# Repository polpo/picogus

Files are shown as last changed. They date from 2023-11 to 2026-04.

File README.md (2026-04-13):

# PicoGUS

PicoGUS Logo



ISA sound card and CD-ROM drive emulation on the Raspberry Pi Pico's RP2040 microcontroller. PicoGUS can emulate:

* [Gravis Ultrasound (GUS)](https://en.wikipedia.org/wiki/Gravis_Ultrasound) - the primary focus of PicoGUS, hence the name
* [Sound Blaster 16](https://en.wikipedia.org/wiki/Sound_Blaster_16) (OPL3) / [Sound Blaster Pro 2](https://en.wikipedia.org/wiki/Sound_Blaster#Sound_Blaster_Pro_2,_CT1600) (OPL3) / [AdLib](https://en.wikipedia.org/wiki/Ad_Lib,_Inc.) (OPL2)
* [MPU-401 (with intelligent mode)](https://en.wikipedia.org/wiki/MPU-401) - outputs MIDI data on 3.5mm MIDI TRS connector
* [Tandy 3-voice](http://www.vgmpf.com/Wiki/index.php?title=Tandy_3_Voice)
* [CMS/Game Blaster](http://nerdlypleasures.blogspot.com/2012/10/all-you-ever-wanted-to-know-about.html)
* [Game port joystick](https://en.wikipedia.org/wiki/Game_port)
* [Panasonic/MKE CD-ROM](https://en.wikipedia.org/wiki/Panasonic_CD_interface)

Current status: perpetual beta! See the [main wiki page](https://github.com/polpo/picogus/wiki) for current status and the [compatibility list](https://github.com/polpo/picogus/wiki/Compatibility-list) for support status of various DOS programs and other system compatibility notes. This project has a heavy demoscene focus due to the GUS's history so that's what I've concentrated on, but GUS support in games is very good to excellent.

Want to buy a PicoGUS? Fully assembled PicoGUS 2.0 sound cards are available from these sources, all of whom ship worldwide:

* [Joe's Computer Museum Shop](https://jcm-1.com/product/picogus-v2/) - in US 🇺🇸
* [Serdashop](https://www.serdashop.com/PicoGUS) - in EU 🇪🇺
* [Flamelily IT](https://shop.flamelily.co.uk/picogus) - in UK 🇬🇧

Want to make your own PicoGUS? See the [build guide](https://github.com/polpo/picogus/wiki/Building-your-PicoGUS). Note that the more DIY friendly v1.1.1 hardware has some documented issues with reset – a forthcoming v1.2 revision will fix these issues. **Important caveat**: due to the specs of the Pico, assumptions made by programs written to use the GUS, the imprecise nature of emulation, and the varying specs of retro DOS PC hardware, some things will likely never be perfect. **This is still a work in progress.**

Have a PicoGUS and want to use it? See the [configuring and using your PicoGUS guide](https://github.com/polpo/picogus/wiki/Configuring-and-using-your-PicoGUS).

Want to support PicoGUS? I have a limited number of machines to test PicoGUS in and donating either money or motherboards would be greatly appreciated and help increase the compatibility of PicoGUS.

You can donate via [PayPal](https://paypal.me/ianpolpo) or Ko-Fi: 

PicoGUS 2.0 PCB

PicoGUS v1.1 beta PCB

See/hear PicoGUS in action on YouTube:

Videos by others:

[](https://www.youtube.com/watch?v=08IPnmvuatw)
[](https://youtu.be/bBYUTwKRyNk)
[](https://youtu.be/oEHVB0FITqU)
[](https://youtu.be/aeejxbaAQ4g)
[](https://youtu.be/okSBZJwqVb8)

My videos:

[September 2022 update](https://youtu.be/h4iWSnTc9Ag)
[October 2022 update](https://youtu.be/CkJvkJVRscQ)
[December 2022 update](https://youtu.be/F5Zk_hHHkTg)
[January 2023 update](https://youtu.be/sOHTagrWcIE)
[March 2023 update](https://youtu.be/2LBXzy4Fus0)

## Open Source Credits

* [Raspberry Pi Pico C/C++ SDK](https://github.com/raspberrypi/pico-sdk)
* `pico_audio_i2s` from [pico-extras](https://github.com/raspberrypi/pico-extras)
* `stdio_async_uart` from [PicoCart64](https://github.com/kbeckmann/PicoCart64)
* `gus-x.cpp` adapted from [DOSBox-X](https://github.com/joncampbell123/dosbox-x)
* OPL/AdLib emulation from [rp2040-doom](https://github.com/kilograham/rp2040-doom) (based on [emu8950](https://github.com/digital-sound-antiques/emu8950))
* MPU-401 emulation adapted from [HardMPU](https://github.com/ab0tj/HardMPU) and [DOSBox-X](https://github.com/joncampbell123/dosbox-x)
* Tandy 3-voice emulation based on code contributed by [Aaron Giles](https://aarongiles.com/), adapted from [DREAMM](https://aarongiles.com/dreamm/) 
* CMS emulation based on code contributed by [Aaron Giles](https://aarongiles.com/), adapted from [DREAMM](https://aarongiles.com/dreamm/)
* USB support uses [TinyUSB](https://github.com/hathach/tinyusb) and [tusb_xinput](https://github.com/Ryzee119/tusb_xinput) with USB mass storage improvements by rppicomidi and wbcbz7.
* FAT drive support by [FatFS](https://elm-chan.org/fsw/ff/)

## License

The hardware portions of this repository (hw/ directory) are licensed under the CERN OHL version 2, permissive.

The software portions of this repository (sw/, pgusinit/ directories) as a collection are licensed under the GNU GPL version 2. Some files are individually dual-licensed under BSD or MIT licenses – see the license in the file headers for details.

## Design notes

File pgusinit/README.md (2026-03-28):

# PicoGUSinit

PicoGUSinit (also called pgusinit, after the program's .exe file) detects and
initializes a PicoGUS card. In GUS emulation mode, it should be used instead of
ULTRINIT.

For more info on PicoGUS, see https://picog.us/.

The board must be loaded with firmware before using it for the first time. See
https://github.com/polpo/picogus/wiki/Building-your-PicoGUS#programming-the-pico
for programming instructions if your card didn't come programmed. The `/flash
x` option to pgusinit can be used to upgrade firmware on a running PicoGUS.
Firmware files that comes with release:

* `picogus.uf2` - All modes are now in a single firmware. To switch between
  modes, use the `/mode x` option in pgusinit.
* `pg-ne2k.uf2` - Special firmware for NE2000/WiFi. Only works on PicoGUS
  Femto and PicoGUS v1.x boards with a Pico W installed.

pgusinit must be run with firmware it is compatible with. If run with an
incompatible firmware, pgusinit will complain about a protocol mismatch. One
exception to this is that pgusinit can be used to upgrade an older version of
firmware to a more recent version. For example, firmware v1.2.0, which is
normally incompatibile with pgusinit v3.0.0, can be upgraded to firmware
v2.0.0 with pgusinit v3.0.0.

## Using

Simply run `PGUSINIT.EXE` to detect and initialize your card with default
settings. Options may be given for other settings:

### Global options

* `/?` - shows help for PicoGUSinit. Detects the current card mode and only
  shows options valid for that mode.
* `/??` - shows help for PicoGUSinit for all modes.
* `/flash picogus.uf2` - uploads firmware in the file named picogus.uf2 to the
  PicoGUS. Used to upgrade firmware version.
* `/wtvol x` - sets wavetable header volume to x percent (PicoGUS 2.0 boards
  only).  Available in all modes in case you want to use the wavetable header
  as an aux input (for example for an internal CD-ROM drive).
* `/mainvol x` - sets main volume level for all outputs.
* `/mode x` - changes the card to mode specified by x. Options:
    - `gus`: Gravis Ultrasound
    - `sb`: Sound Blaster 2.0 & AdLib. Supports CD-rom emulation.
    - `mpu`: MPU-401 with intelligent mode and IRQ support
    - `psg`: Tandy 3-voice and CMS/Game Blaster. Supports USB serial mouse
      emulation.
    - `adlib`: AdLib only. Supports USB serial mouse emulation.
    - `usb`: Only emulates game port joystick and serial mouse via USB. Can be
      used if you don't want to emulate any sound cards. Supports CD-ROM
      emulation.
* `/save` - saves current settings to the card. Saved settings persist across
  reboots, meaning pgusinit does not need to be run. The card mode is also
  saved.
* `/defaults` - restores all card settings to defaults.
* `/joy 1|0` - enable USB joystick support with 1, disable with 0.

### GUS options

GUS emulation requires the ULTRASND variable to be set, in the format:

`set ULTRASND=240,1,1,5,5` where 240 is the PicoGUS's port, 1 is the DMA, and
5 is the IRQ. pgusinit will check that the port set on the PicoGUS matches the
port specified in ULTRASND.

* `/gusenv` - sets the base I/O port from ULTRASND variable.
* `/gusport x` - sets the base I/O port of the GUS to x. Defaults to 240.
* `/gusbuf n` - sets the audio buffer size to n samples. Defaults to 4 with a
  minimum of 1 and maximum of 256. Some programs require a different value to
  run properly. Going lower than 4 is not advisable.
* `/gusdma n` - sets the DMA interval to n microseconds. Games that use
  streaming audio over DMA work better with higher values. Doom, for example,
  runs well with a value of 10-12. Note that increasing this will slow sample
  loading. Set to 0 to use the GUS's default DMA interval handling, where the
  DMA interval is set by the program using it.
* `/gus44k 1|0` - setting to 1 enables fixed 44.1kHz output. Normally the GF1
  varies its output sample rate from 44.1kHz at 14 voices to 19.2kHz at 32
  voices. Using this option enables 44.1kHz output for all numbers of voices,
  similar to the Interwave. This will result in stuttering in most games that
  use streaming DMA for sound effects like Doom, hence it is EXPERIMENTAL.
* `/gusvol x` - sets the volume of the GUS output to x percent.

See the Compatibility List wiki for notes on programs that require special
settings for the above options:
https://github.com/polpo/picogus/wiki/Compatibility-list

### Sound Blaster/AdLib options

Sound Blaster emulation requires the BLASTER variable to be set, in the format:

`set BLASTER=A220 I5 D1 H1 T6`, where 220 is the PicoGUS's SB emulation port,
5 is the IRQ, 1 is the DMA, 6 is the emulated SB type (see `/sbtype` option)

* `/sbenv` - sets SB base port, IRQ, DMA and type from BLASTER variable.
* `/sbport x` - sets the base port of the Sound Blaster. Defaults to 220.
* `/sbirq x` - sets the IRQ of the Sound Blaster. Must match jumper settings.
* `/sbdma x` - sets the DMA of the Sound Blaster. Must match jumper settings.
* `/sbtype x` - sets the Sound Blaster type: Allowed values are:
  1 - SB 1.x,          2 - SB Pro 1 (dual OPL2), 3 - SB 2.0
  4 - SB Pro 2 (OPL3), 6 - SB 16
* `/oplport x` - sets the base port of the OPL/AdLib. Defaults to 388.
* `/oplwait` - wait on OPL2 data write. Can fix speed-sensitive early AdLib
  games on fast systems (example: 688 Attack Sub).
* `/sbvol  x` - sets the volume of the SB PCM output to x percent.
* `/oplvol x` - sets the volume of the OPL2 output to x percent.
* `/sbfixtc 1|0 ` - fix SB time constant for 11/22/44 kHz sample rate. Can fix
  PCM audio slightly pitched up or down in pre-SB16 games and applications.
  Note than certain programs are already aware of SB time constant inaccuracy
  and will sound wrong if this option is enabled. Default = 0 (disabled)
* `/sblockmixer n` - lock writes to SB mixer settings. Choices:
  0 - write lock disabled (default)
  1 - lock all but Voice Volume registers (for panning effects e.g. in Wolf3D)
  2 - lock all registers

### MPU-401 options

* `/mpuport x` - sets the base port of the MPU-401. Defaults to 330.
* `/mpudelay` - set to 1 to enable sysex delay to prevent buffer overflows on
  older MPU-401 revisions.
* `/mpufake` - set to 1 to fake all-notes-off for the Roland RA-50.

### Tandy options

* `/tandyport x` - sets the base port of the Tandy 3-voice. Defaults to 2c0.
* `/psgvol x` - sets the volume of the PSG output to x percent.

### CMS options

* `/cmsport x` - sets the base port of the CMS. Defaults to 220.
* `/psgvol x` - sets the volume of the PSG output to x percent.

### Serial mouse settings

Since a COM port requires an IRQ, serial mouse emulation is possible in modes
that do not require an IRQ: AdLib, CMS, Tandy, and USB.

* `/mousecom n` - mouse COM port. Default: 0, Choices: 0 (disable), 1, 2, 3, 4
* `/mouseproto n` - set mouse protocol. Default: 0 (Microsoft). Choices:
     0 - Microsoft Mouse 2-button,      1 - Logitech 3-button
     2 - IntelliMouse 3-button + wheel, 3 - Mouse Systems 3-button
* `/mouserate n` - set report rate in Hz. Default: 60, Min: 20, Max: 200.
  Increase for smoother cursor movement, decrease for lower CPU load
* `/mousesen n` - set mouse sensitivity (256 - 100%, 128 - 50%, 512 - 200%)

### CD-ROM emulation options

* `/cdport x` - set base port of CD interface. Default: 250, 0 to disable
* `/cdlist` - list CD images on the inserted USB drive
* `/cdload n` - load image n in the list given by /cdlist. 0 to unload image
* `/cdloadname x` - load CD image by name. Names with spaces can be quoted
* `/cdauto 1|0` - auto-advance loaded image when same USB drive is reinserted
* `/cdvol x` - sets the volume of the CD audio output to x percent.

## Compiling

PicoGUSinit can be compiled with OpenWatcom 1.9 or 2.0. Run `wmake` to compile.

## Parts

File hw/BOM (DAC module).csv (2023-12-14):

Mfr. # | Manufacturer | Qty | Mouser # | Digi-Key # | LCSC # | Customer # | Footprint | Description | Notes
CL31A476MPHNNNE | Samsung Electro-Mechanics | 2 | 187-CL31A476MPHNNNE | 1276-3063-1-ND | C96123 | C1,C2 | 0805 | 47 µF ±20% 10V Ceramic Capacitor X5R 1206 (3216 Metric) | Subst any 47uF electrolytic cap w/ 2mm lead spacing
CL21B105KBFNNNE | Samsung Electro-Mechanics | 1 | 187-CL21B105KBFNNNE | 1276-1029-1-ND | C28323 | C10 | 0805 | 1 µF ±10% 50V Ceramic Capacitor X7R 0805 (2012 Metric) | Subst any X7R 1uF 0805 ceramic cap
CL21B104KCFNNNE | Samsung Electro-Mechanics | 8 | 187-CL21B104KCFNNNE | 399-C0805C104M5RAC7800CT-ND | C28233 | C3,C4,C5,C6,C7,C8,C9,C11 | 0805 | 0.1 µF ±10% 100V Ceramic Capacitor X7R 0805 (2012 Metric) | Subst any X7R 0.1uF 0805 ceramic cap
B5819W-TP | Micro Commercial Components | 1 | 833-B5819W-TP | B5819W-TPMSCT-ND | C8598 | D1 | SOD-123 | 40V 600mV@1A 1A SOD-123 Schottky Barrier Diodes (SBD) | Subst any 1A 20V Schottky SOD123 diode
M20-9771246 | Harwin | 1 | 855-M20-9771246 | M20-9771246-ND | C2840012 | I2S_DAC1,J4,J7 |  | Headers & Wire Housings 12 SIL VERTICAL PIN HEADER TIN | Cut into 6, 4, 2 pin sections
10129381-918001BLF | FCI / Amphenol | 1 | 649-1012938191801BLF | 609-10129381-918001BLF-ND | C2935925 | J1 | PinHeader_2x09_P2.54mm_Vertical | Headers & Wire Housings HEADER DR VT TH 2X9-10129381-918001BLF | Subst any 2x9 2.54mm pin header
SJ1-3535NG | CUI Devices | 1 | 490-SJ1-3535NG | CP1-3535NG-ND | C5372857 | J5 | Jack_3.5mm_CUI_SJ1-3535NG_Horizontal | 3.50mm (0.141", 1/8", Mini Plug) - Headphone Phone Jack Stereo (3 Conductor, TRS) Connector Solder | Black jack for MIDI - Yellow jacks on AliExpress, search PJ-325
PH1-02-UA | Adam Tech | 1 | 649-54102-T0800LF | 2057-PH1-02-UA-ND | C2883961 | J7 | PinHeader_1x02_P2.54mm_Vertical | Connector Header Through Hole 2 position 0.100" (2.54mm)
SJ1-3535NG-GR | CUI Devices | 1 | 490-SJ1-3535NG-GR | SJ1-3535NG-GR | C692438 | J8 | Jack_3.5mm_CUI_SJ1-3535NG_Horizontal | 3.50mm (0.141", 1/8", Mini Plug) - Headphone Phone Jack Stereo (3 Conductor, TRS) Connector Solder, green | Green jack for line out
BLM21AG102SN1D | Murata Electronics | 2 | 81-BLM21AG102SN1 | 490-1041-1-ND | C85835 | FB1,FB2 | 0805 | 1 kOhms @ 100 MHz 1 Ferrite Bead 0805 (2012 Metric) 600mA 280mOhm | Subst any 1kOhm @ 100Mhz 0805 ferrite bead
CR0805-JW-102ELF | Bourns | 1 | 652-CR0805JW-102ELF | CR0805-JW-102ELFCT-ND | C17513 | R1 | 0805 | 1 kOhms ±5% 0.125W, 1/8W Chip Resistor 0805 (2012 Metric) Moisture Resistant Thick Film | Subst any 1kOhm 0.125w 0805 resistor
CR0805-JW-153ELF | Bourns | 3 | 652-CR0805JW-153ELF | 118-CR0805-JW-153ELFCT-ND | C17475 | R2,R5,R6 | 0805 | 15 kOhms ±5% 0.125W, 1/8W Chip Resistor 0805 (2012 Metric) Moisture Resistant Thick Film | Subst any 15kOhm 0.125w 0805 resistor
RK73B2ATTD221J | KOA Speer | 2 | 660-RK73B2ATTD221J | 2019-RK73B2ATTD221JCT-ND | C5120092 | R3,R4 | 0805 | 220 Ohms ±5% 0.25W, 1/4W Chip Resistor 0805 (2012 Metric) Automotive AEC-Q200 Thick Film | Subst any 220Ohm 0.25w 0805 resistor
CR0805-JW-471ELF | Bourns | 2 | 652-CR0805JW-471ELF | 118-CR0805-JW-471ELFCT-ND | C17710 | R7,R8 | 0805 | 470 Ohms ±5% 0.125W, 1/8W Chip Resistor 0805 (2012 Metric) Moisture Resistant Thick Film | Subst any 470Ohm 0.125w 0805 resistor
SC0915 | Raspberry Pi | 1 | 358-SC0915 | 2648-SC0915CT-ND | C2905423 | U1 |  | Single Board Computers Raspberry Pi Pico | Pico W and Pico H also work
74LVC244APW,118 | Nexperia | 1 | 771-74LVC244APW-T | 1727-2875-1-ND | C6079 | U2 | TSSOP-20 | Buffer, Non-Inverting 2 Element 4 Bit per Element 3-State Output 20-TSSOP
SN74CB3T3257 | Texas Instruments | 2 | 595-SN74CB3T3257PWR | 296-17850-1-ND | C544573 | U3,U4 | TSSOP-14 | Encoders, Decoders, Multiplexers & Demultiplexers 4-Bit 1-OF-2 FET Mltplx/Demultplxr
74AHC14S14-13 | Diodes Incorporated | 1 | 621-74AHC14S14-13 | 31-74AHC14S14-13CT-ND | C6942 | U5 | SOIC-14 | Inverter IC 6 Channel Schmitt Trigger 14-TSSOP | Subst any 74LVC14
74LVC00AS14-13 | Diodes Incorporated | 1 | 621-74LVC00AS14-13 | 31-74LVC00AS14-13CT-ND | C526338 | U6 | SOIC-14 | NAND Gate IC 4 Channel 14-SO | Subst any 74LVC00
SN74LVC1G00DBVR | Texas Instruments | 1 | 595-SN74LVC1G00DBVR | 74LVC1G00W5-7DICT-ND | C7826 | U7 | SOT-23-5 | Logic Gates 2-Input | Subst any 74LVC1G00
APS6404L-3SQR-SN | AP Memory Technology | 1 | 878-APS6404L-3SQR-SN | 1528-4677-ND | C139966 | U8 | SOIC-8 | DRAM IoT RAM 64Mb QSPI (x1,x4) SDR 133/84MHz, RBX, 3V, Ind. Temp., SOP8 | Subst Adafruit 4677, Vilsion Tech VTI7064MSME, ISSI IS66WVS1M8BLL-104NLI, IPUS IPS6404, Lyontek LY68L6400SLIT, Espressif ESP-PSRAM64H
SN74LVC2G06DBVR | Texas Instruments | 1 | 595-SN74LVC2G06DBVR | 296-13492-1-ND | C402162 | U10 | SOT-23-6 | Buffers & Line Drivers Single Invert w/OD | Subst any 74LVC1G06

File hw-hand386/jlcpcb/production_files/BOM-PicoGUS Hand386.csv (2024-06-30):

Comment | Designator | Footprint | LCSC
1K | R8 | R_0402_1005Metric | C11702
2.2uF | C11,C12 | C_0402_1005Metric | C12530
PCM5100 | U10 | TSSOP-20_4.4x6.5mm_P0.65mm | C131154
74AHC14 | U5 | TSSOP-14_4.4x5mm_P0.65mm | C138310
0.1uF | C13,C14,C15,C16,C20,C3,C4,C5,C6,C7,C8,C9 | C_0402_1005Metric | C1525
SN74CB3T3245 | U2 | TSSOP-20_4.4x6.5mm_P0.65mm | C15298
2.2nF | C18,C19 | C_0402_1005Metric | C1531
33 | R4 | R_0805_2012Metric | C161967
10uF | C17 | C_0603_1608Metric | C19702
470 | R5,R6 | R_0402_1005Metric | C25117
10K | R1,R2,R7 | R_0402_1005Metric | C25744
APS6404L-3SQN-SN | U8 | SOIC-8_3.9x4.9mm_P1.27mm | C3028887
1K @ 100MHz | FB1,FB2 | L_0603_1608Metric | C50069
1uF | C10 | C_0402_1005Metric | C52923
SN74CB3T3257 | U3,U4 | TSSOP-16_4.4x5mm_P0.65mm | C544573
AudioJack3 | J5 | PJ-231F-4A | C707219
10 | R3 | R_0805_2012Metric | C728003
74LVC00 | U6 | TSSOP-14_4.4x5mm_P0.65mm | C7803
74LVC1G00 | U7 | SOT-23-5 | C7826
74LVC1G06 | U9 | SOT-23-5 | C840103
1A 20V Schottky | D1 | D_SOD-123 | C8598
AudioJack3 | J1 | PJ-321A | C879743
47uF | C1,C2 | C_1206_3216Metric | C96123
Bus_ISA_8bit | J3 | EDGE-60

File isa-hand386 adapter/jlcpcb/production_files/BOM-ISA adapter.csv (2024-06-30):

Comment | Designator | Footprint | LCSC
1K | R1,R2,R3,R4 | R_0805_2012Metric | C17513
10K | RV1 | RK10J12R0A0B | C351175
100nF | C1 | C_0805_2012Metric | C49678
74HC14 | U1 | SOIC-14_3.9x8.7mm_P1.27mm | C5605
Bus_ISA_8bit | J3 | BUS_PC
MountingHole_3.2mm_M3_Pad | H1 | MountingHole_3.2mm_M3_ISO14580_Pad
Conn_02x30_Odd_Even | J1 | Hand386_PicoGUS
IRQDMA_JP | J4 | PinHeader_2x09_P2.54mm_Vertical
MountingHole_3.2mm_M3_Pad | H2 | MountingHole_3.2mm_M3_ISO14580_Pad
AudioJack3 | J6 | Jack_3.5mm_CUI_SJ1-3535NG_Horizontal
Wavetable | J5 | Wavetable

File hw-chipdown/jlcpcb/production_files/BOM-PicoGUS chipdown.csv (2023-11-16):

Comment | Designator | Footprint | LCSC
100Ω@100MHz | FB3,FB4 | L_0805_2012Metric | C1015
1k | R12,R14,R4,R6,R7,R8,R9 | C_0402_1005Metric | C11702
2.2uF | C18,C19 | C_0402_1005Metric | C12530
PCM5100 | U10 | TSSOP-20_4.4x6.5mm_P0.65mm | C131154
AO3401A | Q1 | SOT-23 | C15127
0.1uF | C14,C15,C16,C2,C20,C23,C26,C27,C28,C3,C30,C32,C33,C34,C35,C36,C37,C4,C45,C5,C6,C7,C8,C9 | C_0402_1005Metric | C1525
SN74CB3T3245 | U7 | TSSOP-20_4.4x6.5mm_P0.65mm | C15298
1KΩ@100MHz | FB1,FB2 | L_0805_2012Metric | C155073
1uF | C10 | C_0603_1608Metric | C15849
10u | C12,C13,C17 | C_0805_2012Metric | C15850
2.2nF | C21,C22 | C_0603_1608Metric | C1604
30pF | C24,C25 | C_0603_1608Metric | C1658
D_Schottky | D2 | D_SOD-323_HandSoldering | C191023
RP2040 | U12 | QFN-56-1EP_7x7mm_P0.4mm_EP3.2x3.2mm_ThermalVias | C2040
USB_A - joy | J5 | USB-A_902-131A1011D10100 | C2345
27 | R15,R16 | C_0402_1005Metric | C25100
470 | R10,R11,R13 | R_0402_1005Metric | C25117
10K | R1,R5 | R_0402_1005Metric | C25744
15K | R17,R18 | R_0402_1005Metric | C25756
APS6404L-3SQR-SN | U8 | SOIC-8_3.9x4.9mm_P1.27mm | C261881
3.5mm TRS | J7 | Jack_3.5mm_CUI_SJ1-3535NG_Horizontal | C2910528
Wavetable | J8 | Wavetable | C358701
USB_B_Micro - program | J6 | USB-microB_U254-051T-4BH83-F1S | C397452
2.2uF | C39,C40,C41,C42,C43,C44 | CP_Elec_4x5.4 | C445039
IRQDMA_JP | J3 | PinHeader_2x09_P2.54mm_Vertical | C492426
220 | R2,R3 | R_0805_2012Metric | C5120092
1u | C29,C31 | C_0402_1005Metric | C52923
SW_Push | SW1 | SW_SPST_TL3305A | C5342982
SN74CB3T3257 | U1,U2 | TSSOP-16_4.4x5mm_P0.65mm | C544573
74LVC2G06 | U6 | SOT-363_SC-70-6 | C548560
AMS1117-3.3_SOT223 | U9 | SOT-223-3_TabPin2 | C6186
M62429L | U13 | SOIC-8_3.9x4.9mm_P1.27mm | C668666
3.5mm TRS | J9 | Jack_3.5mm_CUI_SJ1-3535NG_Horizontal | C692438
LED | D1 | LED_0603_1608Metric | C72038
74AHC14 | U3 | TSSOP-14_4.4x5mm_P0.65mm | C7460
Polyfuse | F1 | Fuse_1206_3216Metric | C75464
74LVC00 | U4,U5 | TSSOP-14_4.4x5mm_P0.65mm | C7803
W25Q128JVS | U11 | SOIC-8_5.23x5.23mm_P1.27mm | C82317
ABLS-12.000MHZ-B4-T | Y1 | Crystal_SMD_3225-4Pin_3.2x2.5mm | C9002
47uF | C1,C11,C38 | C_1206_3216Metric | C96123

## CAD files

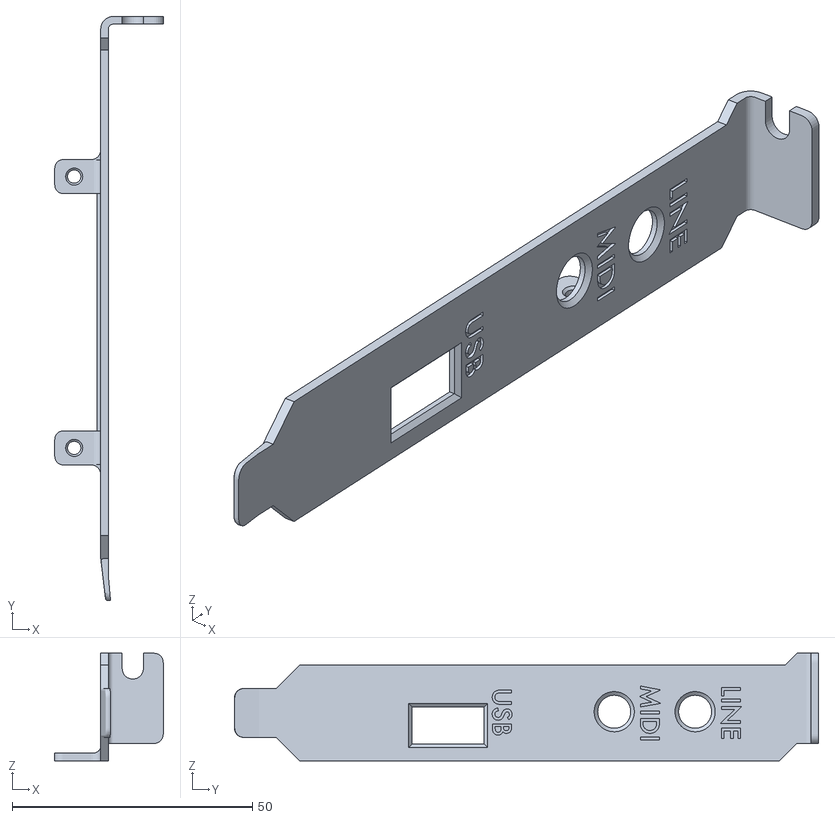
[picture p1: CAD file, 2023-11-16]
hw-chipdown/bracket/picogus 2.0 3D printed bracket.stl
22.6 x 121.7 x 22.4

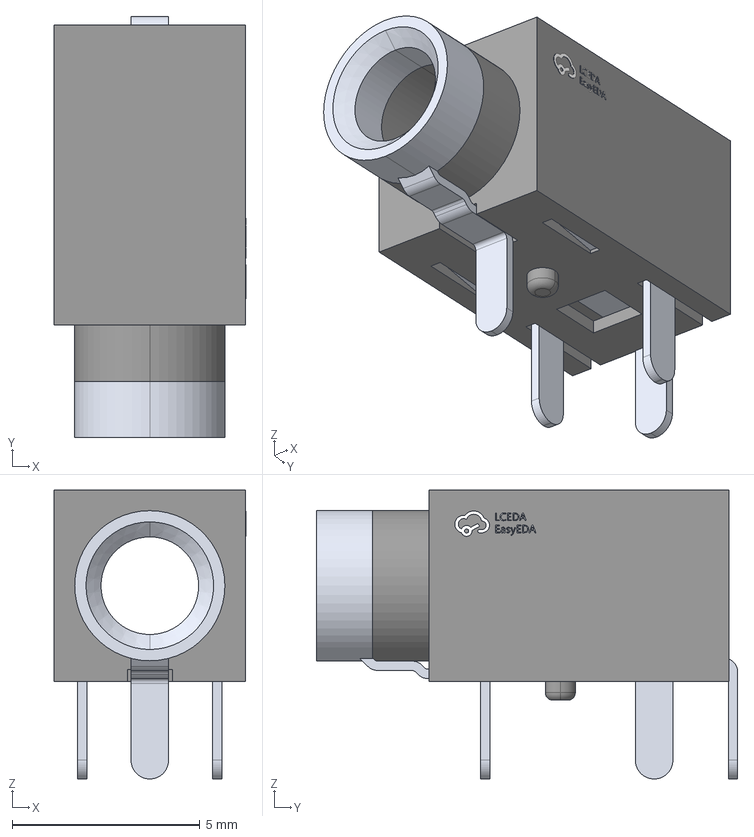
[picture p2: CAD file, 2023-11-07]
hw-common/parts/PJ-210B.step
5.11 x 11.2 x 7.70 mm

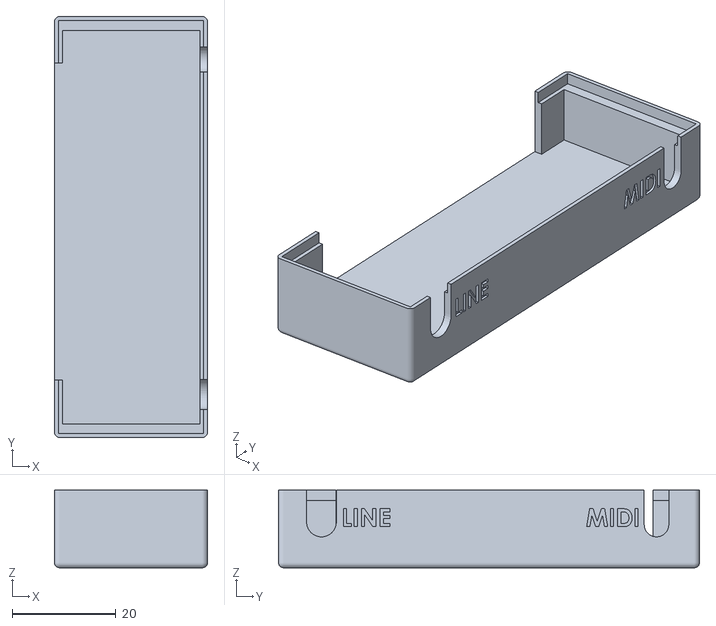
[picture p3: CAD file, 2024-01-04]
hw-hand386/picogus_hand_bottom_v2.STL
29.5 x 81.3 x 15.0

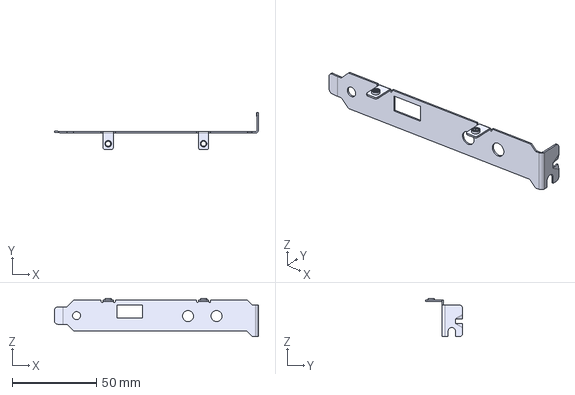
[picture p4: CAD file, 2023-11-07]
hw-chipdown/bracket/picogus 2.0 sheet metal bracket.step
120.9 x 22.2 x 22.7 mm

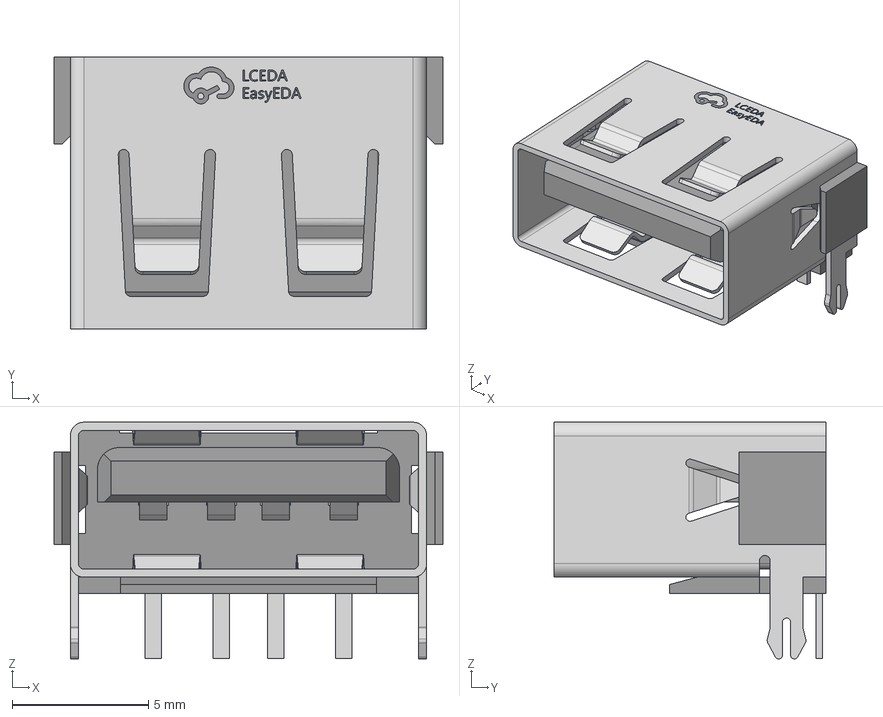
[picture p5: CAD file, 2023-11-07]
hw-common/parts/USB-A_AF 10.0 HC6.3.step
14.3 x 10.00 x 8.70 mm

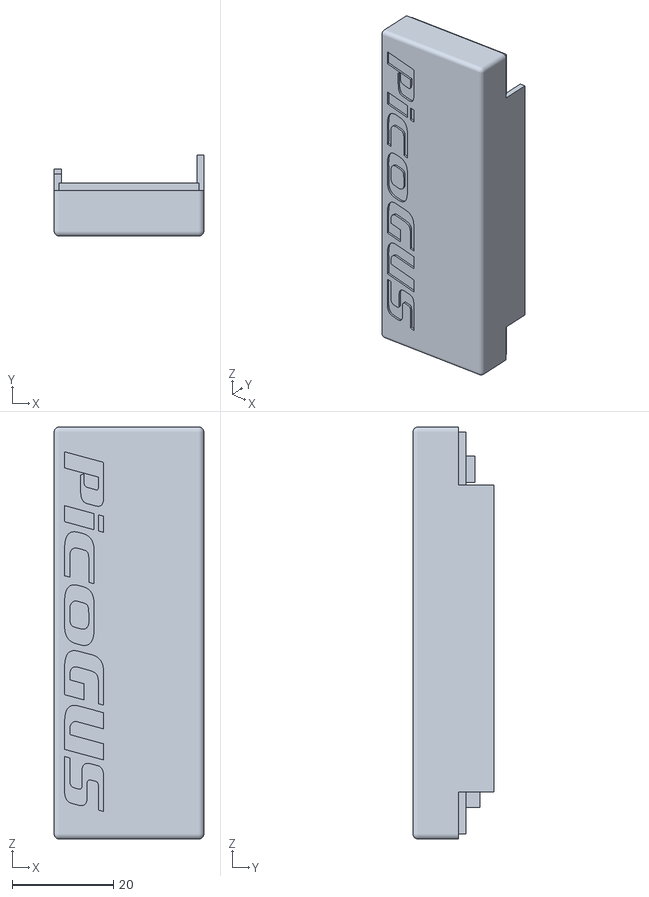
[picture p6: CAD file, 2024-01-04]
hw-hand386/picogus_hand_top_v2.STL
29.5 x 16.0 x 81.3

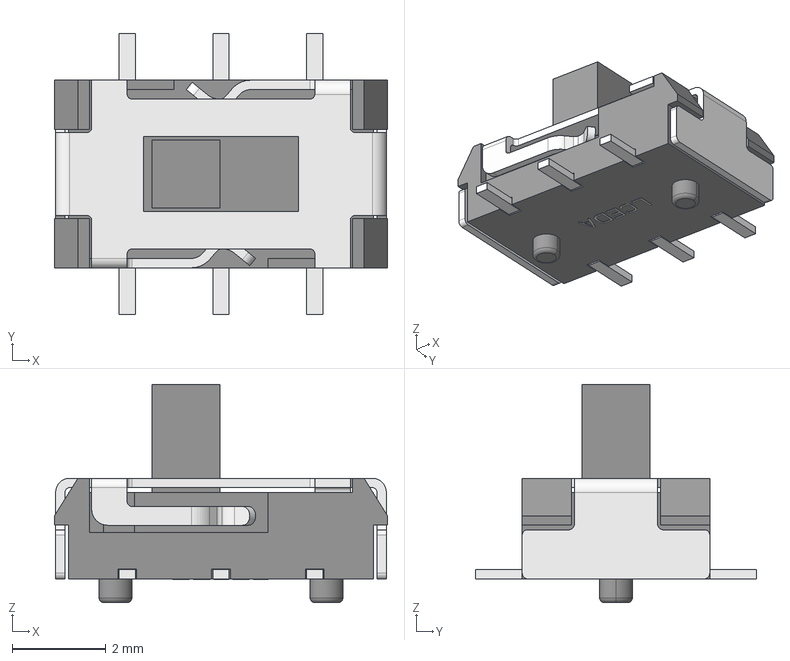
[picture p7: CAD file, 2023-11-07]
hw-common/parts/SWITCH_MS-22D28-G020.step
7.10 x 6.00 x 4.65 mm

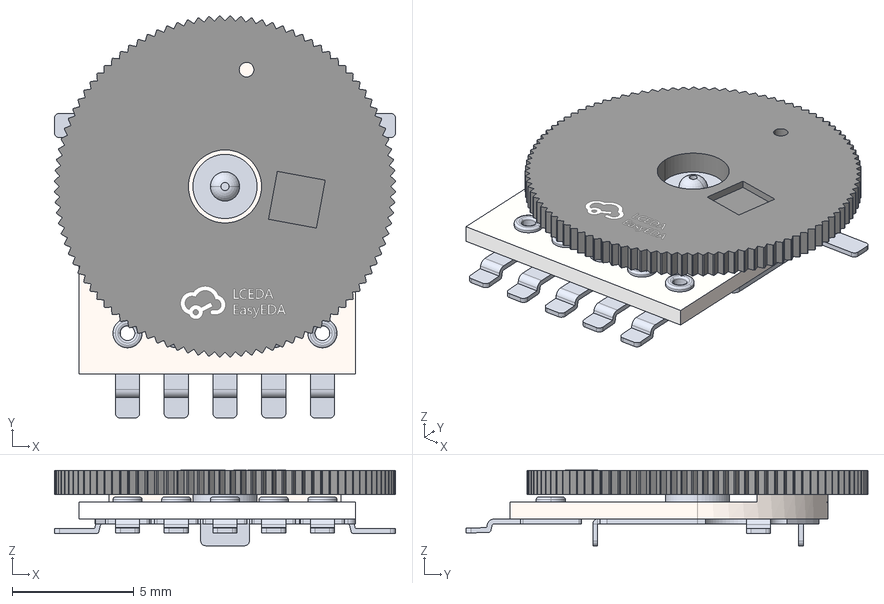
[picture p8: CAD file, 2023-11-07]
hw-common/parts/RK10J12R0A0B.step
14.0 x 16.5 x 3.10 mm

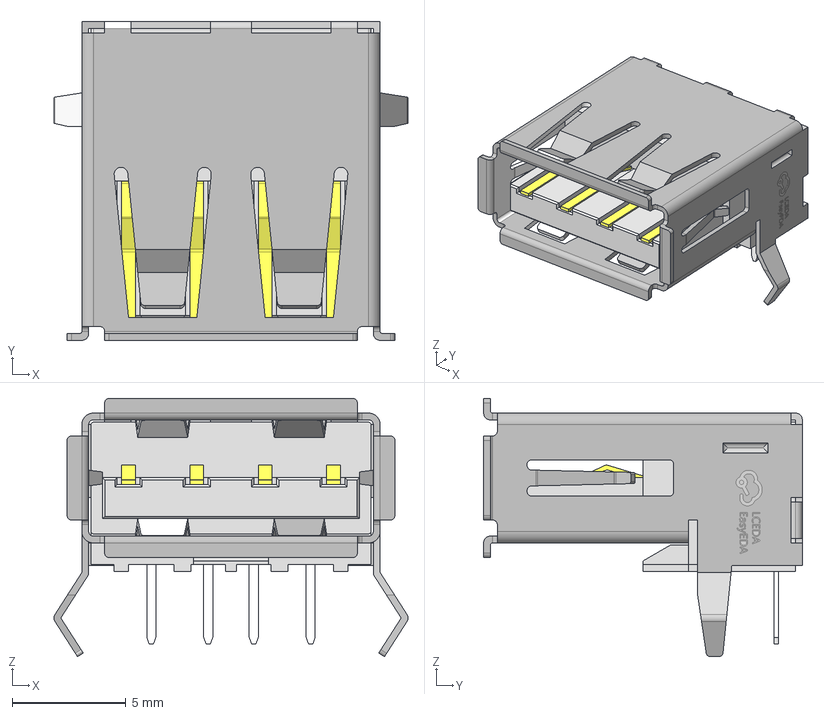
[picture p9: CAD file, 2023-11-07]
hw-common/parts/USB-A_902-131A1011D10100.step
15.5 x 14.0 x 11.3 mm

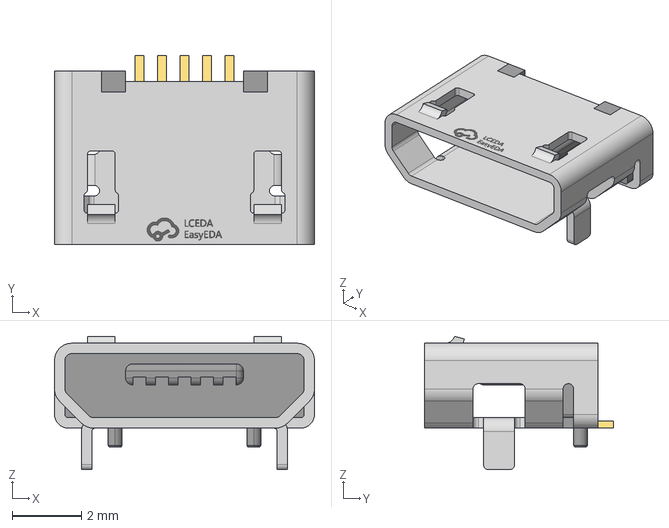
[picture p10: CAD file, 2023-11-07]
hw-common/parts/USB-microB_U254-051T-4BH83-F1S.step
7.50 x 5.45 x 3.85 mm

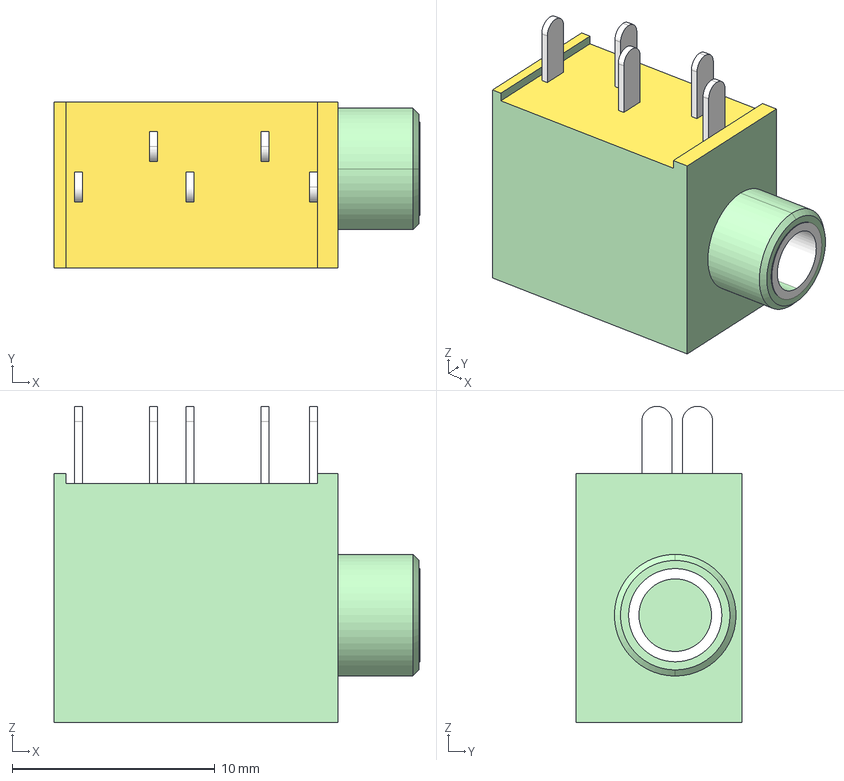
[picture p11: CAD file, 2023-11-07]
hw-common/parts/CUI_DEVICES_SJ1-3535NG-G.step
18.1 x 8.20 x 15.6 mm

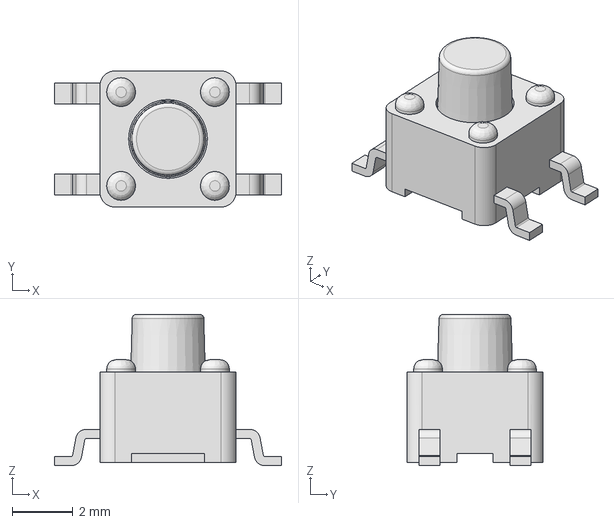
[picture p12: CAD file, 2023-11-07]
hw-common/parts/TL3305BFxxxxG.stp
7.50 x 4.50 x 5.00 mm

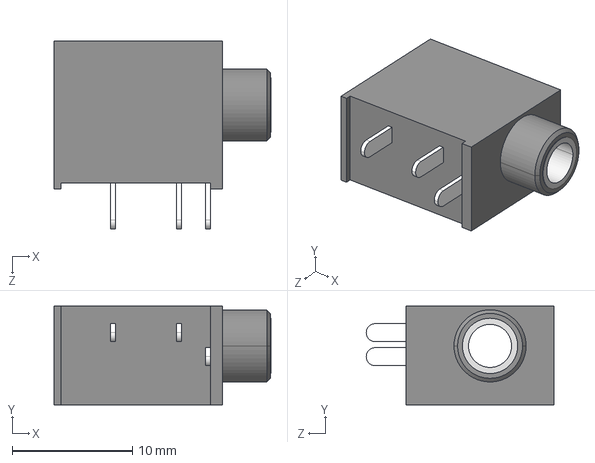
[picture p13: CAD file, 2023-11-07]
hw-common/parts/CUI_DEVICES_SJ1-3533NG.step
18.1 x 8.20 x 15.6 mm

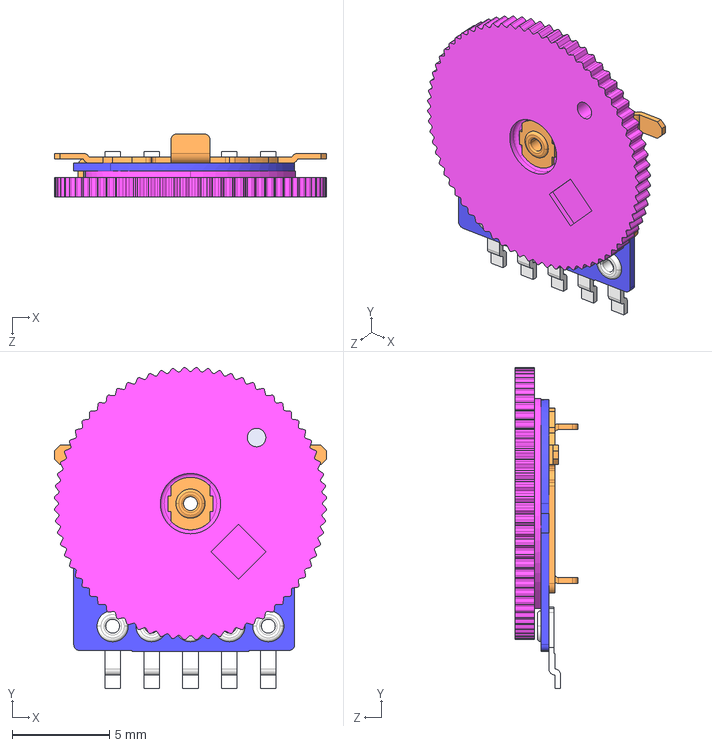
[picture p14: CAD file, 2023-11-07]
hw-common/parts/RK10J1_R.STEP
14.0 x 16.5 x 3.25 mm

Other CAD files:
hw-common/parts/keystone-9202-maxconnector.step
hw-common/parts/ISA adapter bracket v4.step
hw-common/parts/SBH21-_ _ _N-D30-RA-_ _.STEP
hw-common/parts/keystone-PN9202.STEP
hw-common/parts/CUI_DEVICES_SJ-3523-SMT-TR.step
hw-common/parts/CUI_DEVICES_SJ1-3535NG-BE.step
hw-common/parts/RK09712_0-L20-short.step
hw-common/parts/RK09712_0-L20.STEP
hw-common/parts/RK10J12R0A0B.stp
hw-common/parts/Unnamed1-Cube.step
hw-common/parts/keystone-PN9202-1.STEP

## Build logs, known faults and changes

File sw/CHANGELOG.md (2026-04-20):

# v4.1.1

## Fixes/improvements

Fixes major issues in v4.1.0 where stale printf code in modes would cause the firmware to panic.

### SB mode

- Fixes clicks during single-cycle DMA audio playback.

### GUS mode

- Fixes one of the longest-lived bugs in GUS mode: playmidi in the GUS DOS software package now works!

# v4.1.0

## Fixes/improvements

### SB mode

- Sound Blaster ADPCM playback is now supported (4, 2.6, and 2-bit modes). This allows for sound effects in Duke Nukem 2 without needing to patch the game. Thanks to [Tube Time (@schlae)'s annotated disassembly of the SB DSP firmware](https://github.com/schlae/sb-firmware/tree/master) and [Torsten Stremlau (@TerrySoba)'s VocTool](https://github.com/TerrySoba/VocTool) for an MIT-licensed C implementation to use as a basis.
- Sample rates >44100Hz are now supported, for example 45454Hz, the fastest supported by SB16.
- SBMIDI is supported in addition to MPU-401 in SB mode.
- Fake ADC (recording) is supported. This records garbage data but should help SB16 sound card detection in some OSes.
- Fixes bug in passing DMA from BLASTER variable when running pgusinit. Thanks @andreacampanella for the fix in PR #134.
- More helpful error messages when the BLASTER variable does not match the port/IRQ/DMA settings stored on the PicoGUS.

### MPU-401

- Behavior of the MPU-401 emulation is now much more in line with a real MPU-401: it has a 256 byte ring buffer for MIDI out data, and flow control is done via bit 6 of the status port. Previously, MPU support had no flow control and used a pretty enormous buffer to make up for that. The SRAM savings from the smaller buffer will allow for more PicoGUS features in the future.
- Sysex delay is now accurately calculated (we were using microseconds, not milliseconds).
- Re-introduces the song change fix for Frederik Pohl's Gateway.

### CD-ROM

- Read multiple sectors at a time during CD audio playback. Should help with pops/distortion on marginal USB drives.
- Fixes loading .iso images in Win9x w/ MKEPanasonic driver by handling lead-out.
- The loaded image is printed after a successful `pgusinit /cdload`.

### General

- SRAM usage is saved across the board by completely eliminating debug prints in release builds, as well as eliminating use of sscanf() type functions. These debug prints didn't go anywhere in release builds (since the UART is taken by MIDI out, and USB by joystick), but they still had runtime overhead in calling printf(), etc.

# v4.0.0

## New features/changes

### Sound Blaster 16

SB mode now emulates a Sound Blaster 16. I had a somewhat-working implementation of the SB16 DSP in late 2024 but was discouraged by poor compatibility in Windows. Recently the ISA analyzer firmware (see below) gave me an easier way to compare PicoGUS to how a real SB16 behaves when detected by Windows and fix the long-standing bugs. Massive thanks to [Artem Vasilev (wbcbz7)](https://github.com/wbcbz7) who implemented proper mixer support and implemented a ton of additional fixes, including support for DMA controller demand mode, all of which made SB16 and SBPro support truly usable.

OPL3 support is provided by the dbopl OPL3 emulator (this was the default OPL3 emulator in DOSbox until somewhat recently). The previous emu8950 OPL2 emulator is still available in Adlib mode, and has some improvements thanks to [Daniel Arnold (Delphius)](https://github.com/RetroLoom): fixes to timer 2 and disabling of some of the optimizations made to emu8950 for rp2040-doom that affect sound quality. Delphius also experimented with Aaron Giles's [ymfm](https://github.com/aaronsgiles/ymfm) for OPL2/OPL3 emulation but it has some issues with RAM and CPU usage so it's not used for now.

Because PicoGUS is an 8-bit card, it does not support high DMA. This is actually a mostly-supported configuration for SB16: several versions could be jumpered to disable high DMA, and the Creative Vibra 16X/16XV does not support high DMA at all. Almost all SB16-supporting software is fine working without high DMA, or configuring the same DMA channel for both low and high DMA.

SB mode also supports Sound Blaster Pro stereo properly and still supports SB 2.0. `pgusinit` can be used to set the DSP version reported by PicoGUS. The Line In channel in the SB mixer also controls the volume of the wavetable header.

### ISA analyzer firmware

PicoGUS now has an ISA analyzer firmware that captures and logs ISA bus activity. This was inspired by the IDE analyzer firmware I wrote for PicoIDE. Having a tool like this brings a ton of insight into what's going on in the bus. Note that this firmware is made for the PicoGUS 1.x board with the RP2350-based Pico 2 or Pimoroni Pico Plus 2.

## Fixes/improvements

### CD-ROM support

- The stock Win9x MKEPanasonic driver can now be used with PicoGUS. This driver does not peg the CPU like the Creative driver, which should give much more acceptable performance. Credit to 86Box as a reference for this fix.
- CD-ROM speed in SB mode is even faster again - I've gotten speeds between 3.75X and 4.75X in DOS.
- Lots of general fixes & improvements to CD-ROM support, thanks to [Daniel Arnold (Delphius)](https://github.com/RetroLoom): protocol correctness fixes, pgusinit /cdlist stability, CUE parsing, and larger CD audio buffer.

### GUS mode

- The audio rendering in GUS mode is now interrupt-driven like SB mode. This allows for finer grained handling of IRQs which should help random freezes in GUS titles, and frees up CPU to allow more titles to work with forced 44.1kHz sampling rate.
- Fixes volume ramp rate calculation in force 44.1kHz mode.
- Fixes a race condition when updating volume ramp, again helping random freezes.

### General

- Reverted back to the pre-v3.2.0 method of overclocking the RP2040. This should hopefully fix the "doesn't come back after changing modes" issue reported by some people.

# v3.2.1

## Fixes/improvements

### pgusinit

Fixes several regressions in pgusinit:

- Fixes issue where port settings are parsed as decimal, not hex (fixes /mpuport, /gusport, /cdport, etc.)
- Fixes /sbport and /gusport commands not passing through option
- Fixes /wifistatus command
- Restores /defaults command

### General

- Gives VREG a bit more time to settle at bootup/reset. Should improve stability on initial poweron, after changing modes, or flashing firmware.

# v3.2.0

## Fixes/improvements

### General

- Settings saved in flash with `pgusinit /save` are now preserved when upgrading to a firmware version that introduces new settings
- Volume control is now available for all sources. For example, in SB mode, the SB DSP, OPL2, and CD-ROM audio volumes can be independently controlled. Thanks to [Daniel Arnold (Delphius)](https://github.com/RetroLoom) for contributing this!
- DualShock 4 gamepad support has been fixed

### SB mode

Sound Blaster playback has been almost completely rewritten, removing a major bottleneck and freeing up way more CPU time.

- Crashing on titles with simultaneous SB DSP & OPL2 fixed
- High-quality assembly optimized FIR polyphase resampler for much better sounding OPL2 output. Huge thanks to [korneliuszo](https://github.com/korneliuszo/) for contributing this and other optimizations!
- Direct DAC mode is back after being dropped in firmware v3.0.0
- Too-slow MPU-401 output in SB mode fixed (main symptom was long delay until music starts in Sierra titles)
- CD-ROM speed now faster in SB mode - improved from 2x to 3x

### pgusinit

pgusinit has been almost completely refactored, thanks again to [Daniel Arnold (Delphius)](https://github.com/RetroLoom). It not only helps future maintainability but brings new quality of life features:

- Long output like CD image listing and extended help text now pauses instead of scrolling off the screen
- Progress bar when flashing firmware instead of filling the screen with dots
- More helpful text if there are missing arguments
- Values can be set back to their default values with a `default` argument. Example: `pgusinit /cdport default`
- Added support for volume control via commands like /sbvol, /cdvol, etc.

# v3.1.0

## Fixes

### CD-ROM emulation

Many fixes/improvements to CD image handling:

- Add ability to load image by name
- Fix memory leak when changing images (file handle not freed, causing crash after switching images several times)
- Less memory usage all over
- Longer max file length limit (127 chars)
- Better errors when USB not present
- Fix polling of CD status register when listing images
- Many weird edge cases with image loading state fixed

# v3.0.1

## Fixes

### SB and USB modes

Fixes MPU-401 output in SB and USB modes. It was broken by the introduction of CD-ROM emulation in SB mode and it never actually worked in USB mode!

# v3.0.0

## New features/changes

### CD-ROM emulation

PicoGUS now supports CD-ROM emulation (in other words, PicoGUS is now an ODE)! It emulates a [Panasonic/MKE interface and drive](https://en.wikipedia.org/wiki/Panasonic_CD_interface) and supports CD images in ISO or BIN/CUE stored on a USB drive plugged into the USB port on the PicoGUS. CD-ROM emulation has been tested in DOS and Windows 9x and CD audio playback is fully supported.

CD-ROM emulation is available in Sound Blaster and USB modes. Sound Blaster mode really pushes the limit of the RP2040: it mixes CD audio, SB DSP, and OPL sound while simultaneously supporting CD data and MPU-401 emulation. The emulated drive is approximately 2x speed in SB mode and 3x-4x speed in USB mode. Disc images can be swapped on the fly with pgusinit, and multi-disc games are supported by removing and reinserting the USB drive to advance the current disc image.

For more information and a guide on how to use CD-ROM emulation on PicoGUS with recommended drivers, known limitations, etc., visit the new [CD-ROM emulation wiki page](https://github.com/polpo/picogus/wiki/CD%E2%80%90ROM-Emulation).

Massive thanks to [Kevin Moonlight (yyzkevin)](https://github.com/yyzkevin) for reverse engineering the Panasonic/MKE interface and contributing the bulk of the underlying code for this emulation.

Also major thanks to [rppicomidi](https://github.com/rppicomidi) for greatly improving mass storage speed for the RP2040 in TinyUSB and [Artem Vasilev (wbcbz7)](https://github.com/wbcbz7) for additional fixes and rebasing on a more recent state of the repository. Without their work, USB mass storage would not be nearly fast enough to support CD-ROM emulation on the RP2040. These improvements are still not merged into the upstream project, so here's hoping that can be completed.

And thanks to all who tested this firmware before release to surface bugs and edge cases I wouldn't have been able to find myself. Cue sheets are the wild west of formats!

### Tandy/CMS modes combined into new PSG (programmable sound generator) mode

To reduce firmware size and prepare for future support for other [PSG sound chips](https://en.wikipedia.org/wiki/Programmable_sound_generator) (here's a hint, it's the [AY-3](https://en.wikipedia.org/wiki/General_Instrument_AY-3-8910) as used on the [Mindscape Music Board](https://www.youtube.com/watch?v=Eeo4INoGyRY)), Tandy and CMS modes have been combined into a single PSG mode. It can be selected with `pgusinit /mode psg`, but the old `/mode tandy` and `/mode cms` switches still work for backwards compatibility.

## Fixes

### pgusinit

When pgusinit couldn't detect a PicoGUS, it would erroneously continue trying to configure the card. This would result in a strange firmware version mismatch error. This has now been fixed.

## Known issues

### Sound Blaster mode

Due to the addition of CD-ROM emulation to SB mode, SB DSP audio now runs through a FIFO. This may result in some playback issues that are being worked on. Also "Direct DAC" mode (mostly used by older titles) is not currently supported.

### General

Due to the addition of new settings, any saved settings done with `/pgusinit save` on previous firmware versions will be reset to defaults when upgrading to firmware v3.0.0.

# v2.2.0

## New features/changes

### NE2000 emulation/WiFi

*Please note* that this mode is not supported on PicoGUS 2.0! It needs a v1.1, v1.2, or Femto version of the PicoGUS that takes a Raspberry Pi Pico and requires a Pico W! I made this mode mainly just so I could use WiFi on my Pocket386 with a Femto card plugged into it. At least for now, NE2K mode comes in its own separate firmware file (`pg-ne2k.uf2`) and no other emulation is enabled when this firmware is loaded. Due to this limitation and the fact that the PCB design of the PicoGUS 1.x is not ideal for WiFI reception, consider this mode just a bit of a nice bonus. Config options have been added to pgusinit for NE2000 and WiFi SSID/password settings.

## Fixes

### Sound Blaster 2.0 emulation

* Fixes detection in Windows 9x, allowing SB mode to work in Windows 9x. Thanks to Ian Hanschen (@ianhan) for contributing the fix.
* Fixes detection in Tyrian and Dig-It! Thanks again to Ian Hanschen for the fix.
* Fixes detection in STMIK-based demos (Mental Surgery by Future Crew, SX by Substance, Min Monitor Briner by Syntax Error, probably others)

### GUS emulation

* Fixes intelligent mode MIDI buffer overrun and slow MIDI output in GUS mode. Usually showed up as an "Exc. Checksum Error" on the MT-32 screen. 

### General

* Fixes issue with setting port numbers less than 0x100 or ending in 00. This fixes common port settings like 0c0 for Tandy or 0x300 for NE2000
* Refactors timers to be less jittery; shouldn't be noticeable in practice but may fix some GUS emulation edge cases.

# v2.1.0

## New features/changes

### MPU-401 simultaneous with all modes

MPU-401 emulation is now available in all modes. This can enable simultaneous digital sound effects in SB or GUS modes with MIDI output. If you have another MPU-401 card in the system, to prevent conflicts this can be disabled or moved to a different port with the `/mpuport` option to pgusinit.

The original MPU mode is still available for titles that require MPU interrupts (titles on [this list](https://github.com/bjt42/softmpu/wiki/Compatible-Intelligent-Mode-Games) marked with a 1 require MPU interrupts).

# v2.0.0

## New features/changes

### Serial mouse emulation

Now you can use a USB mouse as a serial mouse on your PC. Features a configurable report rate defaulting to 60Hz so the emulated serial mouse is much smoother and more responsive than a real serial mouse. Also supports configurable sensitivity and protocol support, including Microsoft, Logitech, Mouse Systems, and Intellimouse with wheel support. Note that being a serial port, this does use an IRQ so the IRQ jumper on the PicoGUS must be set to IRQ 4 or 3 depending on which serial port is configured, or use a mouse driver like ctmouse that can use a custom IRQ. Serial mouse can be emulated simultaneously with sound card modes that do not require IRQ such as AdLib, CMS, and Tandy (MPU coming in future firmware for games that don't need MPU IRQ).

Thanks to [Artem Vasilev (wbcbz7)](https://github.com/wbcbz7) for implementing mouse and 8250 UART emulation.

### "Multifw" - all modes in one firmware

All emulation modes (GUS, SB, MPU, etc.) are now contained within the same firmware. This means switching between modes is much faster than before, taking 1-2 seconds on average. Switching also no longer involves writing new firmware to the card's flash, alleviating flash wear concerns (each sector on the flash is rated for at least 100,000 cycles, so there wasn't not much to worry about, but it's still nice for peace of mind).

Many thanks to [Jeroen Taverne](https://github.com/jeroentaverne) for developing [the original proof of concept](https://github.com/jeroentaverne/pico_multi_firmware) and [smymm](https://github.com/smymm) for implementing it within the PicoGUS codebase.

### Card settings can now be saved in flash

Once you're satisfied with your PicoGUS's settings, they can now be saved in the card's flash. Saved settings persist across reboots or power cycle without needing to run pgusinit each boot.

For example, when using serial mouse emulation, some BIOSes like MRBIOS need to see the emulated serial port right at boot. Also as a bonus if you want to use emulation modes outside of DOS, settings will apply in those other operating systems. Want to use GUS in OS/2 or Linux, or serial mouse when setting up NeXTStep? This will help!

### Overhaul of pgusinit

To support the above new features, adding more options to pgusinit meant I ran out of single letters for its various switches that make mnemonic sense. I've moved to longer yet hopefully still fast to type names for each of the switches.

Also, each pgusinit option now persists between invocations of pgusinit. Previously, most but not all options had to be given in the same invocation of pgusinit. Each option that would enable a feature (e.g. joystick support) has been turned into an on/off option so it can be turned off as well as on.

Running pgusinit by itself will now show all the currently applied settings for the current firmware mode.

See the [pgusinit README](https://github.com/polpo/picogus/blob/v2.0.0/pgusinit/README.md) for more details on running pgusinit.

## Fixes

### Sound Blaster 2.0:

* Added speaker on/off commands
* Greatly increased quality of output in "Direct DAC" mode

### OPL2 emulation

* Fixed "missing notes" issue, most commonly heard in Prince of Persia. Thank you to [TerryFi](https://github.com/TerryFi) for discovering the issue and coming up with a preliminary fix, then incorporating the final fix from the upstream emu8950 repository.

# v1.2.0

## New features/fixes

### Sound Blaster 2.0 emulation:

The AdLib mode (`pg-adlib.uf2`) has been replaced with a _new_ Sound Blaster 2.0 mode (`pg-sb.uf2`)! Code to emulate the Sound Blaster DSP was contributed by [Kevin Moonlight](https://github.com/yyzkevin) - huge thanks to him.

* Sound Blaster 2.0 DSP support is pretty well tested but you may run into issues. Please consult the [Compatibility List](https://github.com/polpo/picogus/wiki/Compatibility-list) for titles with known issues, and feel free to [file an issue on GitHub](https://github.com/polpo/picogus/issues/new) to report any problems.
* AdLib/OPL2 emulation has been improved, fixing issues with missing/wrong notes.
* The SB base port can be set with pgusinit with the `/p` option, and the OPL/AdLib base port with the new `/o` option.
* Some older titles supporting AdLib are "speed sensitive" and have weird playback on fast systems (even with a genuine OPL2/OPL3). A new `/w` option in pgusinit can work around these issues in most circumstances.

### MPU-401 emulation:

* Fixes an issue reported by zuldan on Vogons where running pgusinit in MPU-401 mode wouldn't work on certain systems. Fixed by initing the MPU-401 and sending the reset MIDI data asynchronously, preventing IOCHRDY from being held low for too long.
* Sysex delay handled without busy wait. Shouldn't have much effect presently, but may allow MPU-401 to be emulated simultaneously with other modes in the future.

### General:

* Allows the volume of the wavetable header to be set with the `/v` option in pgusinit in all modes. This is useful if you want to use the wavetable header to mix in other external audio sources like a CD-ROM drive (connection guide coming to the Wiki).

# v1.1.0

## New features/fixes

### GUS emulation:
* Works around a hardware bug in the PCM510xA DAC that results in ~10% of chips to be silent at 22.05kHz sampling rate. This is the rate produced by the GUS at 28 channels, and is used by Doom and the demo "Dope". The workaround is to run the DAC at 44.1kHz, linearly interpolating the 22.05kHz output.
* Increased fractional precision of wave addresses to 10 bits from 9.
* New EXPERIMENTAL fixed 44.1kHz output. Normally the GF1 varies its output sample rate from 44.1kHz at 14 voices to 19.2kHz at 32 voices. Using this option enables 44.1kHz output for all numbers of voices, similar to the Interwave. This gives much higher quality output when playing lots of channels.  This will result in stuttering in most games that use streaming DMA for sound effects like Doom, hence it is EXPERIMENTAL. It can be enabled with the `/4` switch in pgusinit. Thanks to [wbcbz7](https://github.com/wbcbz7) for contributing this support along with the increased wave address precision.
* Known issue: Impulse Tracker constantly re-inits the GUS to get the best sampling rate and if it passes through 28 channels rapidly, audio artifacts can be heard. To work around, run PicoGUS in fixed 44.1kHz output mode.

### pgusinit
* New `/4` switch when in GUS mode to enable fixed 44.1kHz output.

# v1.0.2

## New features/fixes

### General:
* New bus timing, fixes compatibility with IBM PC/AT 5170.
* Faster IOCHRDY timing to improve compatibility and spend less time on ISA bus.
* Less aggressive overclock and different startup timing to improve stability on reset.
* Added support for Xbox 360 wireless adapter dongle.

# v1.0.1

As always immediately after I do a big release, a significant bugfix comes soon after! Don't forget to look at the notes for firmware v1.0.0.

### General:
* Increase stability upon startup on PicoGUS 2.0 boards.

# v1.0.0

The PicoGUS 2.0 hardware brings v1.0.0 of the PicoGUS firmware! This firmware runs on _all_ released revisions of the PicoGUS hardware: 1.1, 1.1.1, 1.2, and 2.0.

## New features/fixes

### General:
* Support for PicoGUS 2.0 hardware and its software-controlled wavetable header volume (`/v xxx` pgusinit option).
* A preview of game port joystick emulation using USB joysticks is included in all sound card emulation modes, enabled with the `/j` pgusinit option. There is also a "joystick exclusive" firmware (`pg-joyex.uf2`) for when you only want to use a USB joystick and not emluate any sound cards. This is considered a preview because only a few USB joystick types are supported: wired Xbox 360 (and third party clone) controllers and the Sony DualShock 4. More joysticks will be supported in the future! See the [Compatibility List](https://github.com/polpo/picogus/wiki/Compatibility-list) wiki page for more information about this feature.
* Much more reliable firmware flashing from DOS. The previous method abused IOCHRDY to hold the ISA bus far longer than usual, and some chipsets would release the bus before certain flash operations were complete.
* A more robust startup sequence to improve firmware boot stability. All firmwares have the same LED sequence when starting so you will know when the firmware is ready.
* Compatibility with slower PSRAM chips that are rated for only 104MHz, such as the Vilsion Tech VTI7064MSME and ISSI IS66WVS1M8BLL-104NLI. This widens available options for those DIYing their own PicoGUS boards.

### pgusinit

pgusinit has been updated to version v2.0.0, featuring:

* Updates to pgusinit to support the new firmware flashing protocol, as well as support upgrading from v0.x.x firmware to v1.x.x firmware. If you have a v0.x.x version of firmware running on your PicoGUS, you can upgrade to v1.0.0 with the latest version of pgusinit included with the firmware release package.
* Detects the current card mode and only shows options applicable to that mode when using `/?` to ask for help.

### Adlib emulation:
* Fixes an issue where some software would incorrectly detect PicoGUS as an OPL3 instead of an OPL2.

### MPU-401 emulation:
* Sysex delay can be enabled with the `/s` pgusinit option. This will prevent buffer overflows on older MPU-401 revisions.
* Fake all-notes-off for the Roland RA-50 can be enabled with the `/n` pgusinit option.
* Fixes song change issue in Frederik Pohl's Gateway. PicoGUS will detect when Gateway is running and enable a hack in how the version and ack are returned. Run pgusinit to restore default operation after you're done playing Gateway.
* Running pgusinit will silence any stuck notes if a program exits unceremoniously.

# v0.7.0

## _Note:_ Please use the version of pgusinit.exe that comes with this firmware!

Version v0.7.0 of the firmware has a much smaller default GUS audio buffer size of 4 samples, thanks to the higher RP2040 clock speed. If you run an older version of pgusinit.exe, it will set the buffer size to 16 samples, negating many of the improvements that this version brings for GUS emulation.

## Release notes:

### General:
* Runs the RP2040 at 400MHz. This allows for faster reaction to ISA events, holding IOCHRDY low for shorter time periods. This allows better performance for other ISA cards and may help run on faster ISA bus speeds.
* Fixes from @SuperIlu for pgusinit to fix usage message and improve command line parsing.

### GUS emulation:
* Higher clock speed enables much shorter interval before checking for IRQs. This should improve compatibility in titles that use IRQs and DMA.
* Fixes for Hand386 and other M6117D-based systems.
* Changes to pgusinit to default to the new GUS buffer size of 4 samples, and support setting the buffer size below 8 samples. Please use the new version of pgusinit that ships with this firmware!

### Tandy emulation:
* New emulation core contributed by [Aaron Giles](https://aarongiles.com/). This is the same core used in [DREAMM](https://aarongiles.com/dreamm/) and should result in better accuracy across all titles. or example, sound effects such as crickets chirping and meteor crash in Maniac Mansion and snoring in Zak McKracken sound much better.

### CMS emulation:
* New emulation core contributed by [Aaron Giles](https://aarongiles.com/). This is the same core used in [DREAMM](https://aarongiles.com/dreamm/) and should result in better accuracy across all titles.
* Fixes issue with pitch of CMS sound being too high.

### MPU-401 emulation:
* Misc optimizations might improve compatibility in some titles.

For known issues, please see the [Compatibility List](https://github.com/polpo/picogus/wiki/Compatibility-list) wiki page.

# v0.6.1

Another bugfix release! This release fixes a bug introduced in firmware [v0.5.0](https://github.com/polpo/picogus/releases/tag/v0.5.0) that caused Descent to freeze on the `Loading...` indicator when running setup and starting the game. 

### GUS emulation:
* Fixes freeze when starting Descent. This patch release uses a smaller/simpler 4-byte DMA buffer that solves the freeze with Descent while also hopefully still preventing stuttering in Doom introduced by level changes (the reason for the DMA buffer in the first place).

For known issues, please see the [Compatibility List](https://github.com/polpo/picogus/wiki/Compatibility-list) wiki page.

# v0.6.0

### CMS emulation:
* New emulation mode: **CMS/Game Blaster**.

For known issues, please see the [Compatibility List](https://github.com/polpo/picogus/wiki/Compatibility-list) wiki page.

# v0.5.1

Bugfix release! All of the new features of [v0.5.0](https://github.com/polpo/picogus/releases/tag/v0.5.0) plus the following fixes:

### Tandy emulation:

* Fixed reporting of base port when running pgusinit when on Tandy firmware
* Fixed firmware flashing from DOS when on Tandy firmware

# v0.5.0

### General:
* More reliable firmware flashing from pgusinit by clocking down the Pico and disabling interrupts. Many thanks to JazeFox at Vogons for debugging this issue and suggesting a fix.

### Tandy emulation:
* New emulation mode: **Tandy 3-Voice**. This emulation is on port 2C0h by default, to avoid conflicts or masked IO on the default Tandy port of 0C0h in non-Tandy systems. This is the same alternate port that [Matze79's "TNDY" card](https://www.vogons.org/viewtopic.php?f=62&t=54249) can use. Use the [TNDY driver program](https://github.com/JKnipperts/TNDY) to redirect port 0C0h to 2C0h. Also [many games need to be patched](https://www.vogons.org/viewtopic.php?t=77679) to allow for Tandy sound on non-Tandy systems with CGA, EGA, or VGA graphics. Note that this mode has not received much optimization, so accuracy and compatibility can be improved.

### GUS emulation:
* Resets DMA status bit to 0 on completion of DMA handler. Fixes some Demoscene titles.
* Buffers uploaded DMA samples instead of writing 1 byte at a time. Currently this buffer is 8 bytes, and may be configurable in future releases. Should help stuttering/slowdown issues in games that use streaming DMA audio like Doom.
* Bails out on sound rendering when sample rate changes. This should eliminate any "warbling" sounds when Impulse Tracker resets the channel count on the fly.
* Uses the [RP2040 hardware interpolation](https://people.ece.cornell.edu/land/courses/ece4760/RP2040/C_SDK_interpolator/index_interpolator.html) unit to interpolate samples and clamp output to 16 bits.

For known issues, please see the [Compatibility List](https://github.com/polpo/picogus/wiki/Compatibility-list) wiki page.

# v0.4.0

### General:
* New version (v1.0.1) of pgusinit.exe - DMA interval is in µs, not ms

### GUS emulation:
* Refactored DMA transfer completion handler: this results in much higher compatibility with titles that use streaming DMA. Overriding the DMA transfer interval is not necessary in most circumstances now.
  * Fixes games: Quake, Doom (and Doom engine games), Duke3D, Descent, Hocus Pocus (partially); Demo: Inside
* Fixed bug where DMA control register was not properly reset between transfers. Fixes garbage samples when uploading mixed 16 & 8 bit samples.
  * Fixes music players/trackers: Open Cubic Player (with `gusFastUpload=on`), Fast Tracker 2

# v0.3.0

### General:
* Firmware can now be programmed from DOS (requires FW v0.3.0 or above - upgrading from previous versions must be done by USB)
   * Emulation mode can be changed "on the fly" by uploading different firmwares
* New version (v1.0.0) of pgusinit.exe - Firmware versions v0.3.0+ require this new version of pgusinit.exe!

### GUS emulation:
* Major DMA improvements!
  * DMA PIO state machine rewrite to solve sample glitches (fixes Star Control II)
  * Asynchronous writing to PSRAM of DMAed samples (fixes Doom)
  * Smarter sample cache (fixes Doom)
  * Adjustable DMA interval (fixes Doom)
* One firmware for all ports - base port is now configured with `ULTRASND` environment variable and pgusinit.exe

### MPU-401 emulation:
* Intelligent mode emulation is now working in all but a few titles
* Base port now configured with pgusinit.exe (defaults to 330)

### AdLib emulation:
* Base port now configured with pgusinit.exe (defaults to 388) 

# v0.2.0

* Solved a regression where lots of channels playing 16-bit samples would cause audio stuttering (example: the demo Aeon Drift by Disaster Area). Added a super simple sample pair buffer per channel to solve this.
* Super-unstable DMA support preview. Count on it to fail, but feel free to celebrate when it works! 😅
* Fixed a small bug in pgusinit.exe that didn't set the audio buffer size to 16 if the `/a` option was not given on the command line.
* Includes firmwares for GUS port 220, 240, and 260.
* Built with a new automatic release script.

For firmware programming instructions, see the ["Programming the Pico" part of the build guide](https://github.com/polpo/picogus/wiki/Building-your-PicoGUS#programming-the-pico).

# v0.1.0

* New release format: a ZIP file containing firmware UF2 files and PGUSINIT.EXE.
* Features all IRQ fixes shown in the [November 2022 update video](https://youtu.be/CkJvkJVRscQ) and then some – regressions introduced by those fixes have now been fixed. 😅
* New version of PicoGUSinit (PGUSINIT.EXE) to allow the audio buffer size on the PicoGUS to be configured via the `/a n` option, where `n` is the size of the buffer in samples. Some productions may still freeze, or have audio glitches, and configuring the buffer size can help. Please see the [Compatibility List](https://github.com/polpo/picogus/wiki/Compatibility-list) for the flag to use for any problematic programs.
* Preview firmware for Adlib and MPU-401 emulation.

For firmware programming instructions, see the ["Programming the Pico" part of the build guide](https://github.com/polpo/picogus/wiki/Building-your-PicoGUS#programming-the-pico).

# v0.0.1

Contents:
`picogus.uf2` - Firmware with Gravis Ultrasound emulation core, port 240
`PGUSINIT.EXE` - DOS executable to detect and initialize the PicoGUS

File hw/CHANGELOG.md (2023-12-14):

# v1.2

A new release of the more DIY friendly version of PicoGUS "backporting" improvements from the v2.0 board.

* Adds option for integrated DAC section. The purple "GY PCM5102" DAC modules have spotty QA, so integrating the DAC is both potentially lower cost and more reliable. Footprints remain to still allow use of the DAC module.
* Reset stability improvements: RC circuit on Pico RUN pin to delay start on power up and filter out glitches on ISA reset, and U5 is now 74AHC logic family for higher positive-going threshold
* ISA RESET has weak pulldown to allow reliable programming the Pico outside of powered PC
* DACK has weak pullup to allow PicoGUS to be used without DMA channel set
* 5V MIDI circuit: uses open drain inverter for better drive and uses more commonly available resistors
* U2 is now specified as an 74LVC244 in the BOM: it's cheaper and more available and in my testing performs just as well as the 74CB3T3245
* Jumper to apply power to micro USB-B connector on Pico to allow USB HID devices to be used
* Fixes to card dimensions to better follow ISA card specs: narrower card edge and better fit for card bracket in PC cases
* Production files for JLCPCB full PCB assembly
* Updates to thank you section on back

# v1.1.1

Functionally identical to v1.1. Brings released BOM, gerbers, and KiCad design into sync.

* C10 is a 1uF capacitor

# v1.1

First "final" released hardware version of PicoGUS.

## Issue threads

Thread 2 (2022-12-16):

Psuedocode for doing fast cubic spline interpolation (for better resampling quality)

8bitbubsy, 2022-12-16:
So I saw the talk about a possible cubic spline interpolator mode for PicoGUS, which would result in crisper audio with less treble being cut off from linear interpolation.

Here's some code I wrote that _should_ work: https://pastebin.com/raw/Yvyh63VP

The only problem is that you need to input the correct sample points for the s0..s3 function parameters. This is slightly tricker than having to deal with just one extra sample (like with linear interpolation).

Here's what s0..s3 should be based on a few conditions (could be off, but something like this anyway).

Some notes first:
- `Pos` is the current integer sampling position
- `End` is the end point for a non-looping sample
- `s` is a pointer to the sample data (either 8-bit or 16-bit samples)
- `HasLooped` is a flag for having reached the end of a loop on a looping sample. Set it to `false` when a voice is starting to play a sample (sample trigger), and set it to `true` when you have looped at least once (sample is looping its loop now). I'm sure it has to be set to `false` in other situations as well.

### Non-looping sample:
- **s0** = `if (Pos == 0) 0 else s[Pos-1];`
- **s1** = `s[Pos]`
- **s2** = `if (Pos+1 >= End) s[End-1] else s[Pos+1];` (yes, End-1. As in the last sample point)
- **s3** = `if (Pos+2 >= End) s[End-1] else s[Pos+2];`

### Forward-looping sample:
- **s0** = `if (HasLooped) { if (Pos == LoopStart) s[LoopEnd-1] else s[Pos-1]; } else if (Pos == 0) 0 else s[Pos-1]; }`
- **s1** = `s[Pos]`
- **s2** = `if (Pos+1 >= LoopEnd) s[LoopStart+((Pos+1)-LoopEnd)] else s[Pos+1];`
- **s3** = `if (Pos+2 >= LoopEnd) s[LoopStart+((Pos+2)-LoopEnd)] else s[Pos+2];`

### Bidirectional-looping sample:
- **s0** = `if (HasLooped) { if (Pos == LoopStart) s[LoopStart+1] else s[Pos-1]; } else if (Pos == 0) 0 else s[Pos-1]; }`
- **s1** = `s[Pos]`
- **s2** = `if (Pos+1 >= LoopEnd) s[LoopEnd-((Pos+2)-LoopEnd)] else s[Pos+1];` (do Pos+2/Pos+3 for an extra -1)
- **s3** = `if (Pos+2 >= LoopEnd) s[LoopEnd-((Pos+3)-LoopEnd)] else s[Pos+2];`

There could be some off-by-one (or bigger) errors here, so do experiment with it. If it's possible to sample backwards in "forward loop" mode, then it would also need more logic.

PS: I totally understand if this is too bothersome to implement, and that's fine. :-)

ramapcsx2, 2022-12-17:
Hey, I'm not part of this project, but I wonder what you think the performance / RAM impact of this will be :)

8bitbubsy, 2022-12-17:
It ought to be quite faster than doing cubic spline without a table. RAM usage for the table is 4*512*2 (4096) bytes.

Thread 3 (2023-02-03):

Potential bracket options

tyrells, 2023-02-03:
I was just doing some searching for other potential back bracket options:

- https://www.mouser.com/ProductDetail/Keystone-Electronics/9203-1?qs=%252BU2dxLPlMC27%252BsH2ZGD%252BtA%3D%3D
- https://www.aliexpress.com/item/1005001466248688.html

The screw holes are in different places, so this would need a PCB change, but that may be a good option assuming the Keystone Electronics 9202-1 bracket isn't coming back in stock.

polpo, 2023-02-05:
Unfortunately those brackets are made for PCI cards so the mounting holes are on the other side of the bracket. Standoffs might solve that problem, though...

tyrells, 2023-02-06:
I didn't realize that. Thank you. I will keep looking.

arkayii, 2023-02-07:
If there are people who have zero other viable bracket options, I would be happy to accurately drill out a 9202 bracket and send it out, but the necessary cost of international shipping means it would only be a viable option for those who are particularly keen - I'm guessing the total cost would be at least $10, if I did it free, which I would. Nonetheless feel free to contact me here, or on Vogons as Shreddoc.

Closed 2023-02-06.

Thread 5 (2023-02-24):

PGUSINIT Usage is wrong

SuperIlu, 2023-02-24:
The usage specifies "/b" as option to set the base address, the option parsing uses "/p" to scanf() `port_override`

SuperIlu, 2023-02-24:
Also, I just noticed:
`/d n - force DMA interval to n æs. Default: 0, Min: 1, Max: 256`

default is 0, but minimum value is 1?

and isn't the value an uint8_t? Wouldn't that make the max:=255 (same for sample buffer size)?

arkayii, 2023-02-24:
Since we're talking about this area, I'll mention this very minor, errr, quibble. As the MS-DOS environment is typically non case-sensitive, it might be appropriate to allow/parse switch parameters in both upper and lower case.

SuperIlu, 2023-02-25:
submitted a PR for this #6

Closed 2023-07-02.

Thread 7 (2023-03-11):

I have no knowledge of electronic circuits, but I would like to make your project.

drawingangnam, 2023-03-11:
Firstly, thanks for sharing your awesome project.

I have no knowledge of electronic circuits, but I enjoy soldering.

I would like to give your project as a gift for my homemade retro PC, but some IC chips are hard to find in my country.

74CB3T3257PWR
74CB3T3245PWR

Is there a replacement for the above two chips?

If there are compatible chips, please advise.

Thank you.

drawingangnam, 2023-03-12:
I will find oversea marcket.

ramapcsx2, 2023-03-12:
These seem a bit special (I haven't heard of them before), though they carry the '74' identifier. '74' chips are supposed to be widely available off the shelves chips.
Best of luck!

polpo, 2023-03-13:
The 74CB3T3245PWR can be replaced with a TSSOP-14 74LVC244. I have tested the Nexperia 74LVC244APW,118 and it works fine.

The 74CB3T3257PWR is harder to find a replacement for. I have not found another 2:1 mux/demux chip that also does level shifting. The Pico unofficially can tolerate 5V signals, so another 3257-type mux could work, but I have not tested any alternatives. Options could include the Nexperia 74CB3Q3257PWJ but that would pass 5V through to the Pico. The Analog Devices ADG3257 is also interesting, but without bodges on the board it would pass 2.6V in both directions which is kind of borderline for TTL logic levels.

ramapcsx2, 2023-03-13:
(Any kind of sources for that 5V tolerance? I realize they wouldn't print it in the spec sheets, but maybe a hint on a forum post or so :p)

polpo, 2023-03-13:
@ramapcsx2 sorry, I forgot to link it. Eben Upton himself mentions it [in this Hackaday comment](https://hackaday.com/2022/09/25/pi-pico-w-does-pcmcia-gets-this-ibm-pc110-online/#comment-6516402):

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

ramapcsx2, 2023-03-13:
Epic, thank you! :)

Closed 2023-03-12.

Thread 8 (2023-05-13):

The FX sound is not coming out.

drawingangnam, 2023-05-13:
Hello!
I have finally completed your wonderful project by myself.
Although there was a minor issue during production, I was able to resolve it successfully.
Instead of using the 74CB3T3245PWR, I used the 74LVC244, and the card booted up well.

The card is recognized well in pgusinit and sounds great in adlib mode.
However, when I run Duke Nukem or Doom in GUS mode, the music plays well, but the FX sound doesn't come out.

Do you have any advice?
 I've tried various jumper settings and experimented with different computers, but the symptoms are the same.
 I also tried different settings such as "set ultrast=240,3,3,7" after using "set ultrast=240,1,1,5,5" (and, of course, I set the jumper on the board accordingly)."

drawingangnam, 2023-05-13:
Oh... Finally, the FX sound is working on the third 586 PC.
I don't know why there was no sound in the FX or MIDIDEMO.BAT on the first and second computers.
I'll try to solve the problem slowly.

Also, there is no sound in Sound Blaster emulation mode.
I don't know what I did wrong.
When I run E.BAT and choose "1 = Sound Blaster emulation",
it shows "GF1 SBOS V3.82 The NMI procedure on this P.C. is disabled.

When I run MIDIDEMO.BAT, the MIDI sound works well at first, but then it stops in the middle. This happens with all other songs as well. (It stops when one note is sustained for too long.)

Could you please give me some advice?

polpo, 2023-05-13:
Sound FX are streamed in via DMA into a pair of looping channels, and it requires really tight timing between IRQ and DMA signals to work well. I've tuned the DMA support on motherboards with Intel 430FX and 430VX chipsets, and support for other chipsets is hit-or-miss because I only have a few motherboards to test on. See [the general compatibility notes](https://github.com/polpo/picogus/wiki/Compatibility-list#general-compatibility-notes) in the wiki to see what is reported as working and not working. What chipsets did you not get sound FX on, and what chipset does the third 586 PC have?

Unfortunately, SBOS does not work and will never work on the current hardware revision. The pin that generates an NMI (IOCHCHK) is not wired on the PicoGUS PCB and SBOS requires it to operate. I should add a note to the compatibility list wiki page about that.

Support of Gravis's PlayMIDI (which MIDIDEMO.BAT runs) is not very good, unfortunately. What you report is actually a bit better than what I've seen on my own motherboards, which also include corrupted sounding samples. I haven't been able to make much progress in improving PlayMIDI. If you want to play MIDI, try DOSMID with ULTRAMID.EXE loaded. It should work much better.

drawingangnam, 2023-05-14:
>
Your prompt and informative response is greatly appreciated as well.

As a hobby, I am currently building a retro gaming PC using a 386-586 compatible industrial PC in the PC104 form factor.
Although I do not possess any professional knowledge in electrical engineering, I will do my utmost to share compatibility information between the PC104 computer and PICOGUS.

As you mentioned, I ran Ultramidi and attempted to play Dosmid, but I received an error message indicating that there was no MIDI device detected. I was curious if ULTRAMID or DOSMID requires any specific options or settings?
Could you provide any insight into this issue?

Thank you once again for your remarkable efforts and contributions to the world of retro PCs.

ThatRed, 2023-05-21:
Hi drawingangnam,

I'm currently building a Dolch PAC inspired retro PC, based on a PICMG SBC board. It's a Pentium I 200 MHz with PC104 female headers. If I could just plug the PicoGUS directly into the PC104 headers, I could save an ISA slot...

Did you just solder pin headers so they stick out of the back of the PicoGUS pcb and plugged it into your PC104 board, that the top side with the Pi Pico is visible or did you have to make some adjustments?

Thanks in advance and sorry for hijacking this thread!

Closed 2023-10-05.

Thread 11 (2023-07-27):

New good chipsets tested

zxrepo, 2023-07-27:
Hi, Ian!
Thank you so much for your amazing project! Just assembled and tested PicoGUS. I would like to share my results:

1) KM-S4-1 motherboard (aka U6923, Rectron RT-4s3) SiS 85C496/497 chipset, am486DX4-100
https://www.elhvb.com/webhq/models/486pci/km-s4-1.htm

2) Asus CUV4X motherboard based on VIA Apollo Pro133A chipset, PIII-733
http://hw-museum.cz/mb/46/asus-cuv4x
excellent results but we have to setup a couple of settings in BIOS before:
'Advanced'->'PCI/PNP ISA IRQ Resource Exclusion'->'IRQ 5 Used by ISA' set to 'Yes'
'Advanced'->'PCI/PNP ISA DMA Resource Exclusion'->'DMA 1 Used by ISA' set to 'Yes'

Hope you will find some solution for SBOS and NMI issue someday somehow for all of us! )) Thanks again!!! Cheers!

polpo, 2023-07-31:
@zxrepo thank you very much for these reports! Seeing that the VIA Apollo Pro 133A chipset works is good news, as their MVP3 chipset has issues with DMA and I was worried that it carried onto other, later chipsets. Have you tested if it works in Doom (versions greater than 1.2)? That's an example when the PicoGUS falls over with the VIA MVP3 chipset and the game fails to start.

zxrepo, 2023-08-01:
@polpo  I tested on Ultimate Doom (i.e. version 1.9) - https://youtu.be/VKvyhqkmX5s?t=410
It worked like a charm. By the way, Doom works fine even without proper BIOS PCI/PNP ISA IRQ/DMA settings (unlike other games such as One Must Fall: 2097 e.g.). In other cases it's mandatory to setup IRQ 5 and DMA 1 Used by ISA.

polpo, 2023-08-01:
Wonderful! Thanks for the video, it sounds great! I'll update the compatibility list with these chipsets.

polpo, 2023-09-27:
Compatibility list updated! Thanks again.

polpo, 2023-09-30:
@zxrepo I have a report that updating firmware from DOS with pgusinit on a 486 motherboard with the SiS 85C496/497 chipset fails. Do you know if it works for you?

zxrepo, 2023-09-30:
@polpo just tested this case. And I got exactly the same results for my SiS85C497 motherboard unfortunately.
Firmware update does not occur. The message is 'Card is not if firmware writing mode?'
error message: https://i.imgur.com/AHqqfGf.jpg
installed audio card: https://i.imgur.com/z1I1XKW.jpg

For the same PicoGUS board and my another motherboard asus-cuv4x it's all ok. The firmware update process is successful for VIA694X/694Z AGPset/VT82C686A set.

polpo, 2023-09-30:
Ok, thank you very much for testing this! I've updated the compatibility list with this detail.

Closed 2023-09-30.

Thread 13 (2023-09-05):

Chipset Compatibility

Xenenic, 2023-09-05:
Tested with the same image on each motherboard with the same PicoGUS setting.
[OS]
- DOS 6.22

[PicoGUS]
- FW v0.6.1
- IRQ 5
- DMA 1
- PCB v1.1.1

[Test Games]
DOOM/DUKE3D/DECENT/HERETIC/COMMAND AND CONQUER

[Socket | Chipset | Motherboard | Notes]
[Perfect]
- Socket 3 - UMC UM8498/8496 - PCChips M912 v1.7 - https://theretroweb.com/motherboards/s/pcchips-m912-v1.7-486
- Socket 3 - UMC UM8498/8496 - Biostar MB-14** ??? (UMC498F 2VLB) - https://theretroweb.com/motherboards/s/biostar-mb-14-umc498f-2vlb
- Socket 5 - Intel 430TX (PCIset TX Triton II) - ECS P5TX-Bpro - https://theretroweb.com/motherboards/s/ecs-p5tx-bpro

[Works With Issues]
- Super Socket 7 - SiS 530/5595 (Sinbad) - Soyo SY-5SSM V1.1 - Random hangs/crashes https://theretroweb.com/motherboards/s/soyo-sy-5ssm-v1.1
- Super Socket 7 - VIA VT82C598MVP (Apollo MVP3)- DFI K6BV3+ (REV.A+) - Sounds are randomly 'tincan like' or have static https://theretroweb.com/motherboards/s/dfi-k6bv3-rev.a
- PQFP100 - OPTi 82C295 (SLCWB PC/AT) - Alaris LEOPARD 486SLC2 REV. C - Random hangs/crashes https://theretroweb.com/motherboards/s/alaris-leopard-486slc2-rev.-c

[Does Not Work]
- Socket 5 - PCISet SB82371FB - UNKNOWN - PGUSINIT causes hang

polpo, 2023-09-11:
Thank you so much for these detailed reports! I'll add them to the compatibility list. I now have a few more systems to add to my test bench. I've recently acquired a board with a VIA Apollo MVP3 chipset and also had problems. However this system has the same problems with my real GUS which is interesting.

The system with the PCISet SB82371FB - that's the PIIX south bridge for the 430FX chipset. That's the primary chipset that I develop PicoGUS on so I wonder if something is odd with your motherboard. Is the ISA bus speed configurable in the BIOS for this motherboard? Any other bus timing configuration?

Xenenic, 2023-09-12:
You're welcome! I'll get a scope on the PCISet SB82371FB to verify the ISA bus is at/below 8.33MHz but per the BIOS settings it should have been. I'll also add a step to measure the ISA bus going forward and for the boards I've tested above which had issues or failed.

Xenenic, 2023-09-12:
Following up on the PCISet SB82371FB the issue is related to the board itself, ISA is clocking at 11~MHz regardless of BIOS settings.
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

polpo, 2023-09-15:
Oh yikes! Yeah, the PicoGUS has no chance of keeping up with an 11MHz ISA bus. That's too bad that BIOS settings have no effect on the speed. Fortunately my system with that same southbridge has a fixed 8MHz ISA bus speed. Hopefully you can figure out the make/model of that particular motherboard.

Xenenic, 2023-09-16:
> Oh yikes! Yeah, the PicoGUS has no chance of keeping up with an 11MHz ISA bus. That's too bad that BIOS settings have no effect on the speed. Fortunately my system with that same southbridge has a fixed 8MHz ISA bus speed. Hopefully you can figure out the make/model of that particular motherboard so I can call it out specifically on the compatibility list.

Tracked down the board to the generic "OEM Gateway 2000 P5" series, my guess would be the P5-66/100 with the board supporting up to a Pentium 133MHz via undocumented settings.

polpo, 2023-09-27:
Updated the compatibility list with these reports. Thanks again!

Closed 2023-09-27.

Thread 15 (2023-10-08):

Cannot compile project

maxgerhardt, 2023-10-08:
On Windows ([from installer](https://www.raspberrypi.com/news/raspberry-pi-pico-windows-installer/)) or Linux it's the same thing: When I download
* Pico SDK latest stable 1.5.1
* Pico-Extras matching branch 1.5.1
* Arm-none-eabi-gcc 10.3.1
* CMake  3.25.1
* Ninja 1.11.1

And compile the project, it fails to find a bunch of implementation for linker-wrapped functions at the end, specifically STDIO and Math ones
* `__wrap_puts`
* `__wrap_printf`
* `__wrap_remainder`
* some more..

Full log in https://github.com/maxgerhardt/picogus/actions/runs/6447661204

```
[ 96%] Building ASM object CMakeFiles/picogus.dir/home/runner/work/picogus/picogus/pico/pico-extras/src/common/pico_audio/audio_utils.S.obj
[ 97%] Building C object CMakeFiles/picogus.dir/home/runner/work/picogus/picogus/pico/pico-extras/src/common/pico_util_buffer/buffer.c.obj
[ 98%] Building C object CMakeFiles/picogus.dir/home/runner/work/picogus/picogus/pico/pico-sdk/src/rp2_common/hardware_flash/flash.c.obj
[100%] Linking CXX executable picogus.elf
/home/runner/gcc-arm-none-eabi-10.2020.4-linux/gcc-arm-none-eabi-10-2020-q4-major/bin/../lib/gcc/arm-none-eabi/10.2.1/../../../../arm-none-eabi/bin/ld: /tmp/picogus.elf.RtR3fl.ltrans0.ltrans.o: in function `_out_char':
<artificial>:(.text+0x1f90): undefined reference to `__wrap_putchar'
/home/runner/gcc-arm-none-eabi-10.2020.4-linux/gcc-arm-none-eabi-10-2020-q4-major/bin/../lib/gcc/arm-none-eabi/10.2.1/../../../../arm-none-eabi/bin/ld: /tmp/picogus.elf.RtR3fl.ltrans0.ltrans.o: in function `panic':
<artificial>:(.text+0x2150): undefined reference to `__wrap_puts'
/home/runner/gcc-arm-none-eabi-10.2020.4-linux/gcc-arm-none-eabi-10-2020-q4-major/bin/../lib/gcc/arm-none-eabi/10.2.1/../../../../arm-none-eabi/bin/ld: <artificial>:(.text+0x2158): undefined reference to `__wrap_puts'
/home/runner/gcc-arm-none-eabi-10.2020.4-linux/gcc-arm-none-eabi-10-2020-q4-major/bin/../lib/gcc/arm-none-eabi/10.2.1/../../../../arm-none-eabi/bin/ld: <artificial>:(.text+0x215e): undefined reference to `__wrap_puts'
/home/runner/gcc-arm-none-eabi-10.2020.4-linux/gcc-arm-none-eabi-10-2020-q4-major/bin/../lib/gcc/arm-none-eabi/10.2.1/../../../../arm-none-eabi/bin/ld: /tmp/picogus.elf.RtR3fl.ltrans0.ltrans.o: in function `play_gus()':
<artificial>:(.text+0x2b40): undefined reference to `__wrap_puts'
/home/runner/gcc-arm-none-eabi-10.2020.4-linux/gcc-arm-none-eabi-10-2020-q4-major/bin/../lib/gcc/arm-none-eabi/10.2.1/../../../../arm-none-eabi/bin/ld: <artificial>:(.text+0x2bfc): undefined reference to `__wrap_puts'
/home/runner/gcc-arm-none-eabi-10.2020.4-linux/gcc-arm-none-eabi-10-2020-q4-major/bin/../lib/gcc/arm-none-eabi/10.2.1/../../../../arm-none-eabi/bin/ld: /tmp/picogus.elf.RtR3fl.ltrans0.ltrans.o:<artificial>:(.text+0x2f84): more undefined references to `__wrap_puts' follow
/home/runner/gcc-arm-none-eabi-10.2020.4-linux/gcc-arm-none-eabi-10-2020-q4-major/bin/../lib/gcc/arm-none-eabi/10.2.1/../../../../arm-none-eabi/bin/ld: /tmp/picogus.elf.RtR3fl.ltrans0.ltrans.o: in function `play_gus()':
<artificial>:(.text+0x2ff8): undefined reference to `__wrap_printf'
/home/runner/gcc-arm-none-eabi-10.2020.4-linux/gcc-arm-none-eabi-10-2020-q4-major/bin/../lib/gcc/arm-none-eabi/10.2.1/../../../../arm-none-eabi/bin/ld: <artificial>:(.text+0x39aa): undefined reference to `__wrap_printf'
/home/runner/gcc-arm-none-eabi-10.2020.4-linux/gcc-arm-none-eabi-10-2020-q4-major/bin/../lib/gcc/arm-none-eabi/10.2.1/../../../../arm-none-eabi/bin/ld: /tmp/picogus.elf.RtR3fl.ltrans0.ltrans.o: in function `__wrap_remainder':
<artificial>:(.text+0x3bb8): undefined reference to `__wrap_remquo'
/home/runner/gcc-arm-none-eabi-10.2020.4-linux/gcc-arm-none-eabi-10-2020-q4-major/bin/../lib/gcc/arm-none-eabi/10.2.1/../../../../arm-none-eabi/bin/ld: /tmp/picogus.elf.RtR3fl.ltrans0.ltrans.o: in function `__wrap_remainderf':
<artificial>:(.text+0x3c34): undefined reference to `__wrap_remquof'
/home/runner/gcc-arm-none-eabi-10.2020.4-linux/gcc-arm-none-eabi-10-2020-q4-major/bin/../lib/gcc/arm-none-eabi/10.2.1/../../../../arm-none-eabi/bin/ld: /tmp/picogus.elf.RtR3fl.ltrans0.ltrans.o: in function `main':
<artificial>:(.text.startup+0x19a): undefined reference to `__wrap_puts'
/home/runner/gcc-arm-none-eabi-10.2020.4-linux/gcc-arm-none-eabi-10-2020-q4-major/bin/../lib/gcc/arm-none-eabi/10.2.1/../../../../arm-none-eabi/bin/ld: <artificial>:(.text.startup+0x200): undefined reference to `__wrap_puts'
```

Which version of the SDK and compiler etc. are you using to build this project? The Wiki and README does not mention it.

maxgerhardt, 2023-10-08:
I'm also quite a bit confused on how files like `pico_reflash.c` (which is compiled in every case) can do `printf()` when e.g. in the OPL project enviornment, all STDIO functions are turned off.
```cmake
    pico_enable_stdio_uart(picogus 0)
    pico_enable_stdio_usb(picogus 0)
    pico_enable_stdio_semihosting(picogus 0)
```

polpo, 2023-10-08:
Sorry, better documenting building is something I need to do. I use LTO which does not work out of the box with the Pico SDK, so I've patched the SDK to allow for it. If you want to compile without needing to patch the SDK, disable LTO by removing [this line from CMakeLists.txt](https://github.com/polpo/picogus/blob/56ad321f988d3ec19579297da167bd6c8202a079/sw/CMakeLists.txt#L34C1-L34C37):

```
add_compile_options(-flto=jobserver)
```

I use the latest versions of the ARM GNU toolchain and Pico SDK.

Disabling stdio in that way doesn't remove stdio completely, it just makes stdout/err/in go nowhere.

I forgot that I turned all stdio off in OPL... it's been a while since I touched that part of the project. I don't remember why I did that! I do purposefully turn it off for MPU, so maybe it's just a copy-and-paste from there.

maxgerhardt, 2023-10-08:
I've just confirmed that this works indeed and the .uf2 file is now built.

If LTO is necessary for the project (size or performance wise), can you push your modified Pico-SDK? It does not seem to be in https://github.com/polpo?tab=repositories&q=sdk&type=&language=&sort=.

>I use the latest versions of the ARM GNU toolchain

Just to confirm, that is arm-none-eabi-gcc version 12?

polpo, 2023-10-08:
I don't consider LTO really necessary. I need to do some real comparisons to see if it's of measurable benefit. I manually set most functions as inline almost everything anyway for performance reasons.

If you want to see what LTO does, change [this line in platform.h in the Pico SDK](https://github.com/raspberrypi/pico-sdk/blob/6a7db34ff63345a7badec79ebea3aaef1712f374/src/rp2_common/pico_platform/include/pico/platform.h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) from:

```
#define WRAPPER_FUNC(x) __wrap_ ## x
```

to

```
#define WRAPPER_FUNC(x) __attribute__((used)) __wrap_ ## x
```

> Just to confirm, that is arm-none-eabi-gcc version 12?

Correct. I am using arm-none-eabi-gcc-12.3.1 currently but any version 12 will work fine.

polpo, 2023-11-07:
Fixed in your GitHub action MR and improved in c475db6 - LTO is no longer enabled by default and can be enabled by adding a `-DUSE_LTO` on the CMake command line.

Closed 2023-11-07.

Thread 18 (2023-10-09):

Digital s/pdif out options

skadarnold, 2023-10-09:
I am loving this project at the moment, and plan to build a board and do some of my own testing. Awesome work! I am wondering if there were any thoughts or plans to implement a digital output option? It seems it would be pretty easy to replace the PCM5102 with an I2C to spdif converter. But I am wondering if there were any thoughts for either building a dedicated option for spdif coax, or at least a pinout to allow connection to a PCI breakout board. The PCM5102 does a great job in my experience, but I try to use spdif out as much as possible to help reduce ground noise generated from the computer internally.

polpo, 2023-10-09:
The pico-extras library I use for I2S audio out also has a SPDIF audio out module, so integrating that would actually be pretty simple! And the UART TX header on the PicoGUS board could be used for TTL SPDIF instead, and converting that to TOSLINK or coax on a breakout board like you suggest would be pretty simple. The hangup would be around non-standard sampling rates which I'm assuming SPDIF gear would not be happy with. The GUS can change sampling rate among 18 different values between 44100Hz and 19293Hz almost constantly, and the OPL2 emulation also uses a strange sampling rate of 49716Hz. There might be a way to force to 44100Hz for GUS, but I haven't looked too much into it as it may be too much for the Pico or PSRAM to handle.

Anyway I'll keep this issue open if I get fixed 44.1kHz sampling rate to work.

skadarnold, 2023-10-09:
This is great news, especially considering the current UART TX on the board could already allow for this expansion. Having a dedicated hardware module for this would be a nice option as well for the future, but using the UART we would have the option to do some testing on this current hardware revision.

That is very interesting about the non standard sample rates as well. I would be curious to see how external DAC's would handle  the changes.  Does the PCM5102 over I2S behave different than TTL over SPDIF in reference to these odd sample rates?

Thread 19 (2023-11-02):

Compatibility Report: PicoPower Redwood2 (PT86C718A2-B) Chipset

WookieEngineering, 2023-11-02:
This chipset is used on some 486 SBCs. Not sure if anyone is working on or has considered working on a PC/104 version of the PicoGUS, but this info could be useful if so.

Fully compatible with everything i tried from the compatible software list (1 demo in GUS mode, 2 games in GUS mode, 1 game in adlib mode, 2 games in CMS mode). Don't have any MIDI devices to test. Only issue to report is notes will hang upon reboot (GUS, adlib, and CMS mode). Did not have this issue on 430VX chipset MB.

Let me know if you want me to test anything specific on this chipset.

-Chris

SudosFTW, 2024-01-10:
> This chipset is used on some 486 SBCs.
Is the SBC in question a Teknor? if so, which model?
I have a VIPer809 and this interests me to know that this works. Would definitely save up a slot, especially considering I could get a bracket printed to extend the outputs to where an empty parallel header lies in my PS/2 mouse bracket... as the 809 already has one onboard.

I'm also interested to know what the PicoGUS does at various FSB speeds. on the Teknor boards with such, the headers are different W# designations yet the pinouts are all the same according to TRW. undocumented header configs are 1-2&3-4 populated for a 20MHz bus, and no jumpers on any of the pins for 40MHz. 1-2 is 33MHz and 3-4 is 25MHz.

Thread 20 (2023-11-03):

SCK Short to Ground - I2S DAC Questions

skadarnold, 2023-11-03:
I am having issues with my PicoGUS detection whenever I insert the 3.5mm line into the I2S DAC module. This is consistent so I have been looking for problems in that area. The SCK line seems to be shorting to ground. All of the joints look clean, but it makes me wonder if I should have left out soldering certain pins that were undefined in the build guide. I will continue to troubleshoot and will probably pull the I2S DAC out to get a better look at things.

I question whether it was incorrect of me to solder in these extra pads along the length of the module? I had an extra pin header to that length and thought it wouldn't hurt to solder them down for extra support, but maybe I should have only soldered LGRG or finished soldering the whole row down?

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

polpo, 2023-11-03:
Hi, all of those extra pins are not connected anywhere on the PicoGUS board so soldering them should not cause any issue, unless you've somehow caused a short with a solder bridge or something... And SCK is intentionally grounded because the PicoGUS uses the PCM510xA chip in system clock PLL mode, so that's expected.

After hearing from people's experiences with the purple DAC modules on the PicoGUS boards they've built, I've learned that they have pretty spotty QA. There's a chance that your module is bad.

skadarnold, 2023-11-03:
Thanks for the fast reply. This is all good information to know. I was able to remove the DAC module so I will continue to test. I might even socket the DAC module this time so I can test modules easier. I will keep in touch to what I discover.

polpo, 2023-11-03:
No, LGRG are not required. They're only there for physical support.

skadarnold, 2023-11-03:
I had a moment to strap a new module on it. At first it seemed to have fixed it, but then further testing shows that it is functioning about the same. The first time I tried it with 3.55mm audio inserted it worked just fine, but was inconsistent afterwards. With that line inserted there is about 1/6 or less chance of the PicoGus initializing. I also noticed that with the line out, the light on the pi pico stays on and steady when booting the system. As soon as the 3.55mm is inserted the light will only stay on for a few moments at boot. This might be a general compatibility thing with this motherboard and PSU combo, I will have to do some further testing to know for certain. I will also try different 3.55mm cables to see if there is something specific.

skadarnold, 2023-11-03:
So I am finding that the DAC module and inserting the audio cable is not as relevant as I first thought. It maybe has a slight affect, but even without it the pi pico will only light up about half of the time when I start the computer. I have tested this on two different machines which seems to have identical behavior on both of them.  Both motherboards tested are different variations of AG430HX but I will try and confirm whether or not it is a motherboard compatibility and issue with my PicoGus

arkayii, 2023-11-03:
Any chance it's related to the reset line instability/sensitivity that has been seen in other Picogus contexts recently? - probably not, but didn't want it to go unmentioned.

Also, when doing my own Picogus builds, I too was uncertain at times, about the expected status of the LED light on the Pico. All I knew was that an unstable build was often accompanied by inconsistent Pico LED lighting, and that thorough (solder) checks and reflows fixed almost all of the issues of this nature that I encountered. That said I certainly wouldn't discount other possible causes, such as that I initially mentioned.

skadarnold, 2023-11-03:
> Any chance it's related to the reset line instability/sensitivity that has been seen in other Picogus contexts recently? - probably not, but didn't want it to go unmentioned.
>
> Also, when doing my own Picogus builds, I too was uncertain at times, about the expected status of the LED light on the Pico. All I knew was that an unstable build was often accompanied by inconsistent Pico LED lighting, and that thorough (solder) checks and reflows fixed almost all of the issues of this nature that I encountered. That said I certainly wouldn't discount other possible causes, such as that I initially mentioned.

Good question about the reset line. I haven't seen any other posts about it, but it also crossed my mind that the pico was stuck in reset. I am looking over all my solder work as I have also been wondering if something isn't quite connecting correctly.

arkayii, 2023-11-03:
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

The soldering at the 3 x TSSOP chips are common culprits, for tiny bridging issues. Yours may be fine, but insofar as anywhere is worth checking, that is certainly one area.

Regarding the reset line fixes, there are some forum posts on Vogons (starting around here : https://www.vogons.org/viewtopic.php?p=1205085#p1205085 ) where a capacitor fix has been used by some people, e.g. in the context of Book8088/Hand386 devices. Whether or not this is relevant to your or any other situation, I do not know, but let it not be said that it's gone unmentioned! :)

skadarnold, 2023-11-04:
Well I think I have exhausted all of my troubleshooting for today. I went through and reflowed everything 2 - 3 times now, everything looks great and I am pretty certain there are no micro bridges at this point. I also added a 100nf capacitor as suggested in the vogons thread to help fix any reset bugs as mentioned. Nothing seems to change its behavior. Sometimes it will give me a working streak and initialize perfectly for about 3 reboots, then it stops for a while and will randomly work again for no real reason.

I can see that when it does work, the light on the pico will flash on briefly, maybe a couple of times and then remain solid on after initializing. But if I do not see those first couple of flashes when the computer boots then it will not initialize.

I will give it a try in my 440bx motherboard and see if it behaves differently.

polpo, 2023-11-04:
If you want to completely eliminate the variable of a noisy/glitchy reset line on your motherboard, you can cover the reset pin (B2) on the ISA connector with an insulating tape (Kapton would be best), then use the reset jumper that I see you have to ground the reset line on the PicoGUS board. The pin in question is circled in yellow in this photo:

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

Hopefully the changes I'm introducing in my new designs like switching to a 74AHC14 chip and adding an RC on the RUN pin will eliminate these sorts of issues. If doing the above solves your issue, you can cut the trace going to the reset pin on the ISA connector. The only real downside is that any notes playing will remain stuck playing when you hit reset on your computer, until you run pgusinit to reset the card.

skadarnold, 2023-11-04:
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

I gave this a try but so far no better and no worse. No luck with my 440bx so far either so there must be something off with my build. I will keep trying with the 440bx though.

Do you have any estimate on when you might release the next design? I was considering picking up another set of components but I will probably wait for next revision instead.

skadarnold, 2023-11-04:
I am following the vogons thread now so I can see your plans for the next release. I will move this conversation there as well. I think I can run some debug through the UART and see if I can get some more info from there.

skadarnold, 2023-11-04:
I just made an interesting discovery that may or may not help narrow some things down. When I load the pg-mpu.uf2 it works every time 100%. Anything that initializes the DAC seems to be hit or miss.

skadarnold, 2023-11-06:
I am going to close this since it does not seem to be a short to ground or an issue with the DAC module.

Closed 2023-11-06.

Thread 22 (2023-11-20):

Position of some parts are wrong in JCLPCB

Cologran, 2023-11-20:
Some position of the parts are wrong in JCLPCB.

Look:

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

polpo, 2023-11-24:
Yes, J8 is way off, probably because the footprint for that part is very large (it encompasses the maximum wavetable module size). The origin of the footprint is correct, but for some reason it gets placed there. That's about the only component that they aren't able to auto-correct the position of. You can move it yourself on that screen before proceeding to the next step. The two 3.5mm connectors and micro-USB connector also are a bit off position-wise and can be tweaked as well. JLC is good about double checking positioning/rotation manually before PCBA orders are put into production, but it's best to align things yourself first.

I could fix the alignment of everything in the CPL file that's checked in, but it'd be an awful lot of trial and error that the component placement step can take care of, and if I update the CPL with the KiCad JLCPCB plugin, I'll have to re-correct the positions.

Closed 2023-11-24.

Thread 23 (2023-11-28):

GUS Emulation - Sound Effects in some games, but no Music. Other games crash

mikboy018, 2023-11-28:
So I ordered a couple of the 2.0 models, and put one in a 486, with another in a Pentium 2. They're both giving me similar interesting results, in that I can't get any GUS music to work. I'm pretty sure the hardware is fine, as MPU-401 worked great for Day of the Tentacle, X-Com, and Loom on my old 486. The ultimate talkie edition of monkey island 1 had some problematic music, but since that isn't really official, I don't think its as big a deal as GUS Music for me.

For GUS, I've tried Rise of the Triad (Shareware and Dark War), Raptor, Tyrian, and Jazz Jackrabbit (+ both Holiday Hare 94 and 95).

For Rise of the Triad:
- Choosing Ultrasound for SFX appears to work, although I get no audio
- Choosing Ultrasound for Music crashes

For Raptor (full and shareware):
- Running setup causes no issues. On the Pentium 2, running the full game crashes on Music initialization, while on the 486 it launches, with no music or SFX.

For Tyrian:
- Running ultramid prior to, launching setup, and then choosing Gravis-MIDI causes a runtime error (I can get a screenshot if it's helpful)

For Jazz Jackrabbit (HH94/HH95/CD):
- Setup indicates it picks up the ULTRASND settings ('set ultrasnd=240,1,1,5,5' used, but I've also tried 3 for DMA on both systems).
- Launching the game gives no errors, and sound effects play, but music will not.

I don't know the chipset of the 486 off-hand, but the Pentium 2 is a a socket 1 / ASUS P2B-F (intel 440lx chipset).

Anything else I should try/you'd like to know? I'm pretty new to GUS, so I'm not sure if I missed a step. I did run on both with the latest picogus release and the ultrasnd drivers/patches from the wiki.

mikboy018, 2023-11-28:
Of note, this was the first time my 486 ran Day of the Tentacle without softMPU for my MT-32... I used to get memory errors, but that is no longer an issue!

deepthaw, 2023-11-28:
What version of Tyrian? I've been able to run Tyrian 2000 pretty well perfectly using ULTRAMID and the Gravis MIDI option in game.

mikboy018, 2023-11-28:
Shareware (from an old demo disk I had as a kid) and Tyrian 2000 (from GoG)

mikboy018, 2023-11-29:
Thanks!

Ran both cmod & gusdram on the Pentium 2, as well as the 486.

In both cases, cmod froze, and gusdram reported no issues (photos attached).

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

mikboy018, 2023-11-29:
Ok update for the 486: working great.

I pulled the Aztech Sound Galaxy Washington out, and audio just worked in Jazz Jackrabbit. It's jumper was set to 220, and my ultrasnd variable was set to 240,3,3,5,5 as to not conflict.

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

The Pentium 2 also has a 2nd soundcard, a Creative SB32... think it also conflicts?

polpo, 2023-11-29:
Your autoexec.bat looks OK to me - doesn’t look like anything should conflict. This is feeling like a DMA issue to me given the behavior you’ve described so far. Thanks for all of the detail you’ve given, it’s really helpful!

I have a board with a 440LX chipset and an AWE64 which should be pretty similar to your SB32… I’ll try to see if I can replicate the issue with that and the PicoGUS in the same system.

mikboy018, 2023-11-29:
Nice! Looking forward to seeing what you find on your end.

I did identify my 486 motherboard... [link here](https://theretroweb.com/motherboards/s/unknown-isa-s486) (well, it's 'unidentified' here, but at least it has some detail)

mikboy018, 2023-12-01:
Forward progress!

Raptor (Shareware) is working on the P2. I was using Phil's Computer Lab's MS-DOS mode made easy, and had been updating both autoexec.bat for windows and for the *.pif he created. What I didn't look at was Windows Device Manager, which set the SB32 to IRQ 5 anyway...

I disabled PNP OS in the Bios, Manually set my IRQ/DMA, and it's working now!

mikboy018, 2023-12-01:
I don't know a lot about GUS's, but should this be able to do music and sfx at the same time?

deepthaw, 2023-12-01:
I think most games that support GUS can do sound and music simultaneously on it. It’s all the same thing to the GUS so it can’t even tell the difference.

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

mikboy018, 2023-12-01:
I'm good to close this, unless we want to try some things to see about compatibility with that symphony chip... happy to try stuff/test that as needed.

I mainly have it in the 486 to serve as an MPU-401 card, and it does that well, looking through my launch settings, even monkey island 1 (ultimate talkie) is working.

In any case, thanks for the help!

polpo, 2023-12-01:
I'm glad you've sorted things out! I haven't really used Win9x's MS-DOS mode so I hadn't thought about how that'd change your SB32's settings.

An IRQ conflict definitely explains the issues - for example in Jazz Jackrabbit, the GUS's timer IRQ drives the music playback while sound effects are triggered by the game independently of the music playback routine.

How are things on the 486? Is there still a conflict when you have the Aztech card installed?

mikboy018, 2023-12-01:
There are still conflicts on the 486. It wasn't one of the 'compatible' chipsets, but it seems like its the exact same issue. My autoexec.bat settings are set to that picture I took above.

I could try different IRQ/DMA combinations to see what works. That system doesn't have much in the way of BIOS settings I can modify.

mikboy018, 2023-12-03:
ICU worked to a degree.

I can't disable LPT from the BIOS like I could with the 486, so instead of setting the IRQ to 5 or 7, I went with ICU's suggested default 9(2), and Jazz Jackrabbit worked perfectly.

I went to try Raptor and Tyrian, and Raptor gave no sound. For Tyrian, I didn't attempt, as ULTRAMID threw the following error:
```
configuration file not found in ${ULTRADIR}/midi directory
```
Going to do a fresh reinstall of everything in C:\ultrasnd tomorrow, as  that path is set right (autoexec.bat below)
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

cmodtest also hangs on loading strshine.s3m

mikboy018, 2023-12-03:
No luck yet with Ultramid.

Disabling the Aztech (Sound Blaster Compatible) within ICU, & updating its IRQ to 7 in Autoexec.bat allows SCUMM games to use my Aztech for voice, and the picoGUS as an MPU-401 -- which was my real intended use case on this system. It's a bonus I can play Jazz Jackrabbit on it, especially this time of year.

Games working great:
picoGUS only: Jazz/HH94/HH95 (GoG Copy)
picoGUS (MPU-401): X-Com
picoGUS + Aztech: Any SCUMM games (including talkies)
Aztech only: Halloween Harry

Games not yet working:
Raptor (No sound at all from picoGUS, sfx from Aztech does work -- but not music)
Tyrian (Ultramid not yet working)

Honestly, I'd play raptor/tyrian on the Pentium 2 anyway, so I'm pretty happy with how this is going. Both cards are working great, but I definitely have some resource conflicts to figure out on the old 486.

B24Fox, 2025-10-04:
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

Hi!
Did you by any chance got **Raptor** to work??

I have a SuperSocket7 board (VIA MVP3 chipset), and I have the same issue in GUS mode. When selecting "UltraSound" or "UltraSound Max" in the game's setup. "Music" makes it freeze on game launch; and "Sound FX" just give no sound.

Raptor music when selecting MIDI (i have a daughter-board plugged in) works fine though, in both GUS & MPU-401 modes.

The behavior is the same in both Win98SE & DOS mode.

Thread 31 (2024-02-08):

Any chance to bring MIDI Input support?

Deftaudio, 2024-02-08:
Hi, great work and an amazing project!
Is there any chance to bring MPU-401 MIDI Input support in firmware?
Hopefully you have an extra pin for that. I can use an external optocoupler. Just wondering if it's possible at all in the current design. Thank you!

Deftaudio, 2024-04-11:
Sorry for pinging here again, any update please?

polpo, 2024-04-11:
Unfortunately with the current design it's not possible to support a MIDI input as there are no free pins that can be used for it. There's a UART TX pin exposed on the board, also used for MIDI output but can't be remapped as an RX pin. It may be possible to free up a pin in a future revision and it's something I'll keep in mind.

Deftaudio, 2024-04-11:
Thank you Ian, I understand that you might ran out of available pins. Can you add support for a USB MIDI class compliant device then? This way any external USB MIDI interface will work just fine.

polpo, 2024-04-11:
Oh, that's a really cool idea! TinyUSB can support USB MIDI class devices with this driver: https://github.com/rppicomidi/usb_midi_host
I'll look and see if such a thing would be possible.

kmeaw, 2024-07-03:
Just in case there will be some plans on throwing in some mux to free pins for MIDI input, please consider also having the wavetable header handled separately from the MIDI output - so software could switch between handing over the MIDI data either way (or both, as current PCB does), giving the user choice over the routing.

Closed 2024-04-11.

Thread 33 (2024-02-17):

Compatibility list

pdesrosiers77, 2024-02-17:
HardBall 5 // Fully compatible
Star Wars Rebel Assault // No sound

Weird stuff:
ROTT // crashes after 5 minutes when using PicoGus for both music and sfx. Music alone works no problem.
Doom // I had to download the packages from Vogons to have Ultrinit working. It was the only was to get music working.

pdesrosiers77, 2024-03-27:
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

I transitioned from a TX to a VX and all crashing problems disappeared. Maybe a faulty board...

pdesrosiers77, 2024-08-31:
For Star Wars Rebel Assault, you need to manually add your DMA # beside /d in the batch file REB.BAT. You also need to use pgusinit /gusbuf 2.

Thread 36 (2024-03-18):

Can't program the PicoGUS using Amiga Bridgeboard PC

jfharden, 2024-03-18:
I'm using the PicoGUS in an Amiga 2000 using the A2286 bridgeboard (which is a full IBM AT class PC on a card, an 80286 at 8 MHz), I also have an XTIDE, and a VGA card on the ISA bus, but nothing else.

Prior to 1.0.2 the GUS sound didn't work, but I think fixing the timings for the 5170 has also fixed it for this. GUS sound seems to work perfectly now, as does adlib (I've tried Dune 2: The battle for Arrakis and Planet X-3 for adlib, and I've tried the Legend demo and The Good, Bad, and Ugly demos for GUS sound).

However programming the Gus with `pgusinit /f <file>` doesn't work. It prints a lot of garbled characters. I don't have a way to copy and paste them but you can see in the screenshot attached the garbled errors.

Even after the output in the screenshot the GUS still works, so I don't think it's actually managing to program it at all.

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

If there's anything I can do to help debug this let me know and I will do my very best. It's absolutely incredible to me that this works at all in the Amiga

jfharden, 2024-04-24:
As of version 1.2.0 (I haven't tried 1.1.0) this doesn't happen anymore, occasionally flashing the firmware from pgusinit works, but mostly it hangs after outputting a number of .'s

On one occasion it threw an error saying the picogus wasn't in programming mode and returned to the DOS prompt, but mostly it hangs forever.

jfharden, 2024-04-24:
As a slight aside, the new 1.2.0 soundblaster firmware is working great otherwise with this amiga bridgeboard! I tried planet x3 for adlib mode which works great, and modmxt and played some mod files using soundblaster output.

This is incredible! What an upgrade :bow: Thank you to all who contributed to it!

jfharden, 2024-04-24:
I just realised I haven't mentioned at all that I'm running DOS 3.3, not 6.2 or above as I imagine most people are.

polpo, 2024-04-24:
Thanks for the reports! DOS 3.3 shouldn't be an issue. There have been some fixes over the past few firmware releases to improve bus reaction time and reduce the amount of time IOCHRDY is held, but the chipset used on the Bridgeboard must be especially sensitive. Unfortunately I don't have access to an Amiga with a Bridgeboard so I can't know for sure! But if I do anything to change bus timing in future firmware releases, it will be in the release notes. Good luck and it's great to hear it's working well otherwise!

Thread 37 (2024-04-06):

Crackles and clicks when playing music

Piligrim-77, 2024-04-06:
Hi,
I have assembled three PicoGUS and two of them work fine, and on the third board, when playing music, you can hear clicks and crackles like when listening to a vinyl record.
The problem is observed in the XTC-PLAY player.
The sound is normal in games.
What could be the problem? Is this a defective PCM5100A audio codec?
Link to the recorded audio file:
[https://drive.google.com/file/d/13oy0wXh3Ue7P_ZVYZhUcEBK353x5l1JZ/view?usp=sharing]

nikitalita, 2024-04-21:
There is apparently a known issue with around 10 percent of PCM5100A chips where they refuse to play 21.05khz audio. If this is an intermittent issue that only affects certain applications (particularly when mixing multiple channels), then this is likely it. The solution would be to replace the PCM5100A.

Piligrim-77, 2024-04-21:
I think the problem is not with the PCM5100A. I bought 5 pieces of new chips and replaced two of them. Nothing has changed, the problem remains.
I also tried other programs and games - clicks are also heard in them.
Could it be buffer chips or something else?

polpo, 2024-04-21:
Is the issue audible in non-GUS modes? If it’s only on GUS that points to faulty PSRAM chip (U8) or a soldering issue around that chip. It’s not used in the other sound modes.

Piligrim-77, 2024-04-22:
I checked other modes - when emulating SB, the game freezes, the music is heard for less than a second, then a click and silence. The only mode that works fine is MPU 401 emulation.

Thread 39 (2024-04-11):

Combine all different firmwares in FLASH

jeroentaverne, 2024-04-11:
Hi! I like your project! I noticed you have multiple firmware's which need to be reflashed to select the functionality. I have done some coding on the Pi Pico myself, and I made a tool to combine multiple firmware .bin files into one .uf2 file. A small "bootloader" at the ARM  will jump to  the requested firmware. This way reprogramming to change functionality isn't needed anymore. If you are interested I can share some code parts with you.

polpo, 2024-04-12:
Hi, being able to do that would be amazing. If you have any code examples I'd be very interested!

jeroentaverne, 2024-04-12:
Ok, I will create a demo project and put in on public GIT and give you the link.

jeroentaverne, 2024-04-12:
Here it is: https://github.com/jeroentaverne/pico_multi_firmware
I did not add too many instructions. Let me know if you have any questions. :-)

smymm, 2024-04-23:
Hi!

Amazing job, @jeroentaverne

I did a quick-and-dirty mix of your work and polpo's code and got a working multi-firmware picogus (6 firmwares) and modified pgusinit to manage it.
Only did quick test with the sb, gus and cms modes, but it seems to be working well. If you want to test, here is the uf2 and pgusinit.exe:

[PicoGus-multifw.zip](https://github.com/polpo/picogus/files/15082569/PicoGus-multifw.zip)

The pg-multi.uf2 must be flashed via USB to the pico (it doesn't seem to work with pgusinit built-in flasher).
Once flashed, to change between modes (firmwares), use:

pgusinit.exe /r x

where x is the number of the firmware to boot (0=gus, 1=sb, 2=mpu, 3=tandy, 4=cms, 5=joy)

On cold boot, the default firmware is always GUS.

If I get some time I'll upload the (ugly) code changes somewhere.

jeroentaverne, 2024-04-23:
Hi!
Great to hear it works for you. I will have a look at the code. You could also perhaps decide to stay in the bootloader after powerup and wait till pgusinit is executed. I am sure you will fix the flashing with USB issue.
I still need to order a picogus from jlcpcb. But I follow your project a lot on Adrian's Digital Basement. It gave me a lot of inspiration for my own project.

jeroentaverne, 2024-04-24:
I do not own a picogus yet to try it. I will order a few soon. :-)

jfharden, 2024-04-24:
Hey @smymm I tried writing your firmware to my picogus (the v2.0 hardware) via USB but it fails to write, after copying the uf2 file over the statuslight on the picogus continually flashes and then when it's in the system pgusinit always just says picogus not found. If there's anything I can do to help debug let me know.

This is such a fantastic feature for a fantastic card

polpo, 2024-04-24:
@smymm that's amazing! I'd love to see your code, even if it's ugly. I love ugly code! 😄 I definitely see this being the future of changing modes for PicoGUS.

@jfharden if the status light continually flashes, that could mean there's an issue reading the chip's PSRAM. I wonder what could cause that on this particular firmware...

smymm, 2024-04-24:
Hi!

I made some changes and attached new files (uf2 and pgusinit) here:

[picogus-multifw-1.2.5.zip](https://github.com/polpo/picogus/files/15100184/picogus-multifw-1.2.5.zip)

Now flashing pg-multi.uf2 using pgusinit.exe is working. As the size is much bigger, time needed for flash erase has to be bigger too.

@polpo, @jeroentaverne

I zipped the code changes and attached here:

[picogus-multifw-1.2.5-code-differences.zip](https://github.com/polpo/picogus/files/15100183/picogus-multifw-1.2.5-code-differences.zip)

I think I didn't miss any file, but let me know if something is not there.
As you can see, it's very simple, all merit is for you two. I just merged both codes with some necessary changes for it to work, and added code to make it useful.

@jfharden,

Check with the new file, and also try with pgusinit flash, now that it works.

I only tested this with a v1.1 board and everything is working here, so if someone could test on other board versions and confirm, that would be great.

jeroentaverne, 2024-04-24:
Perhaps generic code like firmware flashing and mode selection by pgusinit can be moved to bootloader.c. Firmware sections can be made smaller and firmware flashing quicker.

jfharden, 2024-04-24:
@smymm I just tried flashing multifw-1.2.5 via usb and it worked!

I tried it out (my setup is a little unusual, it's an Amiga 2000 with an A2286 bridgeboard inside (think of it as a 286 PC on a card, but the amiga 2000 mainboard has some ISA slots which can only be used by the bridgeboard, not the amiga)) and it works fantastic! Playing modfiles in gus mode worked a charm, switching to the soundblaster firmware using `pgusinit /r 1` worked, and then I played modfiles in soundblaster output, and ran planet x3 using adlib which played fine through the soundblaster firmware too.

Incredible stuff!

I can't test flashing the firmware from DOS unfortunately since that already isn't working on the original 1.2.0 firmware. This specific limitation I have is actually what made me very excited about this work since it fixes my inability to change modes without removing the picogus from the Amiga! Thank you!

smymm, 2024-04-24:
@jeroentaverne

About build.sh , it's not needed. Everything is now merged into /sw/release/create_release.sh , it builds the firmwares, the tools you provided and the merge of the firmwares, ...

About code in bootloader. I think it's not great to boot to bootloader and stay there until pgusinit does something. It's important to have a working card working in x mode at boot (gus or whatever) without any program required, asi it is now. That way you can use, for example, an original game that boots from floppy disk and run it with a sound card in an already-working state.

jeroentaverne, 2024-04-24:
I thought pgusinit was always required to setup something. But good to know this is not needed. Using the last sector of flash for mode selection and perhaps IO address setting would be great. I would even suggest to use multiple sectors as some kind of wear leveling.

jeroentaverne, 2024-04-25:
I have an update on https://github.com/jeroentaverne/pico_multi_firmware
The .ld files are now all smaller

smymm, 2024-04-27:
Yay!
Permanent mode for the multifirmware... Finally got it to work, using one page at the end of a standard pico flash (2MB) to store the setting.

I also made other changes and proper code for the firmware mode change implementation in control register area.

Here is the new uf2 and the new pgusinit.exe:

[picogus-multifw-1.2.6.zip](https://github.com/polpo/picogus/files/15139633/picogus-multifw-1.2.6.zip)

New usage for this version:

```
    pgusinit   /m x [d]  - change card mode to x (1=gus,2=sb,3=mpu,4=tandy,5=cms,6=joy)
               the optional parameter 'd' makes the mode permanent at boot
               (Only if pg-multi.uf2 is flashed)
```

Examples of use:

- You have default mode as GUS mode on boot, want to change mode to SB, but only temporarily:

`    pgusinit /m 2`

- You want to change the default (permanent) mode of the card to SB mode, and the next system cold boots / hard resets / power off you want to stay in SB mode without using pgusinit:

`   pgusinit /m 2 d`

This way, there is no need to take care of SPI flash wear, because the permanent change would be done only a few times (maybe only one, depending on your preferences)

I tested and it worked very well on my system. Please, test if you can and report :)

I plan to upload the modified sources for this new features very soon. I will try to get used to git (I'm new to it) and fork the project and submit the changes (maybe as a pull request, or what would be the best way..?)

@polpo @jeroentaverne

jeroentaverne, 2024-04-27:
Great! Can someone in the EU supply me with a PicoGUS?

smymm, 2024-04-27:
Finally I created the fork and sent the pull request with the modified code. It's my first time with git/github, so I hope erverything is well done.

I uploded the compiled release to my fork, too:
https://github.com/smymm/picogus/releases/tag/picogus-multifw

Thanks to everyone here! and sorry for my newbie code!

@jeroentaverne
/m 0 does nothing.

skadarnold, 2024-04-27:
I just tested this on a v1.2 card, flashed with supplied pgusinit straight from DOS and I can confirm this is working. Switching modes on the fly working in games without reboot.

jfharden, 2024-04-27:
I just tested this on a PicoGUS 2.0 (in an Amiga 2000 being used by the A2286 bridgeboard) and it worked great.

I tried using modmxt playing some mod files in both Sound Blaster and GUS mode, I also tried Planet X3 using adlib sound on the sound blaster mode. Finally I tested that the mode survives reboot which worked like a charm.

skadarnold, 2024-04-27:
GUS could use an auto initialize after switching modes (and maybe others I haven't tested). That way it saves having to run pgusinit again to initialize or else it won't work.

jeroentaverne, 2024-04-27:
Nice! A few small comments: The FLASH writing does not need to be in the bootloader I guess. Delay between erase and programming is not needed. Erase will block anyway. And perhaps keep the indents in the code the same.

polpo, 2024-05-04:
The `delay(500);` between erase and programming is usually not needed. I inserted it to account for erase time on old firmwares using the pgusinit protocol v1 on chipsets that do not tolerate IOCHRDY being held low for too long and release the bus before the operation is complete. It's been a while since firmwares with the v1 protocol have been current... I might take this backwards-compatible flash operation out eventually especially since I'll probably make a protocol v3 to handle storing pgusinit settings permanently in flash.

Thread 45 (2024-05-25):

Freezing with System Shock 1

AhmedAbdulFaisal, 2024-05-25:
I am trying to run System Shock 1 with the picogus and it oftentimes freezes up, forcing me to reboot my computer. This is a game which utilizes a bat file (shockgus.bat) to actually load the patches before playing. The card works fine for other games like Descent, DOOM, Epic Pinball, and Jazz Jackrabbit with no freezes.

When I use the Soundblaster 2.0 firmware and delete the SET commands it detects fine within the setup program and the main menu, but it freezes up when I load up a game. Sometimes when using the GUS version of the card it will lock up after a while of playing around. In both cases the system eventually locks up.

I don't know if it's a resource conflict, I have a networking card which is disabled within the autoexec sometimes and it has no issues when working with other games (for instance, IPX-multiplayer DOOM). I'm guessing it's some sort of issue with System Shock and the Gravis Ultrasound, would it be a good idea to install another sound card just for this game?

Here are my specs:

Video Card: Trio64v
Motherboard: Supermicro P5StE (American Megatrends, Intel 430HX)
CPU: Pentium 133 (non-mmx)
Sound Card: PicoGUS configured at IRQ5, Port 240, IRQ 5 and DMA 1
Networking Card: 3COM Etherlink Combo ISA card

My Autoexec for the ultrasound is:

SET ULTRASND=240,1,1,5,5
SET ULTRADIR=C:\ULTRASND
C:\PICOGUS\PGUSINIT.EXE

trumpetlicks, 2024-11-17:
Im having this problem with DOOM.  I am running (currently) a very simplisitc setup of an:
Abit AB-AX5 MOBO
Intel P233 MMX
64 MB RAM
1 MB 1GUI6440 Graphics card
and the PicoGUS

It runs just fine with no hickups in sound blaster mode, but completely freezes the rig (not even playing, but just in the intro) in GUS mode.

in Sound Blaster Mode, it is setup for
220, 5, 1 (Default)

in GUS mode
240 (rest the same as SB mode)

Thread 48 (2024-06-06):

Where am I going wrong?

Pontiac76, 2024-06-06:
Note: I don't have another motherboard with ISA on it, so I'm kind of stuck with this one.

I bought a PicoGUS a couple weeks ago, and just tonight I'm trying to get this thing rolling.

System Stats:
486DX2-80
Trident 512k VGA Card
XT-IDE Board, configured at $D000 and $360, with an IDE2CF drive plugged in, 2Gig CF running MSDOS 6.22.
PicoGUS set to IRQ 5, DMA1, just as it was right out of the box.  (Twin jumpers on DMA1)
Additional card for serial, IDE and FD, but, IDE is disabled via jumpers.  This card is set to run at $C800.
100mbit D-Link DE (Or DF? Through way right at the bottom) 220T NIC, running at packet int 0x62, 0x300, IRQ3.

Software:
- Downloaded the 1.2 package today, and extracted it to the CF
- Downloaded the GUS software and extracted it to the CF

What I've seen since the initial plugin:
- The yellow blinkie light shows up, and stays steady on when plugged into the motherboard.

Actions I've taken:
- Plugged the GUS into my Win10 PC via USB, eventually found the RPI drive, initially copied the SB UF2 over (Since I want minimal SB)
- After dragging the UF2 over, it seemed to have rebooted, noticed the LED on the GUS light up, drive mount went away.
- Plugged the GUS into one of the 3 spare ISA slots, pgusinit didn't see a card.
- Shut down the machine, moved the card to another slot, reran pgusinit, again no card.
- Found instructions about setting the environment.  Wrote a batch file to set the vars.  Tried 220 and 240, still no go.
- Plugged the GUS back into Win10 and put the pg-gus.uf2 on
- Same results.  LED turns on, drive goes away, plug it into another random ISA, still can't find a card.
- **_Went minimalistic_**; Pulled all cards except video, the PicoGUS and the Floppy controller.
- Booted to MSDOS 6.22 with no drivers
- Switched to the v1.2.0 PicoGUS disk
- Ran pgusinit, no parameters, still found no card.
- For fun, entered the environment variable to set the address, and still no go (With the GUS UF2 installed)

I'm at a loss on where to go from here.

The card "seems" OK since I can put the firmware on the drive via USB and things do their things, but I'm not sure where to go from here now.

Pontiac76, 2024-06-06:
I think I found a regression.

I went to v1.1.0 and run the pgusinit and I got garbage back.

Pontiac76, 2024-06-07:
I tried going back a version to 1.1.0.  I see that PicoGUSinit is 2.0.1 versus 2.1 in 1.2.  I pulled the card out and plugged it back into my Win10 machine, put the v1.1.0 GUS firmware on, it did its spiel, plugged it back into the 486 and I still can't see the card.

polpo, 2024-06-07:
What is the ISA speed set to, if your BIOS gives you the ability to change it? Because you have a 40MHz FSB that may mean by default it's running ISA at a higher speed than normal. And what chipset does your motherboard have?

This is a bit of a tangent, and while it wouldn't prevent the card from being detected at all like what you're seeing, one thing to watch out for is that the PicoGUS in GUS mode (and real GUS) don't play very well with the XTIDE hardware, for reasons still unknown to me. It does work fine with the XTIDE Universal BIOS, though, so if your motherboard's BIOS won't recognize your CF card, I'd recommend using XUB along with the IDE on your super-IO card, and you'll get better performance that way as well.

Pontiac76, 2024-06-07:
https://media.discordapp.net/attachments/762944299767037972/1248706208957730936/20240607_143003.jpg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

That's the closest thing I could find to setting the ISA speeds.  I changed the ISA Bus Refresh to Slow and brought it from 1/1 to 1/64, but still have the same results.

As for the chipset, there's nothing on the bootup screen to indicate anything, so here's a pic of the mobo.  (I removed the floppy cable for the shot)

https://cdn.discordapp.com/attachments/762944299767037972/1248708132989833399/20240607_143903.jpg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

A940243RD is all I have that's questionably readable in the photo.

Checking the manual for this board (Closest i could find) https://stason.org/TULARC/pc/motherboards/A/AMPTRON-INTERNATIONAL-INC-486-DX-6900-VER-1-75.html

I pulled JP16 (Bottom of the page) that says if I pulled JP16, it'd take the VL Bus Speed down to under 33mhz, still no answer.  I then pulled what I think is JP17 (Not labelled but on the same header as JP16) and again no change.  I've been using 1.2.0 for this specific test.

Oh, one other hardware thing is that I am not using a modern PSU.  It's the original PSU I received with the case, which is full AT mode.  It does have a -5v line.  I did have a modern supply with an adapter cable, but found out that some cards require the -5V line, so been risking it.

Pontiac76, 2024-06-07:
Actually, I just found a setting that didn't look like it was directly related to the ISA bus...

https://cdn.discordapp.com/attachments/762944299767037972/1248716921499811861/rn_image_picker_lib_temp_38e64db8-fa71-43f4-a5e9-59348254b450.jpg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

The PCLK/2 was the culprit.  If I switched it to /3, it works.  I may be a bit unstable now with the 2-1-1-1 WS, but I'll deal with that later.  (I didn't think to check the settings on that before I made changes)

I found this out by going back to basics and trying to set everything to as "stock" as possible and let the computer decide what it should be.  When I set the Auto Config to "Enabled" the GUS started to work.  So I started playing with the Cache Read Hit Wait States, still to no avail.  I then went down to the AT Clock Speed, hit to /5 initially, and it worked!  So switched to /3 to work "up" from 2, and this time it worked.  I got a proper answer, noting that the Adlib firmware was installed, which is correct from 1.1.0 when using the 1.2.0 version of pgusinit.

Thanks for the hint on this.  At least now I know I don't have a defective card.

Next step is to put the rest of the hardware in and see if I can get things rolling.

I HAVE heard rumors about the XTIDE not being happy about other things.  But at a minimum specification I know things are working, so I can go up from there.

Thanks again!

Closed 2024-06-07.

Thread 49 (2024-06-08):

Joystick input affected by GUS utilization

ehoughland, 2024-06-08:
In certain games, the joystick input is affected by the utilization of the soundcard. For example, in Super Street Fighter 2 Turbo, if GUS firmware is loaded with joystick support turned on (/j) AND the card is used by the game for music and sfx, the joystick will exhibit random inputs. If the game instead is directed to utilize another soundcard within the system for music and sfx (in this case, an ESS Audiodrive), the joystick behaves normally.

polpo, 2024-06-08:
Hi, I have also experienced this on the PicoGUS in GUS mode with any game that uses DMA for streaming audio. I've also experienced it on a real GUS with a real gameport joystick. On the real GUS it's not as bad but it still can make the game unplayable. I don't really think there's a way to really fix this, unfortunately. I'll keep this issue open until I create a "Known Issues" wiki page.

ehoughland, 2024-06-08:
Interesting, thanks for the reply. Any chance six button support or remapping is coming? 🤞

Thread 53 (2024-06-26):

Can't init femto with ISA adapter

kp73, 2024-06-26:
Hi, trying to init and get an error;

`ERROR: PicoGUS card using protocal 221, needs 2`

Using a femto with ISA adapter from Tindie https://www.tindie.com/products/polpo/picogus-femto-edition-for-pocket-386-and-isa/

Programmed the Pico by holding BOOTSEL and dropping pg-gus.uf2 from picogus-v1.2.0 release (unplugged from femto).

Stuck it in my 486 using the ISA adapter, but no joy.  Will try it in the book 8088 when I find the power adapter :)

A standard PicoGUS v2 works fine in the 486

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

kp73, 2024-06-26:
Seems to work OK on the book808

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

Any idea why it won't work with the ISA adapter?

polpo, 2024-07-08:
Hi, sorry for the delay in getting back to you. There are probably solder bridges on the ISA adapter on the fine pitched pin connector that the Femto plugs into. Take a close look, if you are handy with soldering you can clean any bridges up with some flux or solder braid. If not I can send you a new one - send me a message on Tindie and I'll take care of you.

Closed 2024-07-08.

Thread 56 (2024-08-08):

New RP2350B

DPRCZ, 2024-08-08:
Will you plan to evolve the hw of board with new chip?  48 I/O 5V tollerant....

DPRCZ, 2024-08-10:
OK, I read your statement to new RP2350 on vogons.com

DPRCZ, 2024-08-10:
Done

Closed 2024-08-10.

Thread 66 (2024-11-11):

GUS Compatibility regression in v2.1.0 & existing issues

vermian, 2024-11-11:
PicoGUS v2.0 Setup:
Port 240, IRQ 5, DMA 3
Firmware v2.1.0

Using MS-DOS v7.1

GUS Issues:
-Jazz Jackrabbit CD - Music doesn't play at all with firmware v2.1.0. Sound still works fine. Everything including music was working fine with firmware v1.2.0.
-Tyrian 2000 (v3.0) - Music is all weird with firmware v2.1.0 and notes are stuck after you leave setup. Comparing with v1.2.0, Ultramid didn't even detect the GUS.
-Minebombers (v3.11) (1996) - Music doesn't play at all, but sound effects work fine. Same issue with both firmware v2.1.0 and v1.2.0
-X-COM: UFO Defense v1.4 - Firmware v2.1.0: music works, but sounds don't play at all. Game v1.2 - sound is just random instrument noises? (GUS music was not implemented in game version v1.2 yet AFAIK)

polpo, 2024-11-13:
Hi, thanks for the report. Music not playing but sound effects being OK points to issues with the IRQ - is IRQ 5 shared with any other cards in the system? Of the titles you mention I've only tested Jazz Jackrabbit in depth on v2.1.0 firmware (it ran all weekend at VCFMW with no problem) but I will look at the others. I don't have a 440ZX system but I have a 440EX and 440BX that I can test on.

vermian, 2024-11-13:
I have a Yamaha Audician 32+ but it's set to Port 220, IRQ 7, DMA 1. If it was an IRQ issue, wouldn't it also affect the older firmware?

polpo, 2024-11-23:
@vermian - I've made a special branch that builds the GUS firmware without MPU support as that's the most likely cause of the regressions you're seeing. Can you download the "PicoGUS Firmwares" artifact at the bottom of this page: https://github.com/polpo/picogus/actions/runs/11989912827 and try it out to see if it improves compatibility for you?

vermian, 2024-11-26:
> @vermian - I've made a special branch that builds the GUS firmware without MPU support as that's the most likely cause of the regressions you're seeing. Can you download the "PicoGUS Firmwares" artifact at the bottom of this page: https://github.com/polpo/picogus/actions/runs/11989912827 and try it out to see if it improves compatibility for you?

Yeah, looks like that fixes the Jazz Jackrabbit music issue. So both music and sound work fine again.

Other differences:
-Minebombers (v3.11) (1996) - frozen black screen on game start. Before I at least had sound effects.
-X-COM: UFO Defense v1.4 - Both sound and music work now, though music seems to have stuttering in the intro sequence and during the main menu. I didn't hear stuttering music in-game but I only played for a couple of minutes.
-Tyrian 2000 (v3.0) - not sure if it sounds different because I only listened to the music a short while before but maybe it sounds fine now, but I still got a frozen note during the game on the main menu after a demo sequence.

vermian, 2025-06-29:
Tried newest v3.1.0 firmware and Jazz Jackrabbit, Epic Pinball, Minebombers have no music but do have sound, similar to v2.1.0.

p-rintz, 2025-07-16:
Funny enough I have music in Jazz Jackrabbit, but no music in Duke 3D or Descent. (Sound effects work everywhere).

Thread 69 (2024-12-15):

“Building your PicoGUS” wiki page full of errors

JoopIdema, 2024-12-15:
The “Building your PicoGUS” wiki page states it describes buiding a v1.2 PicoGus.

But the link to the BOM.csv does not work and the link to the Mouser Projects list the components needed for the v1.1 PicoGUS. I did not notice this so I got several wrong and missing components resulting in placing extra order and thus costs.

Also the link to the interactive BOM is for the v1.1 version, so useless when building a v1.2

Furthermore the BOM (DAC module) v1.2 found hw folder lists R7,R8 to be mounted but when using a DAC, R8 and R7 do not need to be mounted!

Also adding a picture of a complete board might help when building it.

All and all, for me, it let to a very frustrating project to build.

korneliuszo, 2024-12-15:
https://github.com/polpo/picogus/blob/main/README.md#license
https://spdx.org/licenses/CERN-OHL-P-2.0.html

karoliskap, 2024-12-29:
@JoopIdema can you post what exact components are missing or wrong? I about to order parts from Digikey, so it would be very helpful.

JoopIdema, 2024-12-30:
I had to order U2 and U10 extra. And some caps I believe.
You can find the BOM file for the 1.2 version of the PCB in https://github.com/polpo/picogus/blob/main/hw/BOM%20(DAC%20module).csv

oXL0C0Xo, 2025-02-23:
Just looking this over as I plan to build a card that uses the DAC module. It was mentioned that R& & R8 do not be mounted when using a DAC module by the OP; is that the case? The reason I ask is because they are still listed in the BOM in the project folder.

crtified-retro, 2025-03-25:
Sorry that the build guide has become a little out of date. I've long meant to contribute some updates, but life is busy. Seeing this discussion gives me impetus to get to work. I'll try to get some updates written up and proposed within the next month.

> Just looking this over as I plan to build a card that uses the DAC module. It was mentioned that R7 & R8 do not be mounted when using a DAC module by the OP; is that the case? The reason I ask is because they are still listed in the BOM in the project folder.

R7 and R8 are not meant to be in the BOM for the DAC module version of the build. So leaving them out, as you have done, is exactly right.

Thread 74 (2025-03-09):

USB gamepad emulation not working PicoGUS 2.0 on firmware 2.2

nyandeyanen, 2025-03-09:
I've been attempting to get a gamepad working in DOS on the PicoGUS under firmware 2.2 for a while, I've bought several gamepads to try with the PicoGUS' USB port including the following:

Logitech F310 Gamepad (switch set to Xinput mode)
8bitDo Utimate Wired C Controller for Xbox
Sony DualShock 4

I saw the DualShock 4 listed in the hidd_app.c in particular, but so far, well, no joy. Enabling the joystick with /joy 1 shows that pgusinit enables the port, but none of the listed gamepads are detected. It doesn't seem to be dependent on mode, as sb, gus, tandy and mpu401 modes all seem to fail. In each case going into any applicable game setup program, for example setup.exe in Wacky Wheels, indicates that there's no joystick attached to the computer. I've tried this with the onboard sound (ESS Solo-1) disabled in the BIOS, and with the Solo-1 enabled but with its gameport disabled, and in all cases no joystick is found on the port. The DualShock 4 in particular displays an orange light in the back of the controller where typically it displays blue light when plugged into my "modern" computer (Debian Linux).

My system configuration:

Biostar M6TEA / Intel 440EX chipset with a Celeron 266
Windows 98SE set to boot into DOS mode directly by disabling BootGUI in msdos.sys
Either an EMS or XMS configuration with EMM386 and himem.sys doesn't seem to make a difference, neither does using JEMM
A Dreamblaster is attached to the PicoGUS' waveblaster header

FWIW, the sound modes all work quite well, perhaps some pitch glitches in Tandy mode (Castlevania in particular) but otherwise I'm very happy with the card. I've even used PicoGUS' MPU mode with the ESS Solo-1's SB emulation for the Dreamblaster by disabling the MPU port on the Solo-1. This is truly an outstanding piece of hardware, well worth putting together a system with ISA slots. :)

nyandeyanen, 2025-03-17:
I've continued attempting to get the gamepad support working since last week, using the DOS Thrust program by Bret Johnson I'm able to monitor what the system sees when the /joy flag is set to either 0 or 1. When the PicoGUS is set to joystick disabled, the thrust program shows all 4 buttons (1 and 2 for both joysticks) as being missing rather than "Off". When the PicoGUS is set to joystick is enabled, it reports the buttons as being constantly set to "On"/pressed. Neither mode reads out any axis data, not surprising when it's disabled, perhaps somewhat surprising when it's enabled. The PicoGUS is in usb mode to avoid any possible issues with sound modes.

I've ordered a PicoGUS 1.2 board kit and a Pico W to see if I can reproduce the problem on a different board, hopefully I'll get better results once that comes in. I'll also be looking into the picogus source to hopefully understand what's happening here better.

polpo, 2025-03-17:
Hi, sorry you're having problems with the joystick emulation. It should work fine on the PicoGUS 2.0 and firmware 2.2.0 (there was just [a video on the ctrl-alt-rees YouTube channel showing it working](https://www.youtube.com/watch?v=z4NYW5GQ3vc)), but it is kind of picky about what joysticks it supports. For example, I have a Logitech F310 and cannot for the life of me get it to work. I can't speak for how the 8bitdo works, but the DualShock 4 should be fine. I can test DS4 support again just to make sure it should be OK.

Just to be sure – it looks like the Biostar M6TEA has onboard audio and game port. Is the onboard game port disabled? Unfortunately game port emulation cannot coexist with another game port in the system.

In general, gamepad emulation needs a big overhaul, not only to support more joysticks but provide better troubleshooting support. For example, helping people answer the questions "does the PicoGUS even see my joypad?" "are there other game ports in the system?" would help a lot.

nyandeyanen, 2025-03-17:
Hi,

Thank you for your response, and for this amazing card! The gamepad support is disabled on the M6TEA's onboard ESS Solo-1 sound chip by editing the C:\ESSOLO.INI file in a hex editor and changing the gamepad address field to an invalid address prior to running the essolo.com DOS driver. The driver reports that the gamepad port is disabled along with displaying the address/dma/irq/MPU-401 information. I set the ESSOLO.INI file to readonly afterwards to avoid the Windows driver making changes to the configuration.

When attached to the system's USB port via a hub in this configuration I was able to get the Logitech F310 working in Dinput mode under DOS using the USBDOS suite, loading the USBUHCI, USBHUB and USBJSTIK drivers while the PicoGUS' joystick port is disabled. Notably the DualShock 4 doesn't work in this configuration, but it's possible to use port 201h with the F310 from both the Thrust utility and Commander Keen 4 - although not for some other games. The DualShock 4 does show up in Windows 98's "Gaming Options" control panel as a "Wireless Controller", so it can work on the system via USB, just not on the PicoGUS' USB port. FWIW I have a Logitech Wingman Precision connected to the motherboard's gamepad port which does work in DOS when the motherboard's built-in gamepad support is enabled on port 201h in the ESSOLO.INI file.

I've started to think that perhaps the PicoGUS 2.0 card I received might have a hardware issue, although everything seems to be working except for its USB port. The 1.2 kit should be arriving tomorrow, once I have time to assemble it I'll see if I get different results with that. If the 1.2 board works maybe I'll go poking around the 2.0 card's USB port with a multimeter looking for bad traces or solder joints.

Best,
Les Barrows

nyandeyanen, 2025-03-22:
The 1.2 board arrived a bit later than expected, and I noticed that of course it doesn't have a joystick USB port as that's new with 2.0. Oops. I'm a bit hesitant to remove the 2.0 from a system where it's working perfectly otherwise as a MPU-401 wavetable card and GUS, but I suppose my Pocket386 will now get a PicoGUS (and WiFi!).

crtified-retro, 2025-03-25:
You can enable the joystick USB port functionality on a PicoGUS 1.2, by closing the USBPWR jumper at the top right of the PCB, and using a USB OTG cable (MicroUSB male to USB A female) in the Raspberry Pi Pico's MicroUSB port.

I've never used that function so I can't speak as to it's operational details.

ValadAmoleo, 2025-04-25:
I've just bought a PicoGUS 2.0 and I'm also having joystick woes. With /joy 1 used I still can't get a wired official Xbox 360 controller to work. It should just be a matter of plugging in, doing pgusinit /joy 1 and starting a game (eg Wolfenstein 3D), right?

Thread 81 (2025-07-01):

CD ODE issues when using bat files, long time to start certain games and more

vermian, 2025-07-01:
PC Setup:
Asus P2-99 (Intel 440ZX)
Intel Pentium 2 233MHz @ 166MHz (Klamath) (Slot 1) - 66MHz FSB x 2.5 CPU Multiplier
Voodoo3 3000 (AGP)
PicoGUS (ISA)
Yamaha Audician 32+ (ISA)
128MB SDRAM (1 DIMM)
120GB Intel SSD (SATA) + SATA->IDE Adapter

Using MS-DOS v7.1

Issue 1:
Game: Bedlam (1996)

I have a bat file that mounts "bedlam.cue", then launches the game, however, even when adding a pause in between and waiting 60 seconds, it seems like the game doesn't recognize that the CD is inserted (only thing affected is the lack of CDDA music). If I mount the same image separately, and then launch the game, either the exe directly or through a bat file, the CD seems to be recognized and the CDDA music plays.

bat file looks like this (pgusinit folder is included in path):
```
pgusinit /cdloadname bedlam.cue
pause
bedlam.exe
rem below is for fixing graphics mode on exit
mode 80
```

Issue 2:
I'm sometimes getting a weird issue when I mount a different CD image but for some reason it either doesn't read it properly - folders inaccessible or most files not listed, or sometimes it says it mounted the new image, but the files and music are all from the previously mounted CD image. Seems like restarting the PC fixes this, but not sure how to duplicate yet.

Issue 3:
Some games take a while to load or even exit.
Rayman (1995) for example takes quite a while to start up (~1 minute) (max install size)
Time Commando (1996) can take a while to start up as well as exit the game (~1 minute each)

I have experienced these issues with 2 different USB sticks so I don't think that's the issue, and if restarting the PC fixes it, I also don't suspect data corruption.

vermian, 2025-07-02:
More DOS Testing with SWIV 3D (1996), it seems like after mounting the bin/cue, the first time you run swiv_dos.exe, it doesn't find the CD, but the second time you run it, it finds it and works fine. Doesn't seem like a timing issue as waiting before launching the exe doesn't seem to make a difference. Oddly, I can use this game as a weird workaround to launch Bedlam through a batch file by having the bat mount the Bedlam bin/cue, change directory to SWIV 3D, launch the game which fails and exits to DOS after a second, then change directory back to Bedlam and load bedlam.exe. Seems like once it tries accessing something on the disc the first time, something changes and the second attempt works? The weird workaround works every time.

vermian, 2025-07-04:
The issue doesn't happen with all games. Yeah I'm using the most recent pgusinit release.

RetroLoom, 2025-07-05:
I tried testing with Bedlam (1996), but so far I am not having any issues. After several tries with loading a different image in between it has loaded every time without issue.

I used this in my bat file

pgusinit /cdloadname bedlam.cue
f:
bedlam.exe

f: drive being the PicoGUS ODE. Probably unlikely, but it might be good to try refreshing the drive load before loading the file. Otherwise I am not sure how else to test at the moment.

I am on a Pentium MMX 233Mhz, 128MB, Orpheus 1, so not too far off from the PC specs you are using.

RetroLoom, 2025-07-06:
> It works fine if you run it like that since it runs the bedlam.exe off the CD. You need to run setup.exe and install the files to HD and make the bat run the bedlam.exe from your C: drive. While running it off the CD works, running most of it off the HDD/SSD is much faster for loading.

Ok. I will test from loading it from the HDD and see if that changes anything for me.

RetroLoom, 2025-07-08:
> Oddly enough, even if the same bedlam image is already mounted, if I run the bat which remounts the image, the CDDA doesn't work. I can try a 3rd USB stick but I'm not convinced that is the case.
>
> Edit: the main issue is the CDDA audio not loading. The game itself still loads fine for me regardless. You are starting the first mission to check, right? The main menu music is not CDDA AFAIK.

Thanks for clarifying this, I understand what you are saying now and can replicate the same issue. CDDA audio is not loading correctly, and sometimes I seem to have other weird issues like the previous loaded image stays loaded instead of bedlam. I will look through some code, but it might be deep to find exactly where this bug would source from. Kevin might have a better idea.

schlockorama, 2025-09-21:
I am using BAT files to swap discs, so I can go easily switch between games.

The BAT file will say:

PGUSINIT /CDLOADNAME "AITD.CUE"
INDARK

Picogus accepts the command and I see:

CD Image loaded: AITD.CUE

The game will load and crash saying "ERROR: CD Not Found"

I will then go to my CD rom drive which is (O:) and use DIR/P to see what's on the CD drive.

The CD rom drive will show the volume label, BARIS, since I was last playing Buzz Aldrin's Race Into Space before I tried to play Alone in the Dark.

Sometimes the CD rom directory will also be stuck in a directory other than it's root drive.

Let's say I try to play Alone in the Dark again after playing a few games and I see picogus has loaded the image correctly.

Alone in the Dark will now crash in a different area when you select your character and the first voice file is loaded (error message missing voice file).

I will check the CD rom directory again and I'll see O:\AL (since in this case I was last playing Alien Legacy and the drive is stuck in some previous directory that game was using).

I have tried adding "PGUSINIT /CDLOAD 0" before "PGUSINIT /CDLOADNAME "AITD.CUE" to try to unload the drive first and then load a new image, but doesn't seem to help any.

Even if I encounter the error, some games will swap normally like for instance Alien Trilogy doesn't seem to care when using BAT files.

On a fresh computer start, Alone in the Dark 1 will start first time every time with the bat file.

vermian, 2025-09-21:
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

I ran into this issue a few times before but I've mostly avoided it for a while. My batch file also switches to USB mode (to make sure the PicoGUS isn't in some other mode) then waits 2 seconds using a program called sleep.exe before loading a CD image (otherwise the PicoGUS isn't ready), so I wonder if setting the mode again on the PicoGUS helps this issue. Also I'm using DOS 7.1. Windows might behave differently since it's a different driver.

schlockorama, 2025-09-22:
> I ran into this issue a few times before but I've mostly avoided it for a while. My batch file also switches to USB mode (to make sure the PicoGUS isn't in some other mode) then waits 2 seconds using a program called sleep.exe before loading a CD image (otherwise the PicoGUS or something else in the chain isn't ready), so I wonder if setting the mode again on the PicoGUS helps this issue. Also I'm using MS-DOS 7.1. Windows might behave differently since it's a different driver.

This is my PC Setup:

120MHZ Pentium 1 (Overclocked to 133MHZ)
Intel Advanced Zappa Socket 5 Motherboard
64 MB RAM
Voodoo 1 3D Graphics Card
S3 Trio 64+ 2D Graphics Card
Soundblaster 16 Multi CD
3 X 8GB CF to IDE Hard Drives (24 GB Total in 12 Partitions)
Picogus 2.0 (Firmware 3.2)

I'm using MS-DOS 6.22. Where can I get that sleep.exe you mentioned? I am using a Launchbox for DOS frontend setup, so it's very annoying to not be able to swap games on the fly consistently. It's the only reason I bought the Picogus was for the CDROM emulation since being able to store all those large bin/cue files and isos off hard drive is very handy when you have a 8GB hard drive motherboard limit.

schlockorama, 2025-09-22:
> My batch file also switches to USB mode (to make sure the PicoGUS isn't in some other mode) then waits 2 seconds using a program called sleep.exe before loading a CD image (otherwise the PicoGUS or something else in the chain isn't ready), so I wonder if setting the mode again on the PicoGUS helps this issue.

I can consistently get this error to happen on Alone in the Dark 1 for whatever reason (It uses redbook audio maybe?).
The problem will occur without using bat files also.
I tried using the pgusinit /mode usb at the top of the bat file to ensure it's in usb mode and seems to have no effect.
I tried using cdload 0 with no effect.
I tried using cdload n (n is the number for iso or cue) instead of cdloadname and still same issue.
I've used the pause command and waited a long time between swapping discs with no effect so I don't think it's a timing or "cd loading" issue.
There is definately something wrong with the picogus not wanting to change discs.
I've even had it occur right from the start where I try to load the first game.
I might have to go back to the old way of using SCSUCD (can't stream redbook audio, iso only, and takes up hard drive space, but at least consistently works!) to load images for these particular tricky games until a fix is available.

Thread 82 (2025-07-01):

Feature Request: Option ROM support

Peckmore, 2025-07-01:
Apologies if I've missed this being discussed before, but would it be possible to add support for loading custom option ROM's via PicoGUS? I'd love to be able to use [XT-IDE](https://www.xtideuniversalbios.org) in my machine, but don't currently have any cards that support option ROMs, and thought this could be a useful addition?

yuv422, 2025-07-15:
I think this would be an awesome feature!

I'm not sure if it's possible though. I have next to no hardware knowledge but I suspect that the picogus might not be wired up correctly to behave as an Option ROM. It looks like the MEMR line and the upper address lines aren't wired up from the ISA connector. Hopefully someone with more knowledge could let us know if this is in fact the case.

I'd also be worried that the Pico might not have time to initialize before the bios starts trying to execute the Option ROM. I'm not sure what the startup time is like.

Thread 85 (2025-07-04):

Feature Request: CD image list with page breaks/pauses

vermian, 2025-07-04:
If you go over a certain amount of CD images and want to list them with "pgusinit /cdlist", it only shows the bottom of the list. Could you add an option to prompt for a key press to go through the CD image list a page at a time?

vermian, 2025-07-07:
Sure, I can try testing it. Thanks!

RetroLoom, 2025-07-07:
You can find my fork and current working branch release [https://github.com/RetroLoom/picogus/releases/tag/v3.1.01beta]here (url)

vermian, 2025-07-08:
I did some testing on your build, though not all features since I already have a SB-compatible card so I can't really use the PicoGUS in that mode, but it seems to work fairly well overall. CD list page breaks work, CDDA volume works. It also fixed a GUS regression in firmware v2/3 that broke the music in Jazz Jackrabbit and Epic Pinball for me.

One little thing that is missing is when you run pgusinit, in v3.1.0 at least, it would state the currently mounted CD image but your build appears to not do that.
I also noticed it defaulted to a main volume of 0 after flashing your build's firmware, is that a bug or on purpose?

vermian, 2025-07-08:
Yeah, it seemed to save properly afterwards.

vermian, 2025-07-13:
Yes, pretty sure, but I can try testing it a bit more. I just noticed it last night.

vermian, 2025-07-15:
> New beta releases with a couple of fixes. [v3.1.2beta](https://github.com/RetroLoom/picogus/releases/tag/v3.1.2beta)

Looks like both new fixes work (only tested CDDA volume though).
I'm hoping you'll also get to making it list CD images in case you type some invalid image name, as discussed earlier.
I was also wondering if there is a CD image limit since it seems like typing anything above "pgusinit /cdload 255" doesn't seem to register as a valid command. With 1-2TB USB drives nowadays I think somebody could reach it, lol.

RetroLoom, 2025-07-17:
> > New beta releases with a couple of fixes. [v3.1.2beta](https://github.com/RetroLoom/picogus/releases/tag/v3.1.2beta)
>
> Looks like both new fixes work (only tested CDDA volume though). I'm hoping you'll also get to making it list CD images in case you type some invalid image name, as discussed earlier. I was also wondering if there is a CD image limit since it seems like typing anything above "pgusinit /cdload 255" doesn't seem to register as a valid command. With 1-2TB USB drives nowadays I think somebody could reach it, lol.

I am thinking about how best to integrate the /cdlist command when the invalid load name is used. I feel like that could become a bit cumbersome for regular use. I have some ideas instead to have it search through the list and try to match the top 3-5 images in the list based on what was entered instead. I wont be able to do this until I have a bit more time though.

polpo, 2025-08-10:
Thanks to @RetroLoom the CD list paging is implemented in firmware v3.2.0: https://github.com/polpo/picogus/releases/tag/v3.2.0.
Regarding the issue with the CD list failing after a failed image load by name, sorry I didn't notice it in this thread, otherwise I would have also addressed that in the v3.2.0 release. Good idea to create an issue for things like that so I have a better chance of noticing them!
About fuzzy matching of loading images, I'm thinking that'd be a good application for a separate interactive CD image management program so pgusinit can remain relatively small and simple.

Closed 2025-08-10.

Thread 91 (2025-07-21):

Pocket386 and PicoGUS

Mikkel-1980, 2025-07-21:
Hello All,

I have a pocket 386 with ISA Extension board. When I insert a PicoGus (bought this new 2 weeks ago) the machine is not booting anymore because the CF card/harddrive is not recoginized anymore. When I unplug it it's booting again. I've checked the BIOS and DOS settings for IRQ conflicts but that's not the issue. I've also used the jumpers to set different configurations but it still is not booting up. Also without the jumpers it's not booting.

Are there any users with the Pocket 386 and the PicoGUS with similiar issues? I just bought the Pocket 386 with the ISA expension board and PicoGUS to play old school games with GUS or soundblaster support.

I am running the latest firmware.

Kind Regards,

Mikkel

britelite78, 2025-07-30:
I have similar problems with both the ISA expansion board with ISA PicoGus and the PicoGus Femto. In both cases the solution has been not to insert the Femto or the ISA expansion cable fully into the Pocket386's connector slot, but just almost.

Not really sure why this works though :)

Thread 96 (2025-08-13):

unable to change modes with pgusinit Firmware version 3.2.0 card locks up

Joey-boyy, 2025-08-13:
I'm trying the new firmware 3.2.0, and it works great, but when I change modes, I get error: card is not alive after rebooting to new firmware, which locks up the pico, and can only be resolved by powering down the card/system . I am able to change modes, with repeated attempts. I tried running my ISA bus speeds at 5mhz, 6, and 8, with the same results, on 2 different motherboards (a 486 board, and a socket 7 Pentium board), thanks.

polpo, 2025-08-13:
Clocks are configured differently on this firmware so it can be a closer divider of 44100Hz, but it seems that affects its ability to reboot after a mode change. I’ll see if I can find a workaround. Sorry this is happening!

polpo, 2025-08-30:
I have tried to reproduce this issue on 12 different PicoGUS boards, and while 11 don't have any problem, one had a somewhat similar issue – it wouldn't come back up after flashing the new firmware. Only difference is that it also won't start on powerup, but that may be enough for me to figure out a potential workaround for this issue.

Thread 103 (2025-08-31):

Support for USB mode wireless mice & trackballs

TPMatte, 2025-08-31:
Several wired USB mice I've tried work great in USB mode, but wireless devices like a Logitech Trackman, ERGO M575 or a cheap wireless MS mouse don't, apparently. Mouse driver loads without error, but mouse cursor and buttons just don't seem to work.

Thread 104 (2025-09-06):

pgusinit 3.2.0 command line issue /cdport

tollaksenDK, 2025-09-06:
pgusinit /cdport 270 is converted to 10e hex and saved as 10e hex so it is impossible to change port with 3.2.0
after changing pgusinit shows cdport as 10e and driver cd driver fails to load

polpo, 2025-09-26:
This is fixed in the latest firmware release v3.2.1: https://github.com/polpo/picogus/releases/tag/v3.2.1
(Actually, the fix is entirely within pgusinit, so you only need to just use the new pgusinit.exe without upgrading the firmware).

Closed 2025-09-26.

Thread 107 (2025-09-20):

Cannot change sound card mode with wavetable board installed FW 3.2.0

Sampson-Jackson, 2025-09-20:
I'm on the PicoGUS 2.0 and updated to the 3.2.0 FW with the matching pgusinit.exe 3.7.0. The CD emulation, and everything else I've tried, is working perfectly over the last few weeks. However, I am observing a hang (apparent soft-lock) in pgusinit.exe when attempting to change the sound card mode, if I have a wavetable board installed.

After "pgusinit /mode XYZ" it successfully detects the PicoGus and the FW/HW versions. It shows "Mode change requested." followed by "Rebooting to fw: XYZ...". It hangs here indefinitely with a blinking cursor, but Caps Lock does not toggle the LED indicator on the keyboard. Power cycle needed to recover; CTRL-ALT-DEL does not work.

It doesn't matter which sound card mode you start with, nor the target mode. After removing the wavetable board, there is no issue changing modes. After changing modes, it is possible to reinstall the wavetable card and it will function as normal.

I repro this issue with the McCake and the McFly wavetable boards.  However, if I do not plug in the external power for the McCake, I do not observe the issue.

I'm using a Pocket 386 with Windows95 aka DOS 7.10. I've tried real-mode and protected-mode, with and without various UMB/EMS/XMS settings. I tried with and without a CD image loaded with USB flash drive present and not present. Simply removing the wavetable card sorts it out.

Sampson-Jackson, 2025-09-28:
Hi -  I tried the new FW/SW and there was no change in behavior, unfortunately.

Based on your feedback, I also tried a couple more things without success - I tried dual 12v power supplies (one for Pocket386 and one for the ISA expander), and I removed my joystick ISA card so the PicoGUS was the only external device.   thx

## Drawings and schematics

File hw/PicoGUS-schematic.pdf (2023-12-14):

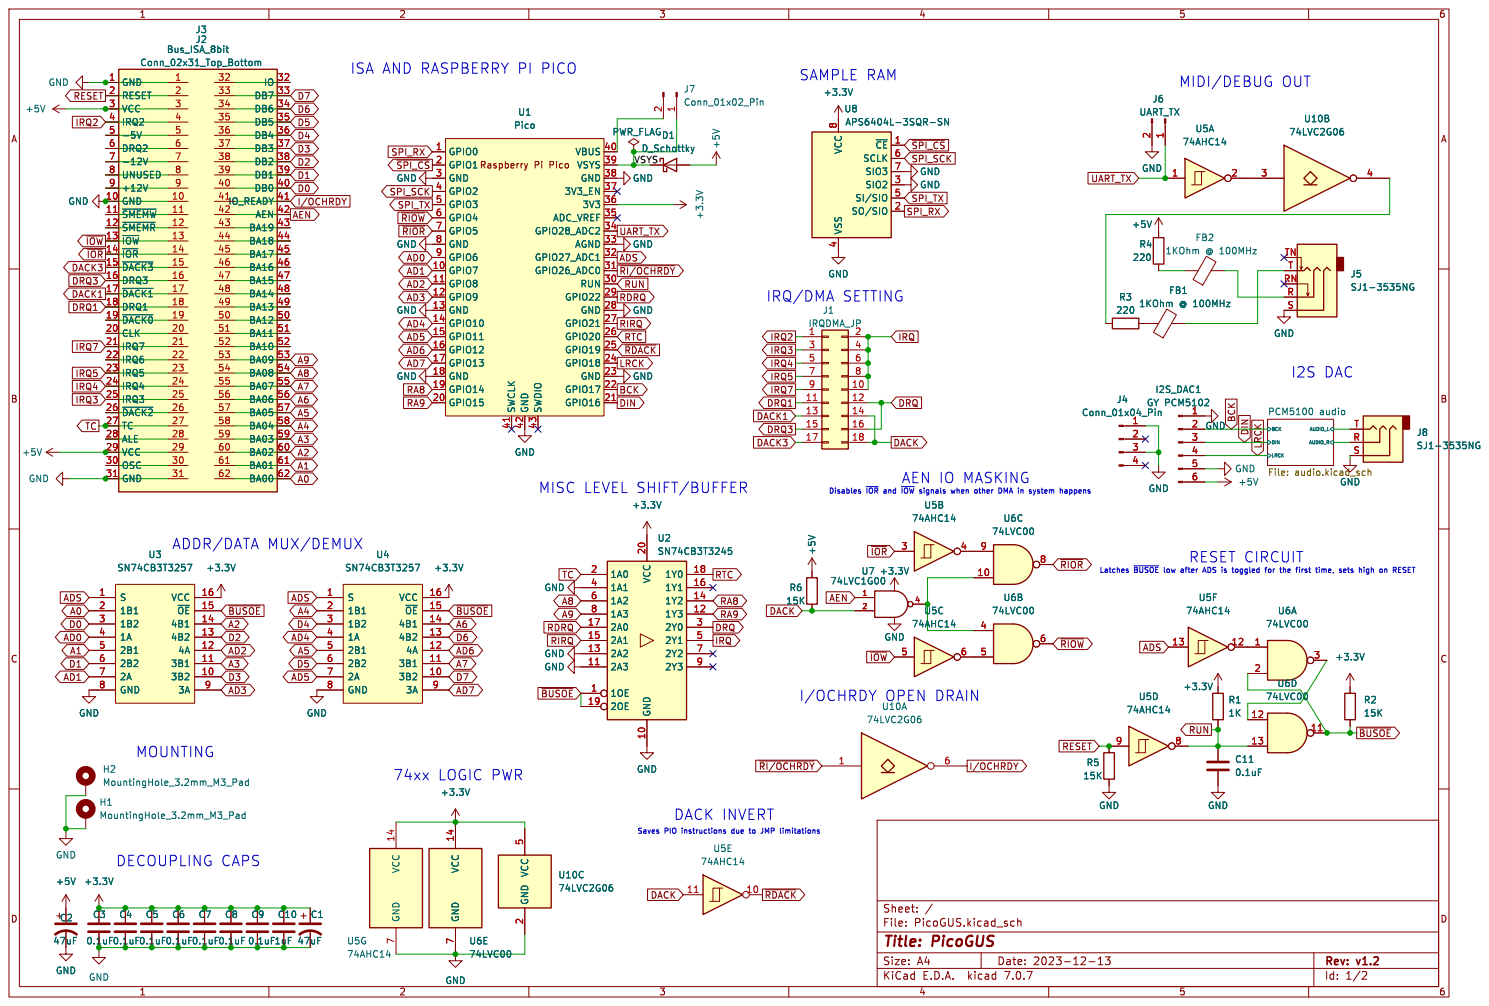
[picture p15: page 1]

J3 Bus_ISA_8bit GND 1 GND 10 ~{SMEMW} 11 ~{SMEMR} 12 ~{IOW} 13 ~{IOR} 14 ~{DACK3} 15 DRQ3 16 ~{DACK1} 17 DRQ1 18 ~{DACK0} 19 RESET 2 CLK 20
GND 1 GND 10 ~{SMEMW} 11 ~{SMEMR} 12 ~{IOW} 13 ~{IOR} 14 ~{DACK3} 15 DRQ3 16 ~{DACK1} 17 DRQ1 18 ~{DACK0} 19 RESET 2 CLK 20
~{RI/OCHRDY} D6 D7 D3 D4 D5 TC
IRQ3 25 ~{DACK2} 26 TC 27 ALE 28 VCC 29 VCC 3 OSC 30 GND 31

ISA AND RASPBERRY PI PICO

8 GND GND
~{CE}1 SO/SIO 2 SIO2 3 VSS

4 SI/SIO 5 SCLK 6 SIO3 7 VCC

GND GND

ADDR/DATA MUX/DEMUX

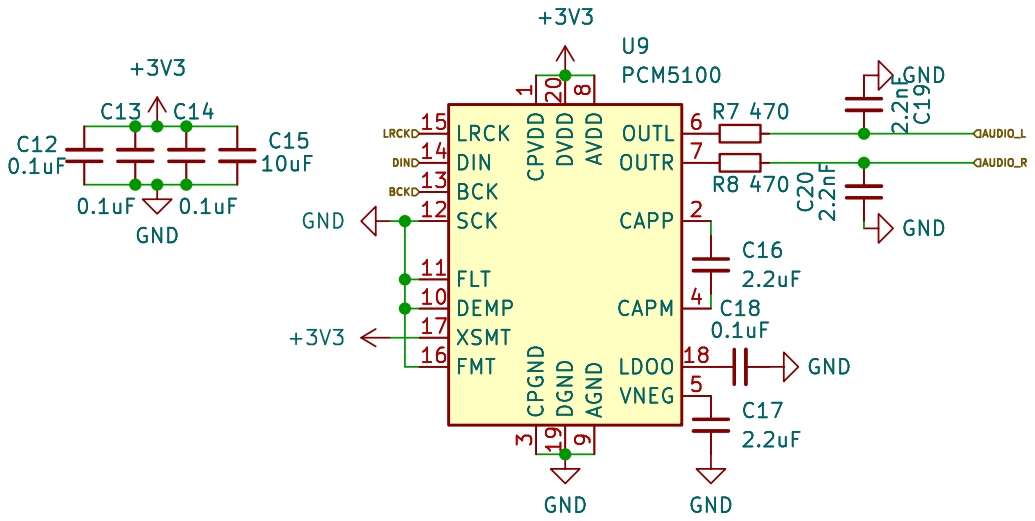
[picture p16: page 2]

1 DEMP 10 FLT 11 SCK 12 BCK 13 DIN 14

3 CAPM 4 VNEG 5 OUTL 6 OUTR 7 AVDD

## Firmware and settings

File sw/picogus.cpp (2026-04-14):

/*
 *  Copyright (C) 2022-2024  Ian Scott
 *
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
 *  You should have received a copy of the GNU General Public License along
 *  with this program; if not, write to the Free Software Foundation, Inc.,
 *  51 Franklin Street, Fifth Floor, Boston, MA 02110-1301, USA.
 */

#include <string.h>
#include "include/pg_debug.h"
#include "pico/stdlib.h"
#include "pico/multicore.h"
#include "hardware/adc.h"
#include "hardware/pio.h"
#include "hardware/irq.h"
#include "hardware/regs/vreg_and_chip_reset.h"
#include "hardware/vreg.h"
#include "hardware/clocks.h"

#include "system/overclock.h"
#include "system/pico_reflash.h"
#include "system/flash_settings.h"

// For multifw
#include "hardware/watchdog.h"
#include "hardware/structs/watchdog.h"

#include "../common/picogus.h"

board_type_t BOARD_TYPE;

#ifdef PSRAM
#include "psram_spi.h"
psram_spi_inst_t psram_spi;
psram_spi_inst_t* async_spi_inst;
#endif
#include "isa_io.pio.h"

#ifdef ASYNC_UART
#include "stdio_async_uart.h"
#endif 
// UART_TX_PIN is defined in isa_io.pio.h
#define UART_RX_PIN (-1)
#define UART_ID     uart0
#define BAUD_RATE   230400

uint LED_PIN;

#include "M62429/M62429.h"
M62429* m62429;


#ifdef SOUND_SB
#ifdef SOUND_WSS
#include "ad1848/ad1848.h"
static constexpr uint16_t wss_port_test = 0x13;
static uint8_t wss_config = 0b00001010; // DMA 1 and IRQ 7
#else
#include "sbdsp/sbdsp.h"
#endif
static uint16_t sb_port_test;
#endif
#ifdef SOUND_OPL
#include "opl.h"
void play_adlib(void);
#if OPL_CMD_BUFFER
#include "include/cmd_buffers.h"
cms_buffer_t opl_cmd_buffer = { {0}, 0, 0 };
#else
extern "C" void OPL_Pico_WriteRegister(unsigned int reg_num, unsigned int value);
static uint16_t opl_addr;
#endif // OPL_CMD_BUFFER
#if AUDIO_CALLBACK_CORE0
extern void audio_sample_handler(void);
#endif // AUDIO_CALLBACK_CORE0
#endif // SOUND_OPL

#ifdef CDROM
static uint16_t cdrom_port_test;
extern "C" void MKE_WRITE(uint16_t address, uint8_t value);
extern "C" uint8_t MKE_READ(uint16_t address);
extern "C" void mke_init();

#include "cdrom/cdrom.h"
#include "cdrom/cdrom_image_manager.h"
cdrom_t cdrom;

static uint32_t cur_read_idx;
#endif

#ifdef SOUND_GUS
#include "gus/gus-x.cpp"
#include "isa/isa_dma.h"
dma_inst_t dma_config;
static uint16_t gus_port_test;
void play_gus(void);
#endif


#ifdef SOUND_MPU
#include "mpu401/export.h"
#ifdef MPU_ONLY
void play_mpu(void);
#endif
#endif

#if SOUND_TANDY || SOUND_CMS
#include "include/cmd_buffers.h"
#include "square/square.h"
void play_psg(void);
#endif
#if SOUND_TANDY
tandy_buffer_t tandy_buffer = { {0}, 0, 0 };
#endif
#if SOUND_CMS
static uint8_t cms_detect = 0xFF;
cms_buffer_t cms_buffer = { {0}, 0, 0 };
#endif


#ifdef NE2000
extern "C" {
#include "ne2000/ne2000.h"
}
void play_ne2000(void);
#endif


#ifdef USB_JOYSTICK
#include "usb_hid/joy.h"
extern "C" joystate_struct_t joystate_struct;
uint8_t joystate_bin;
#include "hardware/pwm.h"
#endif
#ifdef USB_MOUSE
#include "mouse/8250uart.h"
#include "mouse/sermouse.h"
#endif
#ifdef USB_ONLY
void play_usb(void);
#endif

#if SOUND_GUS || SOUND_SB || SOUND_OPL || CDROM || SOUND_TANDY || SOUND_CMS
#include "audio/volctrl.h"
#endif


// PicoGUS control and data ports
static bool control_active = false;
static uint8_t sel_reg = 0;
static uint32_t cur_read = 0;
static uint32_t cur_write = 0;
static bool queueSaveSettings = false;
static bool queueReboot = false;

Settings settings;
void processSettings(void);

static void wtvol_from_mixer(uint8_t volume) {
    settings.Global.waveTableVolume = volume;
    if (BOARD_TYPE == PICOGUS_2) {
        m62429->setVolume(M62429_BOTH, volume);
    }
}

#define IOW_PIO_SM 0
#define IOR_PIO_SM 1

const char* firmware_string = PICO_PROGRAM_NAME " v" PICO_PROGRAM_VERSION_STRING;

static uint8_t basePort_low;
static uint8_t mouseSensitivity_low;
static uint8_t picogus_dataLatch_low;

__force_inline void select_picogus(uint8_t value) {
    // printf("select picogus %x\n", value);
    sel_reg = value;
    switch (sel_reg) {
    case CMD_MAGIC: // Magic string
    case CMD_PROTOCOL: // Protocol version
        break;
    case CMD_FWSTRING: // Firmware string
        cur_read = 0;
        break;
    case CMD_BOOTMODE: // Mode (GUS, OPL, MPU, etc...)
        break;
    case CMD_GUSPORT: // GUS Base port
    case CMD_OPLPORT: // Adlib Base port
    case CMD_SBPORT: // SB Base port
    case CMD_MPUPORT: // MPU Base port
    case CMD_TANDYPORT: // Tandy Base port
    case CMD_CMSPORT: // CMS Base port
        basePort_low = 0;
        break;
    case CMD_JOYEN: // enable joystick
        break;
    case CMD_GUSBUF: // Audio buffer size
    case CMD_GUSDMA: // DMA interval
    case CMD_GUS44K: // Force 44k
        break;
    case CMD_WTVOL: // Wavetable mixer volume
        break;
    case CMD_MPUDELAY: // MPU sysex delay
    case CMD_MPUFAKE: // MPU fake all notes off
        break;
    case CMD_OPLWAIT: // Adlib speed sensitive fix
        break;
    case CMD_MOUSEPORT:
        basePort_low = 0;
        break;
    case CMD_MOUSEPROTO:
    case CMD_MOUSERATE:
    case CMD_MOUSESEN:
        break;
    case CMD_NE2KPORT:
        basePort_low = 0;
        break;
    case CMD_WIFISSID:
        memset(settings.WiFi.ssid, 0, sizeof(settings.WiFi.ssid));
        cur_write = 0;
        break;
    case CMD_WIFIPASS:
        memset(settings.WiFi.password, 0, sizeof(settings.WiFi.password));
        cur_write = 0;
        break;
    case CMD_WIFIAPPLY:
    case CMD_WIFISTAT:
        break;
    case CMD_CDPORT: // CMS Base port
        basePort_low = 0;
        break;
    case CMD_CDLIST:
#ifdef CDROM
        if (cdrom.image_status == CD_STATUS_IDLE || cdrom.image_status == CD_STATUS_ERROR) {
            cdrom.image_status = CD_STATUS_BUSY;
            cdrom.image_command = CD_COMMAND_IMAGE_LIST;
            // puts("cdimages start");
        }
        // puts("cdimages read");
        cur_read = 0;
        cur_read_idx = 0;
#endif
        break;
    case CMD_SBTYPE:
    case CMD_SBIRQ:
    case CMD_SBDMA:
    case CMD_SBOPTS:
    case CMD_CDSTATUS:
    case CMD_CDLOAD:
    case CMD_CDAUTOADV:
    case CMD_MAINVOL:
    case CMD_OPLVOL:
    case CMD_SBVOL:
    case CMD_CDVOL:
    case CMD_GUSVOL:
    case CMD_PSGVOL:
        break;
    case CMD_CDNAME:
        cur_write = 0;
    case CMD_CDERROR:
        cur_read = 0;
        break;
    case CMD_SAVE: // Select save settings register
    case CMD_REBOOT: // Select reboot register
    case CMD_DEFAULTS: // Select reset to defaults register
        break;
    case CMD_HWTYPE: // Hardware version
        break;
    case CMD_FLASH: // Firmware write mode
        pico_firmware_start();
        break;
    default:
        control_active = false;
        break;
    }
}

__force_inline void write_picogus_low(uint8_t value) {
    switch (sel_reg) {
    case CMD_GUSPORT: // GUS Base port
    case CMD_OPLPORT: // Adlib Base port
    case CMD_SBPORT: // SB Base port
    case CMD_MPUPORT: // MPU Base port
    case CMD_TANDYPORT: // Tandy Base port
    case CMD_CMSPORT: // CMS Base port
    case CMD_MOUSEPORT:  // USB Mouse port (0 - disabled)
    case CMD_CDPORT:  // USB Mouse port (0 - disabled)
        basePort_low = value;
        break;
    case CMD_MOUSESEN:  // USB Mouse Sensitivity (8.8 fixedpoint)
        mouseSensitivity_low = value;
        break;
    }
}

__force_inline void write_picogus_high(uint8_t value) {
    switch (sel_reg) {
    case CMD_GUSPORT: // GUS Base port
        settings.GUS.basePort = (value || basePort_low) ? ((value << 8) | basePort_low) : 0xFFFF;
#ifdef SOUND_GUS
        gus_port_test = settings.GUS.basePort >> 4 | 0x10;
#endif
        break;
    case CMD_OPLPORT: // Adlib Base port
        settings.SB.oplBasePort = (value || basePort_low) ? ((value << 8) | basePort_low) : 0xFFFF;
        break;
    case CMD_SBPORT: // SB Base port
        settings.SB.basePort = (value || basePort_low) ? ((value << 8) | basePort_low) : 0xFFFF;
#ifdef SOUND_SB
        sb_port_test = settings.SB.basePort >> 4;
#endif
        break;
    case CMD_MPUPORT: // MPU Base port
        settings.MPU.basePort = (value || basePort_low) ? ((value << 8) | basePort_low) : 0xFFFF;
        break;
    case CMD_TANDYPORT: // Tandy Base port
        settings.Tandy.basePort = (value || basePort_low) ? ((value << 8) | basePort_low) : 0xFFFF;
        break;
    case CMD_CMSPORT: // CMS Base port
        settings.CMS.basePort = (value || basePort_low) ? ((value << 8) | basePort_low) : 0xFFFF;
        break;
    case CMD_JOYEN: // enable joystick
        settings.Joy.basePort = value ? 0x201u : 0xffff;
        break;
    case CMD_GUSBUF: // GUS audio buffer size
        // Value is sent by pgusinit as the size - 1, so we need to add 1 back to it
        settings.GUS.audioBuffer = value + 1;
#ifdef SOUND_GUS
        GUS_SetAudioBuffer(settings.GUS.audioBuffer);
#endif
        break;
    case CMD_GUSDMA: // GUS DMA interval
        settings.GUS.dmaInterval = value;
#ifdef SOUND_GUS
        GUS_SetDMAInterval(settings.GUS.dmaInterval);
#endif
        break;
    case CMD_GUS44K: // Force 44k output
        settings.GUS.force44k = value;
#ifdef SOUND_GUS
        GUS_SetFixed44k(settings.GUS.force44k);
#endif
        break;
    case CMD_WTVOL: // Wavetable mixer volume
        wtvol_from_mixer(value);
        break;
    case CMD_MPUDELAY: // MPU SYSEX delay
        settings.MPU.delaySysex = value;
#ifdef SOUND_MPU
        MPU401_Init(settings.MPU.delaySysex, settings.MPU.fakeAllNotesOff);
#endif
        break;
    case CMD_MPUFAKE: // MPU fake all notes off
        settings.MPU.fakeAllNotesOff = value;
#ifdef SOUND_MPU
        MPU401_Init(settings.MPU.delaySysex, settings.MPU.fakeAllNotesOff);
#endif
        break;
    case CMD_OPLWAIT: // Adlib speed sensitive fix
        settings.SB.oplSpeedSensitive = value;
        break;
        
    case CMD_SBTYPE:
        settings.SB16.sbType = value;
#ifdef SOUND_SB
        sbdsp_set_type(value);
#endif
        break;
    case CMD_SBIRQ:
        settings.SB16.irq = value;
#ifdef SOUND_SB
        sbdsp_set_irq(value);
#endif
        break;
    case CMD_SBDMA:
        settings.SB16.dma = value;
#ifdef SOUND_SB
        sbdsp_set_dma(value);
#endif
        break;
    case CMD_SBOPTS:
        settings.SB16.options = value;
#ifdef SOUND_SB
        sbdsp_set_options(value);
#endif
        break;
    case CMD_MOUSEPORT:  // USB Mouse port (0 - disabled)
        settings.Mouse.basePort = (value || basePort_low) ? ((value << 8) | basePort_low) : 0xFFFF;
        break;
    case CMD_MOUSEPROTO:  // USB Mouse protocol
        settings.Mouse.protocol = value;
#ifdef USB_MOUSE
        sermouse_set_protocol(settings.Mouse.protocol);
#endif
        break;
    case CMD_MOUSERATE:  // USB Mouse Report Rate
        settings.Mouse.reportRate = value;
#ifdef USB_MOUSE
        sermouse_set_report_rate_hz(settings.Mouse.reportRate);
#endif
        break;
    case CMD_MOUSESEN:  // USB Mouse Sensitivity (8.8 fixedpoint)
        settings.Mouse.sensitivity = (value << 8) | (mouseSensitivity_low & 0xFF);
#ifdef USB_MOUSE
        sermouse_set_sensitivity(settings.Mouse.sensitivity);
#endif
        break;
    case CMD_NE2KPORT: // NE2000 Base port
        settings.NE2K.basePort = (value || basePort_low) ? ((value << 8) | basePort_low) : 0xFFFF;
        break;
    case CMD_WIFISSID:
        settings.WiFi.ssid[cur_write++] = value;
        break;
    case CMD_WIFIPASS:
        settings.WiFi.password[cur_write++] = value;
        /* printf("%s\n", settings.WiFi.password); */
        break;
    case CMD_WIFIAPPLY:
        DBG_PRINTF("Applying wifi settings: %s %s\n", settings.WiFi.ssid, settings.WiFi.password);
#ifdef PICOW
        PG_Wifi_Connect(settings.WiFi.ssid, settings.WiFi.password);
#endif
        break;
    case CMD_WIFISTAT:
#ifdef PICOW
        multicore_fifo_push_blocking(FIFO_WIFI_STATUS);
#endif
        break;
    case CMD_CDPORT: // CD Base port
        settings.CD.basePort = (value || basePort_low) ? ((value << 8) | basePort_low) : 0xFFFF;
#ifdef CDROM
        cdrom_port_test = settings.CD.basePort >> 4;
#endif
        break;
#ifdef CDROM
    case CMD_CDLOAD: // Load CD image
        cdrom.image_data = value;
        cdrom.image_status = CD_STATUS_BUSY;
        cdrom.image_command = CD_COMMAND_IMAGE_LOAD_INDEX;
        break;
    case CMD_CDNAME:
        if (!cur_write) {
            memset(cdrom.image_path, 0, sizeof(cdrom.image_path));
        }
        cdrom.image_path[cur_write++] = value;
        if (!value) {
            cur_write = 0;
            cdrom.image_status = CD_STATUS_BUSY;
            cdrom.image_command = CD_COMMAND_IMAGE_LOAD;
        }
        break;
#endif
    case CMD_CDAUTOADV: // enable auto advance of CD image on USB reinsert
        settings.CD.autoAdvance = value;
#ifdef CDROM
        cdman_set_autoadvance(settings.CD.autoAdvance);
#endif
        break;
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
int main()
{
    busy_wait_ms(250);
    overclock_370mhz();
#ifdef ASYNC_UART
    stdio_async_uart_init_full(UART_ID, BAUD_RATE, UART_TX_PIN, UART_RX_PIN);
#else
    stdio_init_all();
#endif
    DBG_PUTS(firmware_string);
    io_rw_32 *reset_reason = (io_rw_32 *) (VREG_AND_CHIP_RESET_BASE + VREG_AND_CHIP_RESET_CHIP_RESET_OFFSET);
    if (*reset_reason & VREG_AND_CHIP_RESET_CHIP_RESET_HAD_POR_BITS) {
        DBG_PUTS("I was reset due to power on reset or brownout detection.");
    } else if (*reset_reason & VREG_AND_CHIP_RESET_CHIP_RESET_HAD_RUN_BITS) {
        DBG_PUTS("I was reset due to the RUN pin (either manually or due to ISA RESET signal)");
    } else if(*reset_reason & VREG_AND_CHIP_RESET_CHIP_RESET_HAD_PSM_RESTART_BITS) {
        DBG_PUTS("I was reset due the debug port");
    }

    // Load settings from flash
    loadSettings(&settings, true /* migrate */);
    hw_clear_bits(&xip_ctrl_hw->ctrl, XIP_CTRL_EN_BITS);

    // Determine board type. GPIO 29 is grounded on PicoGUS v2.0, and on a Pico, it's VSYS/3 (~1.666V)
    // GPIO 25 must be high to read GPIO 29 on the Pico W
    gpio_init(25);
    gpio_set_dir(25, GPIO_OUT);
    gpio_put(25, 1);
    adc_init();
    adc_gpio_init(29);
    // Select ADC input 3 (GPIO29)
    adc_select_input(3);
    // Read several times to let ADC stabilize
    adc_read(); adc_read(); adc_read(); adc_read(); adc_read();
    uint16_t result = adc_read();
    DBG_PRINTF("ADC value: 0x%03x... ", result);
    gpio_put(25, 0);
    gpio_deinit(25);

    if (result > 0x100) {
        DBG_PUTS("Running on Pico-based board (PicoGUS v1.1+, PicoGUS Femto)");
        // On Pico-based board (PicoGUS v1.1+, PicoGUS Femto)
#ifndef PICOW        
        LED_PIN = 1 << PICO_DEFAULT_LED_PIN;
        gpio_init(PICO_DEFAULT_LED_PIN);
        gpio_set_dir(PICO_DEFAULT_LED_PIN, GPIO_OUT);
#endif
        BOARD_TYPE = PICO_BASED;
    } else {
        // On chipdown board (PicoGUS v2.0)
        DBG_PUTS("Running on PicoGUS v2.0");
        LED_PIN = 1 << 23;
        gpio_init(23);
        gpio_set_dir(23, GPIO_OUT);
        BOARD_TYPE = PICOGUS_2;
    }
    gpio_set_mask(LED_PIN);

    if (BOARD_TYPE == PICOGUS_2) {
        // Create new interface to M62429 digital volume control
        m62429 = new M62429();
        // Data pin = GPIO24, data pin = GPIO25
#ifdef M62429_PIO
        m62429->begin(24, 25, pio1, -1);
#else
        m62429->begin(24, 25);
        // Initial volume is set in processSettings()
#endif // M62429_PIO
    }

    gpio_init(IRQ_PIN);
    gpio_set_dir(IRQ_PIN, GPIO_OUT);
    gpio_set_drive_strength(IRQ_PIN, GPIO_DRIVE_STRENGTH_12MA);

#ifdef SOUND_MPU
    DBG_PUTS("Initing MIDI UART...");
    uart_init(UART_ID, 31250);
    uart_set_translate_crlf(UART_ID, false);
    uart_set_format(UART_ID, 8, 1, UART_PARITY_NONE);
    if (BOARD_TYPE == PICO_BASED) {
        // Original hardware drives MIDI directly from RP2040. Newer HW uses an open drain inverter
        // PicoGUS v1.2 also uses an open drain but we can't detect that particular board
        gpio_set_drive_strength(UART_TX_PIN, GPIO_DRIVE_STRENGTH_12MA);
    }
    gpio_set_function(UART_TX_PIN, GPIO_FUNC_UART);
#endif // SOUND_MPU

#ifdef PSRAM_CORE0
#ifdef PSRAM
    DBG_PUTS("Initing PSRAM...");
    // Try different PSRAM strategies
    if (BOARD_TYPE == PICOGUS_2) {
        psram_spi = psram_spi_init_clkdiv(pio1, -1, psram_clkdiv /* clkdiv */, false /* fudge */);
#if TEST_PSRAM
        // Only bother to test every 97th address
        if (test_psram(&psram_spi, 97) == 1) {
            DBG_PRINTF("Default PSRAM strategy of no fudge not working, switching to fudge\n");
            psram_spi_uninit(psram_spi, false /* fudge */);
            psram_spi = psram_spi_init_clkdiv(pio1, -1, psram_clkdiv /* clkdiv */, true /* fudge */);
            if (test_psram(&psram_spi, 97) == 1) { 
                ERR_PUTS("Error: No PSRAM strategies found to work!");
                err_blink();
            }
        }
#endif // TEST_PSRAM
    } else {
        psram_spi = psram_spi_init_clkdiv(pio1, -1, psram_clkdiv /* clkdiv */, true /* fudge */);
#if TEST_PSRAM
        if (test_psram(&psram_spi, 97) == 1) {
            psram_spi_uninit(psram_spi, true /* fudge */);
            psram_spi = psram_spi_init_clkdiv(pio1, -1, psram_clkdiv /* clkdiv */, false /* fudge */);
            if (test_psram(&psram_spi, 97) == 1) { 
                ERR_PUTS("Error: No PSRAM strategies found to work!");
                err_blink();
            }
        }
#endif // TEST_PSRAM
    }
#endif // PSRAM
#endif // PSRAM_CORE0


#ifdef SOUND_SB
#ifdef SOUND_WSS
    DBG_PUTS("Initializing WSS AD1848");
#else
    DBG_PUTS("Initializing SoundBlaster DSP");
#endif
    // init actually happens on core 1 in play_adlib()
#endif // SOUND_SB
#ifdef SOUND_OPL
    DBG_PUTS("Creating OPL");
    OPL_Pico_Init(0);
    multicore_launch_core1(&play_adlib);
#endif

#ifdef CDROM
    cdrom_global_init();
    mke_init();
#endif

#ifdef SOUND_GUS
    DBG_PUTS("Creating GUS");
    GUS_OnReset();
    multicore_launch_core1(&play_gus);
#endif // SOUND_GUS

#ifdef SOUND_MPU
#ifdef MPU_ONLY
    multicore_launch_core1(&play_mpu);
#endif // MPU_ONLY
#endif // SOUND_MPU

#if (SOUND_TANDY || SOUND_CMS)
    DBG_PUTS("Creating psgsound");
    multicore_launch_core1(&play_psg);
#endif // (SOUND_TANDY || SOUND_CMS)

#ifdef NE2000
extern void PIC_ActivateIRQ(void);
extern void PIC_DeActivateIRQ(void);

    DBG_PUTS("Creating NE2000");
    multicore_launch_core1(&play_ne2000);
#endif

#ifdef USB_JOYSTICK
    // Init joystick as centered with no buttons pressed
    joystate_struct = {127, 127, 127, 127, 0xf};
    DBG_PUTS("Config joystick PWM");
    pwm_config pwm_c = pwm_get_default_config();
    // TODO better calibrate this
    pwm_config_set_clkdiv(&pwm_c, pwm_clkdiv);
    // Start the PWM off constantly looping at 0
    pwm_config_set_wrap(&pwm_c, 0);
    pwm_init(0, &pwm_c, true);
    pwm_init(1, &pwm_c, true);
    pwm_init(2, &pwm_c, true);
    pwm_init(3, &pwm_c, true);
#endif // USB_JOYSTICK
#ifdef USB_MOUSE
    DBG_PUTS("Config USB Mouse emulation");
    uartemu_init(0);
    sermouse_init(settings.Mouse.protocol, settings.Mouse.reportRate, settings.Mouse.sensitivity);
    sermouse_attach_uart();
#endif // USB_MOUSE
#ifdef USB_ONLY
    multicore_launch_core1(&play_usb);
#endif // USBONLY

    for(int i=AD0_PIN; i<(AD0_PIN + 10); ++i) {
        gpio_disable_pulls(i);
    }
    gpio_disable_pulls(IOW_PIN);
    gpio_disable_pulls(IOR_PIN);
    gpio_pull_down(IOCHRDY_PIN);
    gpio_set_dir(IOCHRDY_PIN, GPIO_OUT);

    DBG_PUTS("Enabling bus transceivers...");
    // waggle ADS to set BUSOE latch
    gpio_init(ADS_PIN);
    gpio_set_dir(ADS_PIN, GPIO_OUT);
    gpio_put(ADS_PIN, 1);
    busy_wait_ms(10);
    gpio_put(ADS_PIN, 0);

    DBG_PUTS("Starting ISA bus PIO...");
    // gpio_set_drive_strength(ADS_PIN, GPIO_DRIVE_STRENGTH_12MA);
    gpio_set_slew_rate(ADS_PIN, GPIO_SLEW_RATE_FAST);

    uint iow_offset = pio_add_program(pio0, &iow_program);
    pio_sm_claim(pio0, IOW_PIO_SM);
    DBG_PRINTF("iow sm: %u\n", IOW_PIO_SM);

    uint ior_offset = pio_add_program(pio0, &ior_program);
    pio_sm_claim(pio0, IOR_PIO_SM);
    DBG_PRINTF("ior sm: %u\n", IOR_PIO_SM);

    iow_program_init(pio0, IOW_PIO_SM, iow_offset, iow_clkdiv);
    ior_program_init(pio0, IOR_PIO_SM, ior_offset);

#ifdef USE_IRQ
    DBG_PUTS("Enabling IRQ on ISA IOR/IOW events");
    irq_set_enabled(PIO0_IRQ_1, false);
    pio_set_irq1_source_enabled(pio0, pio_get_rx_fifo_not_empty_interrupt_source(IOW_PIO_SM), true);
    pio_set_irq1_source_enabled(pio0, pio_get_rx_fifo_not_empty_interrupt_source(IOR_PIO_SM), true);
    irq_set_priority(PIO0_IRQ_1, PICO_HIGHEST_IRQ_PRIORITY);
    irq_set_exclusive_handler(PIO0_IRQ_1, io_isr);
    irq_set_enabled(PIO0_IRQ_1, true);
#endif

    gpio_xor_mask(LED_PIN);

#if AUDIO_CALLBACK_CORE0
    pwm_c = pwm_get_default_config();
    pwm_config_set_wrap(&pwm_c, clocks_per_sample_minus_one);
    pwm_init(pwm_slice_num, &pwm_c, false);
    pwm_set_irq_enabled(pwm_slice_num, true);
    irq_set_exclusive_handler(PWM_IRQ_WRAP, audio_sample_handler);
    irq_set_priority(PWM_IRQ_WRAP, PICO_LOWEST_IRQ_PRIORITY);
    irq_set_enabled(PWM_IRQ_WRAP, true);
    pwm_set_enabled(pwm_slice_num, true);
#endif

    processSettings();

    for (;;) {
#ifndef USE_IRQ
        if (iow_has_data()) {
            handle_iow();
        }

        if (ior_has_data()) {
            handle_ior();
        }
#endif
#ifdef POLLING_DMA
        process_dma();
#endif
    }
}

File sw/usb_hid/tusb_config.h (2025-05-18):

/* 
 * The MIT License (MIT)
 *
 * Copyright (c) 2019 Ha Thach (tinyusb.org)
 *
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
 */

#ifndef _TUSB_CONFIG_H_
#define _TUSB_CONFIG_H_

#ifdef __cplusplus
 extern "C" {
#endif

//--------------------------------------------------------------------+
// Board Specific Configuration
//--------------------------------------------------------------------+
#define CFG_TUSB_MCU OPT_MCU_RP2040

#define CFG_TUH_XINPUT 1

#if CFG_TUSB_MCU == OPT_MCU_RP2040
// change to 1 if using pico-pio-usb as host controller for raspberry rp2040
#define CFG_TUH_RPI_PIO_USB   0
#define BOARD_TUH_RHPORT      CFG_TUH_RPI_PIO_USB
#endif

// RHPort number used for host can be defined by board.mk, default to port 0
#ifndef BOARD_TUH_RHPORT
#define BOARD_TUH_RHPORT      0
#endif

// RHPort max operational speed can defined by board.mk
#ifndef BOARD_TUH_MAX_SPEED
#define BOARD_TUH_MAX_SPEED   OPT_MODE_DEFAULT_SPEED
#endif

//--------------------------------------------------------------------
// COMMON CONFIGURATION
//--------------------------------------------------------------------

// defined by compiler flags for flexibility
#ifndef CFG_TUSB_MCU
#error CFG_TUSB_MCU must be defined
#endif

#ifndef CFG_TUSB_OS
#define CFG_TUSB_OS           OPT_OS_NONE
#endif

#ifndef CFG_TUSB_DEBUG
#define CFG_TUSB_DEBUG        0
#endif

// Enable Host stack
#define CFG_TUH_ENABLED       1

// Default is max speed that hardware controller could support with on-chip PHY
#define CFG_TUH_MAX_SPEED     BOARD_TUH_MAX_SPEED

/* USB DMA on some MCUs can only access a specific SRAM region with restriction on alignment.
 * Tinyusb use follows macros to declare transferring memory so that they can be put
 * into those specific section.
 * e.g
 * - CFG_TUSB_MEM SECTION : __attribute__ (( section(".usb_ram") ))
 * - CFG_TUSB_MEM_ALIGN   : __attribute__ ((aligned(4)))
 */
#ifndef CFG_TUSB_MEM_SECTION
#define CFG_TUSB_MEM_SECTION
#endif

#ifndef CFG_TUSB_MEM_ALIGN
#define CFG_TUSB_MEM_ALIGN          __attribute__ ((aligned(4)))
#endif

//--------------------------------------------------------------------
// CONFIGURATION
//--------------------------------------------------------------------

// Size of buffer to hold descriptors and other data used for enumeration
#define CFG_TUH_ENUMERATION_BUFSIZE 1024

#define CFG_TUH_HUB                 1 // number of supported hubs
#define CFG_TUH_CDC                 0
#define CFG_TUH_HID                 4 // typical keyboard + mouse device can have 3-4 HID interfaces
#define CFG_TUH_MSC                 1
#define CFG_TUH_VENDOR              0

// max device support (excluding hub device)
#define CFG_TUH_DEVICE_MAX          (CFG_TUH_HUB ? 4 : 1) // hub typically has 4 ports

//------------- HID -------------//
#define CFG_TUH_HID_EPIN_BUFSIZE    64
#define CFG_TUH_HID_EPOUT_BUFSIZE   64

//------------- CDC -------------//

// Set Line Control state on enumeration/mounted:
// DTR ( bit 0), RTS (bit 1)
#define CFG_TUH_CDC_LINE_CONTROL_ON_ENUM    0x03

// Set Line Coding on enumeration/mounted, value for cdc_line_coding_t
// bit rate = 115200, 1 stop bit, no parity, 8 bit data width
#define CFG_TUH_CDC_LINE_CODING_ON_ENUM   { 115200, CDC_LINE_CONDING_STOP_BITS_1, CDC_LINE_CODING_PARITY_NONE, 8 }


#ifdef __cplusplus
 }
#endif

#endif /* _TUSB_CONFIG_H_ */

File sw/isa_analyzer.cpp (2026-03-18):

/*
 *  Copyright (C) 2025 Ian Scott
 *
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
 *  You should have received a copy of the GNU General Public License along
 *  with this program; if not, write to the Free Software Foundation, Inc.,
 *  51 Franklin Street, Fifth Floor, Boston, MA 02110-1301, USA.
 */

#include <cstdio>
#include <cstring>
#include <cstdlib>
#include <cstdint>
#include <pico/stdlib.h>
#include <hardware/gpio.h>
#include <hardware/pio.h>
#include <hardware/structs/ioqspi.h>
#include <hardware/structs/qmi.h>
#include <hardware/structs/xip.h>
#include <hardware/sync.h>
#include <hardware/structs/pads_bank0.h>

#include "isa_analyzer.pio.h"

// PSRAM configuration (Pimoroni Pico Plus 2 onboard PSRAM)
#define PSRAM_CS_PIN         47
#define PSRAM_BASE_UNCACHED  0x15000000
#define PSRAM_SIZE           (8 * 1024 * 1024)

// PIO state machine assignments (both on pio0)
#define IOW_SM 0
#define IOR_SM 1

// RLE compression constants
#define RLE_MAGIC       0xFF000000
#define RLE_COUNT_MASK  0x00FFFFFF
#define RLE_MAX_COUNT   0x00FFFFFF  // 16,777,215

// Binary output markers
constexpr uint32_t BINARY_MARKER_MAGIC = 0x1DE1DE1D;
constexpr uint32_t BINARY_MARKER_START = 0x42494E53;  // "BINS"
constexpr uint32_t BINARY_MARKER_END   = 0x42494E45;  // "BINE"

static uint32_t *data_buffer;
static size_t buffer_size = 0;           // Total buffer capacity in 32-bit words
volatile static size_t write_idx = 0;    // Next write position (monotonically increasing)
volatile static bool buffer_wrapped = false;

// RLE state
static uint32_t last_event = 0;
static uint32_t repeat_count = 0;

// Port filter bitmap: 1024 bits = 128 bytes, one bit per 10-bit address
static uint8_t port_bitmap[128];

// ---- FIFO polling ----

constexpr uint32_t iow_rxempty = 1u << (PIO_FSTAT_RXEMPTY_LSB + IOW_SM);
__force_inline bool iow_has_data() {
    return !(pio0->fstat & iow_rxempty);
}

constexpr uint32_t ior_rxempty = 1u << (PIO_FSTAT_RXEMPTY_LSB + IOR_SM);
__force_inline bool ior_has_data() {
    return !(pio0->fstat & ior_rxempty);
}

// ---- Ring buffer & RLE (from ide_analyzer.cpp) ----

__force_inline void ring_write(uint32_t value) {
    data_buffer[write_idx % buffer_size] = value;
    write_idx++;
    if (write_idx >= buffer_size && !buffer_wrapped) {
        buffer_wrapped = true;
    }
}

__force_inline void flush_rle(void) {
    if (repeat_count == 0) return;

    // Write value first (value-first encoding for ring buffer safety)
    ring_write(last_event);
    // Then write trailer with count if repeated
    if (repeat_count > 1) {
        ring_write(RLE_MAGIC | (repeat_count - 1));
    }
    repeat_count = 0;
}

__force_inline void record_event(uint32_t event) {
    if (repeat_count == 0) {
        last_event = event;
        repeat_count = 1;
    } else if (event == last_event && repeat_count < RLE_MAX_COUNT) {
        repeat_count++;
    } else {
        flush_rle();
        last_event = event;
        repeat_count = 1;
    }
}

// ---- Port filter ----

// Add all ports matching (addr & mask) == (value & mask)
void add_port_filter(uint16_t mask, uint16_t value) {
    for (int addr = 0; addr < 1024; addr++) {
        if ((addr & mask) == (value & mask))
            port_bitmap[addr >> 3] |= 1u << (addr & 7);
    }
}

__force_inline bool port_match(uint16_t addr) {
    return port_bitmap[addr >> 3] & (1u << (addr & 7));
}

// ---- PSRAM init (from ide_analyzer.cpp) ----
// Based on eightycc's PSRAM gist with timing adapted for 370MHz
// Only works on boards with QMI PSRAM (e.g. Pimoroni Pico Plus 2)

static size_t psram_init(void) {
    gpio_set_function(PSRAM_CS_PIN, GPIO_FUNC_XIP_CS1);

    uint32_t save = save_and_disable_interrupts();

    // Initialize QMI in direct mode with slow clock for ID read
    qmi_hw->direct_csr = 30 << QMI_DIRECT_CSR_CLKDIV_LSB |
                         QMI_DIRECT_CSR_EN_BITS;
    while (qmi_hw->direct_csr & QMI_DIRECT_CSR_BUSY_BITS);

    // Exit QPI mode if stuck (0xF5 command)
    qmi_hw->direct_csr |= QMI_DIRECT_CSR_ASSERT_CS1N_BITS;
    qmi_hw->direct_tx = QMI_DIRECT_TX_OE_BITS |
                        QMI_DIRECT_TX_IWIDTH_VALUE_Q << QMI_DIRECT_TX_IWIDTH_LSB |
                        0xF5;
    while (qmi_hw->direct_csr & QMI_DIRECT_CSR_BUSY_BITS);
    (void)qmi_hw->direct_rx;
    qmi_hw->direct_csr &= ~QMI_DIRECT_CSR_ASSERT_CS1N_BITS;

    // Read PSRAM ID (0x9F command) - 12 bytes total
    qmi_hw->direct_csr |= QMI_DIRECT_CSR_ASSERT_CS1N_BITS;
    uint8_t kgd = 0, eid = 0;
    for (size_t i = 0; i < 12; i++) {
        qmi_hw->direct_tx = (i == 0) ? 0x9F : 0xFF;
        while (qmi_hw->direct_csr & QMI_DIRECT_CSR_BUSY_BITS);
        uint8_t rx = qmi_hw->direct_rx;
        if (i == 5) kgd = rx;
        if (i == 6) eid = rx;
    }
    qmi_hw->direct_csr &= ~QMI_DIRECT_CSR_ASSERT_CS1N_BITS;

    // Verify KGD (Known Good Die) = 0x5D for AP Memory PSRAM
    if (kgd != 0x5D) {
        qmi_hw->direct_csr = 0;
        restore_interrupts(save);
        return 0;
    }

    // Send initialization commands: RESETEN, RESET, QPI Enable, Wrap toggle
    uint8_t cmds[] = {0x66, 0x99, 0x35, 0xC0};
    for (int i = 0; i < 4; i++) {
        qmi_hw->direct_csr |= QMI_DIRECT_CSR_ASSERT_CS1N_BITS;
        qmi_hw->direct_tx = QMI_DIRECT_TX_OE_BITS | cmds[i];
        while (qmi_hw->direct_csr & QMI_DIRECT_CSR_BUSY_BITS);
        qmi_hw->direct_csr &= ~QMI_DIRECT_CSR_ASSERT_CS1N_BITS;
        for (int j = 0; j < 20; j++) asm("nop");
        (void)qmi_hw->direct_rx;
    }

    qmi_hw->direct_csr = 0;  // Disable direct mode

    // Configure QMI timing for 370MHz with CLKDIV=4 (92.5MHz PSRAM clock)
    qmi_hw->m[1].timing =
        QMI_M0_TIMING_PAGEBREAK_VALUE_1024 << QMI_M0_TIMING_PAGEBREAK_LSB |
        3 << QMI_M0_TIMING_SELECT_HOLD_LSB |
        1 << QMI_M0_TIMING_COOLDOWN_LSB |
        2 << QMI_M0_TIMING_RXDELAY_LSB |
        11 << QMI_M0_TIMING_MAX_SELECT_LSB |   // 8us / (10.81ns x 64) = 11
        5 << QMI_M0_TIMING_MIN_DESELECT_LSB |  // 50ns / 10.81ns = 5
        4 << QMI_M0_TIMING_CLKDIV_LSB;         // 370MHz / 4 = 92.5MHz

    // Read format: Quad mode, 6 dummy cycles (24 bits)
    qmi_hw->m[1].rfmt =
        QMI_M0_RFMT_PREFIX_WIDTH_VALUE_Q << QMI_M0_RFMT_PREFIX_WIDTH_LSB |
        QMI_M0_RFMT_ADDR_WIDTH_VALUE_Q << QMI_M0_RFMT_ADDR_WIDTH_LSB |
        QMI_M0_RFMT_SUFFIX_WIDTH_VALUE_Q << QMI_M0_RFMT_SUFFIX_WIDTH_LSB |
        QMI_M0_RFMT_DUMMY_WIDTH_VALUE_Q << QMI_M0_RFMT_DUMMY_WIDTH_LSB |
        QMI_M0_RFMT_DUMMY_LEN_VALUE_24 << QMI_M0_RFMT_DUMMY_LEN_LSB |
        QMI_M0_RFMT_DATA_WIDTH_VALUE_Q << QMI_M0_RFMT_DATA_WIDTH_LSB |
        QMI_M0_RFMT_PREFIX_LEN_VALUE_8 << QMI_M0_RFMT_PREFIX_LEN_LSB;

    qmi_hw->m[1].rcmd = 0xEB << QMI_M0_RCMD_PREFIX_LSB;  // Quad Read
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

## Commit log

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2022-07-31 PicoGUS hardware design
    [PicoGUS.kicad_pcb, PicoGUS.kicad_sch]
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2022-08-20 Use new reset logic latch circuit
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2022-08-28 Reroute power rails, start of MIDI/UART out
    [PicoGUS.kicad_pcb, PicoGUS.kicad_sch]
2022-08-28 Add MIDI port
    [PicoGUS.kicad_pcb, PicoGUS.kicad_sch]
2022-08-28 Add Schottky diode on VSYS
    [PicoGUS.kicad_pcb, PicoGUS.kicad_sch]
2022-08-28 Add IRQ2-4 to HW
    [PicoGUS.kicad_pcb, PicoGUS.kicad_sch]
2022-08-28 Update 3D models
    [CUI_DEVICES_SJ-3523-SMT-TR.step, CUI_DEVICES_SJ1-3535NG-BE.step, PicoGUS.kicad_pcb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]
2022-08-28 Schematic cleanup
    [PicoGUS.kicad_sch]
2022-08-28 Layout tweaks
    [PicoGUS.kicad_pcb, PicoGUS.kicad_sch]
2022-08-28 Add open collector for IOCHRDY
    [PicoGUS.kicad_pcb, PicoGUS.kicad_sch]
2022-08-28 Use mosfet instead
    [PicoGUS.kicad_pcb, PicoGUS.kicad_sch]
2022-08-28 Use 74LVC06 for IOCHRDY
    [PicoGUS.kicad_pcb, PicoGUS.kicad_sch]
2022-08-28 Use 74LVC244 for misc bus instead of TXS0108
    [PicoGUS.kicad_pcb, PicoGUS.kicad_sch]
2022-08-28 Update design
    [PicoGUS.kicad_pcb]
2022-08-28 Rearrange misc GPIOs for better PIO
    [PicoGUS.kicad_pcb, PicoGUS.kicad_sch]
2022-08-28 Invert DACK
    [PicoGUS.kicad_pcb, PicoGUS.kicad_sch]
2022-09-02 Use chamfered edge connector; part updates
    [PicoGUS.kicad_pcb, PicoGUS.kicad_sch]
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2022-09-07 New GPIO mappings
    [PicoGUS.kicad_pcb, PicoGUS.kicad_sch]
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2022-10-25 Add BOM and gerbers
    [PicoGUS-B_Cu.gbr, PicoGUS-B_Mask.gbr, PicoGUS-B_Paste.gbr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]
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2022-10-26 Update Pico manufacturer part number
    [bom.csv]
2022-10-26 Update bracket: remove OOS option, link 3D printable bracket
    [bom.csv]
2022-11-06 Add LCSC part #s to BOM
    [bom.csv]
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2022-12-14 World's silliest sample cache - fixes stuttering with intense 16-bit samples
2022-12-30 Remove incompatible PSRAM part for Digi-Key
    [bom.csv]
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2023-01-21 Add missing isa dma c file
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2023-02-21 Fixes for Tandy: base port read; firmware flashing
    [picogus.cpp]
2023-02-23 Revert "Larger DMA buffer"
    This reverts commit 6d9e65c7c08c64792f152cc65a32c53eba8bc49f.
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2023-02-25 added case insensitive opetion parsing, fixed usage, added some helpful output
2023-06-16 Add "PicoGUS on a stick" design for Hand386
    [BOM-PicoGUS.csv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]
2023-06-25 Update Hand386 hw design
    [PicoGUS Hand386.kicad_pcb, PicoGUS Hand386.kicad_sch]
2023-07-01 Prototype PicoGUS Hand386 produced on 2023-06-30
    [BOM-PicoGUS Hand386.csv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]
2023-07-01 Add Hand386-to-ISA adapter
    [CUI_DEVICES_SJ-3523-SMT-TR.step, CUI_DEVICES_SJ1-3535NG-BE.step, ISA adapter.kicad_sch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]
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2023-07-01 fixed DMA interval parameter usage and check
2023-07-03 Prototype ISA adapter produced on 2023-07-01
    [BOM-ISA adapter.csv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]
2023-07-03 HW v1.1.1 - sync BOM, iBOM, schematic, PCB, and gerbers
    [PicoGUS-B_Cu.gbr, PicoGUS-B_Mask.gbr, PicoGUS-B_Paste.gbr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]
2023-07-29 ISA adapter v1.1/Hand386 PicoGUS v1.0
    [BOM-ISA adapter.csv, BOM-PicoGUS Hand386.csv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]
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2023-08-07 Hand386 version and ISA adapter fabbed at JLC 7/29
    [ISA adapter bracket v4.step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]
2023-08-26 Hand386 version and ISA adapter fabbed at JLC 8/25
    [BOM-ISA adapter.csv, BOM-PicoGUS Hand386.csv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]
2023-09-12 Revert "64k DMA sample cache" - it doesn't help
    This reverts commit 4a8edab7151bfa56289962485c0cdfb7d985d54e.
    [picogus.cpp]
2023-10-07 v1.3 of Femto edition submitted to JLCPCB 2022-09-26
    [BOM-PicoGUS Hand386.csv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]
2023-11-07 PicoGUS v1.2 prototype fabbed at JLCPCB 2023-10-25
    [PicoGUS.kicad_pcb, PicoGUS.kicad_sch]
2023-11-07 Fix for Gateway, will enable w/ settings later
    [mpu401.c]
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2023-11-07 Chip-down PicoGUS v2.0 prototype, assembled at JLCPCB 2023-09-25
    [PicoGUS chipdown.kicad_sch, RP2040.kicad_sch, audio.kicad_sch]
2023-11-07 Add metal bracket model
    [picogus 2.0 sheet metal bracket.step]
2023-11-07 Almost final PicoGUS 2.0
    [PicoGUS chipdown.kicad_sch, RP2040.kicad_sch, audio.kicad_sch]
2023-11-07 PicoGUS v2.0 produced at JLCPCB 2023-10-23
    [CUI_DEVICES_SJ-3523-SMT-TR.step, CUI_DEVICES_SJ1-3533NG.step, CUI_DEVICES_SJ1-3535NG-BE.step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]
2023-11-07 PicoGUS v2.0 produced at JLCPCB 2023-10-24 - previous submission had awful errors
    [PicoGUS chipdown with edge rails-B_Cu.gbl, PicoGUS chipdown with edge rails-B_Mask.gbs, PicoGUS chipdown with edge rails-B_Paste.gbp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]
2023-11-07 Try different PSRAM strategy if the default fails
    [picogus.cpp]
2023-11-14 Delay overclock for board to stabilize. Needed for PicoGUS 2.0 final board!
    [picogus.cpp]
2023-11-14 Fixes for MPU401 re-init
    [mpu401.c, picogus.cpp]
2023-11-14 Fixes to run without USB joystick support
    [cmsplay.cpp, picogus.cpp]
2023-11-15 Detect board type on Pico W; fix test for BOARD_TYPE
    [picogus.cpp]
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2023-11-16 Better startup stability for PicoGUS 2.0 boards
    [picogus.cpp]
2023-11-16 3d printed 2.0 bracket, JLCPCB BOM/CPL files
    [BOM-PicoGUS chipdown.csv, picogus 2.0 3D printed bracket.stl, picogus 2.0 sheet metal bracket.step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]
2023-11-29 PicoGUS v1.2 release candidate fabbed at JLCPCB 2023-11-26
    [PicoGUS.kicad_pcb, PicoGUS.kicad_sch]
2023-12-14 PicoGUS hardware v1.2 final
    [BOM (DAC module).csv, BOM (integrated DAC).csv, BOM-PicoGUS.csv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]
2023-12-14 Add hw 1.x changelog, cleanup
    [BOM-PicoGUS.csv, PicoGUS.kicad_sch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]
2024-01-04 Add STL files for Femto edition case
    Design is courtesy (c) FireTwoOneNine.
    [picogus_hand_bottom_v2.STL, picogus_hand_top_v2.STL]
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2024-01-15 Increase CLKDIV for IOW because 5170 doesn't have valid data for 30ns
    [picogus.cpp]
2024-01-15 Drive DRQ and IRQ harder to get shared lines or older boards to behave better
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2024-03-24 Init MPU asynchronously to avoid holding IOCHRDY
    [mpu401.c, picogus.cpp]
2024-03-26 Proof of concept / Initial Commit.
    This does not work and is a work in progress.
    [picogus.cpp, sbplay.cpp]
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2024-03-26 reset routine to only look at LSB
    [sbplay.cpp]
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2024-03-26 Fire IRQ during timer ISR for less jitter
    [sbdsp.cpp]
2024-03-26 Fix issues in pgusinit interface
    [picogus.cpp]
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2024-04-27 Implementation of multi-firmware for PicoGus.
    Flash only one file: pg-multi.uf2 only one time. It contains all firmwares (6 at this moment). You can change between them in DOS:
    New usage for this version:
    pgusinit /m x [d] - change card mode to x (1=gus,2=sb,3=mpu,4=tandy,5=cms,6=joy)
    the optional parameter 'd' makes the mode permanent at boot
    (Only if pg-multi.uf2 is flashed)
    Examples of use:
    You have default mode as GUS mode on boot, want to change mode to SB, but only temporarily:
    pgusinit /m 2
    You want to change the default (permanent) mode of the card to SB mode, and the next system cold boots / hard resets / power of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
    [picogus.cpp]
2024-06-05 Update emu8950.c
    Fix bug where attack step 0 for eg_rate_h 15 causing envelop never switch to decay, causing some music missing notes in higher notes.
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2024-06-30 Updates to femto & ISA adapter for mid-2024 batch
    [BOM-ISA adapter.csv, BOM-PicoGUS Hand386.csv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]
2024-06-30 Add missing hw files
    [audio.kicad_sch]
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2024-07-07 Fix saving current boot mode; cleanup
    [picogus.cpp]
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2024-07-07 Fix bool option setting and add xinput driver install callback
2024-07-08 Remove release script - it's currently all done in CMake and GH Actions
2024-08-23 Avoid throttle down by using picow_fast board def
2024-10-26 SB: Fix Tyrian and Dig-It! by implementing DSP_DAC_PAUSE_DURATION
    [sbdsp.cpp]
2024-11-23 Fix STMIK's wonky SB detection
    [sbdsp.cpp]
2024-11-23 Fix setting port numbers to less than 0xff or ending with 0x00
    [picogus.cpp]
2024-11-26 Refactor events for less jitter
    [cmsplay.cpp, gusplay.cpp, mpu401.c]
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2024-12-04 Drop flash_safe_execute_core_init as it interferes with cyw43
    [cmsplay.cpp, gusplay.cpp, sbplay.cpp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]
2024-12-09 Temporarily use develop branch of Pico SDK to bring in timer fix
    Fixes issue introduced in SDK 2.1.0, reported in pico-sdk issue 2118:
    https://github.com/raspberrypi/pico-sdk/issues/2118
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2025-06-16 Fix slow/missing note OPL2 playback on complex songs
    [picogus.cpp, sbplay.cpp]
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2025-06-19 Fix MIDI output in SB and USB modes
    [sbplay.cpp, usbplay.cpp]
2025-06-22 Many fixes/improvements to CD image handling:
    - Fix memory leak when changing images (file handle not freed)
    - Longer max file length limit (127 chars)
    - Better errors when USB not present
    - Fix polling of CD status register when listing images
    - Add ability to load image by name
    - Many weird edge cases with image loading state fixed
    [picogus.cpp]
2025-07-01 Volume control tighten up
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2025-07-04 Print status functions
    More clean up to main(). I am finding there is some overlap with the term "mode" which indicates the global card mode (ex. SB_MODE, GUS_MODE, etc) as well as register modes communicating with PicoGUS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
2025-07-08 Fix printUSBMode() typo
2025-07-14 Initialize with set_volume()
    Restores volume settings with mode changes and resets.
    [psgplay.cpp, sbplay.cpp]
2025-08-07 pgusinit quality of life improvements:
    Restoration of prior pgusinit functionality:
    - Case insensitive command line switches
    - Bail out if there are errors detecting the card
    - Bail out on firmware mismatch, but allow flashing new firmware
    More QoL improvements:
    - Generic paging interface that detects rows on screen
    - /? and /?? are paged
    - /cdlist uses new paging interface
2025-08-09 Fix DC offset in 8-bit unsigned to 16-bit signed conversion
    [sbdsp.cpp, sbplay.cpp]
2026-03-17 "Pull" based DMA for SB - doesn't require DMA interval dithering
    [sbdsp.cpp, sbplay.cpp]
2026-03-18 SB: fix SBPro stereo mode
    [sbdsp.cpp]
2026-03-18 try to prevent pops in single-cycle mode
    [sbdsp.cpp]
2026-03-18 SB: rewrite sbdsp_generate_sample()
    fixes single-cycle DMA transfer clicking, GoldPlay and DSP "nagging" hacks, also implicitly caps sampel rate to 44100 Hz at this moment
    [sbdsp.cpp]
2026-03-19 SB: speaker control should only mute output and do not stop DMA
    (fixes Scream Tracker 3)
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2026-03-20 SB: implement DSP command 0x42 (Set Recording Sample Rate)
    (equivalent to 0x41 on real SB16, fixes Fast Tracker 2)
    [sbdsp.cpp]
2026-03-21 SB: mixer locking and time constant fixup options
    [sbdsp.cpp]
2026-03-21 SB: add registers for setting DSP version, IRQ/DMA settings readback and emulation options
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2026-03-21 fix SB types and erratic fallthrough in CMD_SBDMA
    [picogus.cpp, sbdsp.cpp]
2026-03-21 SB: clock down DMA PIO, minor sbdsp_set_type() fix
    [sbdsp.cpp]
2026-03-21 SB: reset more stuff, fix TC-related oversight
    [sbdsp.cpp]
2026-03-23 SB: move dsp_process() to second core, tweak DSP reset procedure
    [picogus.cpp, sbdsp.cpp, sbplay.cpp]
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2026-03-23 SB: remove wait for DACK deassertion in dma_write_multi
    (makes it work in DMA controller demand mode - fixes Unreal/FC in SBPro mode)
2026-03-25 fix DMA multi PIO state machine
2026-03-25 SB: fix reentrancy issues
    [picogus.cpp, sbdsp.cpp]
2026-03-28 Revert "temp overclock UART to 2 Mbps"
    This reverts commit 0e88976b60c6c8cca25c8f637c6c0056444174a3.
2026-03-28 pgusinit: add option to init GUS/SB mode reosurces (base port, IRQ, DMA) from ULTRASND/BLASTER environment variable.
2026-03-28 Fix CD-ROM Red Book audio distortion and buffer gaps
    Several bugs caused CD audio to crackle, distort, and stutter when a USB HID device was connected.
    usbplay.cpp, psgplay.cpp: Switch take_audio_buffer() from blocking to non-blocking with a tuh_task() poll loop, matching the existing pattern in gusplay.cpp. Add 500ms boot-time USB pump. Prevents TinyUSB keep-alive timeouts from colliding with audio DMA fills.
    sbplay.cpp: Remove private cd_index and opl_out_index static cursors in the PWM IRQ handler. Both were decoupled from their FIFO's read_idx and drifted after any fifo_reset() (seek/pause/stop), causing stale/out-of-order sample reads. Now reads directly from fifo->buffer[fifo->read_i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
    [psgplay.cpp, sbplay.cpp, usbplay.cpp]
2026-03-28 cdrom: USB/FAT stability fixes
    Fixes three reliability issues in msc_app.c:
    Add 2-second timeout to wait_for_disk_io() to prevent firmware lockup when a USB drive stops responding mid-transfer
    Propagate SCSI errors from disk_io_complete() — disk_read()/disk_write() now return RES_ERROR on failure instead of always returning RES_OK
    Guard tuh_msc_umount_cb() against a second MSC device disconnect tearing down the active drive's filesystem
2026-03-28 sbplay: cap OPL fill loop to 256 samples per iteration
    Prevents cdrom_tasks() from being starved when the OPL FIFO is nearly empty. The 4096-sample FIFO (~93ms) provides sufficient headroom to absorb the capped fill rate without risk of OPL underrun.
    [sbplay.cpp]
2026-03-28 cdrom/mke: DOS protocol correctness fixes
    Seven correctness fixes across cdrom.c and mke.c:
    cdrom_status(): initialize status to 0 to prevent random stack bits in the status byte sent to DOS
    cdrom_disc_capacity(): guard ti.f - 1 against uint8 underflow when frame is 0
    CMD1_READ_VER: pad response to 12 bytes as expected by SBPCD driver
    CMD1_GETMODE: set data mode byte to 0x01 (Mode 1) instead of 0x00
    CMD1_ABORT: clear full command buffer (bytes 0–6), not just byte 0
    CMD1_READSUBQ: move cdrom_fifo_clear() to before the subchannel read, not after
    CMD1_READTOC: check return value of cdrom_read_toc() before writing to FIFO
2026-03-28 fix(cdrom): recover from error state on /cdlist; fix image path edge cases
    CMD_CDLIST now queues image list when status is ERROR, not just IDLE,
    fixing permanent stuck state after a failed /cdload or /cdloadname
    isCDImage: fix len<=4 guard so ".iso"/".cue" are rejected; hide all
    dot-files instead of only macOS ._-prefixed files
    Replace strcpy with strncpy for image_path to prevent buffer overrun
    [picogus.cpp]
2026-03-28 fix(cdrom): fix audio track seek offsets in CUE images without INDEX 00
    When a CUE track has no INDEX 00 (no explicit pregap), prestart was
    left at 0, causing skip = cur->start - 0 = full absolute frame position.
    This made cdi_add_track compute a negative (wrapping) prev->length and
    corrupted skip offsets for all subsequent tracks.
    Fix: track whether INDEX 00 was actually seen per-track (has_prestart).
    When absent, pass trk.start as prestart so skip computes to 0. Affects
    all three cdi_add_track call sites in cdi_load_cue. CUEs with INDEX 00
    are unaffected.
2026-03-28 feat(opl): widen OPL pipeline to int32_t for clean gain and precision
    Replace the int16_t intermediate in the OPL output path with int32_t
    throughout: emu8950 mix_output_raw, OPL_calc_buffer, OPL_Pico_simple,
    and get_opl_sample.
    Remove the >> 1 attenuation in _MO() that was required to prevent
    int16_t overflow on multi-channel sums. This eliminates 1 bit of
    permanent precision loss per channel sample.
    Use int64_t intermediate in scale_sample() to prevent int32_t overflow
    when opl_volume is boosted above 1.0x (was undefined behaviour at high
    volumes with the old approach).
    Apply a 6x OPL gain constant in CMD_OPLVOL to compensate for the
    removed attenuation and provide comfortable headroom.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
    [sbplay.cpp]
2026-03-28 opl: enable EMU8950 TLL via pre-computed table in flash (.flashdata section)
    The TLL (Total Level Lookup) table is 128KB — too large for the RP2040's
    256KB RAM when the firmware also runs code from RAM. Previous attempts to
    use a `const` array failed because the firmware uses a copy_to_ram binary
    type, which copies ALL sections including `.rodata` into RAM at boot.
    The fix: place the pre-computed table in the `.flashdata.tll_table` linker
    section. Both pico-sdk's `memmap_copy_to_ram.ld` and the local
    `fw_memmap_c2ram.ld` explicitly capture `.flashdata*` into the FLASH
    `.rodata` region, which is accessed via XIP cache and never copied to RAM.
    - gen_tll_table.py: new script that pre-comput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
2026-03-28 fix(opl): fix OPL Timer 2 enable writing to timer1.enabled instead of timer2.enabled
    In OPL_Pico_WriteRegister(), the register 0x04 (TIMER_CTRL) handler
    had a copy-paste error in the Timer 2 enable path: it wrote the Timer 2
    start bit (0x02) into timer1.enabled instead of timer2.enabled.
    This meant timer2.enabled was always 0, so OPLTimer_CalculateEndTime()
    never set timer2.expire_time, and the status register port read never
    set bit 5 (Timer 2 expired). The bug also had a secondary effect:
    writing 0x22 (enable Timer 2) would accidentally re-enable timer1.
    The canonical OPL detection sequence used by the Doom engine and many
    other DOS titles tests both timers — it expects bit 6 (Timer 1)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
2026-03-28 fix(opl): eliminate cross-core OPL struct race via OPL_CMD_BUFFER
    This was an audible in games like Doom. It would cause an occasional small interruption when picking up items.
    Core 0 (bus ISR) was calling OPL_writeReg() directly on the emu8950
    OPL struct while Core 1 was simultaneously reading it in OPL_calc_buffer()
    to generate audio. With no synchronization between the cores, a register
    write landing mid-calculation produces torn state — a mix of old and new
    operator fields — causing occasional clicks or pops during OPL music.
    The OPL_CMD_BUFFER mechanism was already implemented in picogus.cpp and
    sbplay.cpp but never enabled. Enable it in CMakeLists.txt for all OPL
    targets (pg-adli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
    [picogus.cpp]
2026-03-28 fix(audio): fix samples_in_fifo race between core 1 main loop and PWM ISR
    fifo_add_sample() increments samples_in_fifo with a non-atomic
    load-add-store. The PWM ISR (audio consumer) runs on the same core
    and can preempt the main loop (OPL producer) between the load and
    store, decrementing the counter mid-update. The ISR's decrement is
    then overwritten by the main loop's store, inflating samples_in_fifo
    by 1. Over time this drift could cause the producer to throttle itself
    early or the consumer to read a stale sample.
    Wrap the increment and start-threshold check in fifo_add_sample() with
    save_and_disable_interrupts()/restore_interrupts(). The IRQ disable
    window is minimal (~4 cycles) and onl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
2026-03-28 fix ymfm register writes, use linear OPL3 output resampling
    [sbplay.cpp]
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2026-03-29 OPL3 fixes for SB16
    [picogus.cpp, sbplay.cpp]
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2026-03-29 Overclock at runtime instead of at start to help stability on marginal boards
    [gusplay.cpp, picogus.cpp, sbplay.cpp]
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2026-03-31 Fix Miles AIL detection of SB16
    [sbdsp.cpp]
2026-04-01 SB: add missing DSP_CONTINUE_DMA_16 (0xD6) command and fix names of other DMA pause/continue commands
    [sbdsp.cpp]
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2026-04-10 fixed typo that passes irq instead of DMA
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2026-04-14 SB: general SBDSP fixes
    [sbdsp.cpp]
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2026-04-14 CDROM: Fix .iso in Win9x w/ MKEPanasonic driver by handling lead-out
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2026-04-17 Fix printf panic in GUS mode
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2026-04-18 Fix GUS playmidi - it uses both timers
2026-04-18 Fix printf usage in ne2000 firmware
2026-04-20 SB: Fix clicks during single-cycle DMA playback
    [sbdsp.cpp]
2026-10-29 GUS: Don't clear pgusinit DMA interval override on guest reset
    GUSReset() is for resetting the emulated gus state, not override values
    that are handled by pgusinit
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2026-10-29 GUS: Refuse unsupported GUS->host DMA requests
    This would get the PIO SM stuck since the DMA direction control bit is ignored.
2026-10-30 GUS: Release IRQ pin when mix control disables the IRQ latches
    I can't think of a program that this would actually affect, but adding
    this for correctness's sake.
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2026-10-30 GUS: Fix swapped DMA rate divider bits
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2026-11-01 GUS: Apply ramp increments based on GF1 frames
    LPC-GUS's gf1.v shows the GF1 adds the whole ramp increment to the 12-bit
    volume on frames based on a rate divider. This adds a frame counter and
    advances it every GUS frame (when in fixed 44.1khz output mode, it has to
    use an accumulator to determine when the GUS frame is).
    This winds up being more accurate to the GF1 and also a little bit more
    efficient on average.
    Also fixes an issue where a stopped ramp would not repeatedly trigger IRQ
    like a real GF1.
2026-11-01 Fix SB DMA transfers getting out of phase: flipped stereo on SBPro or garbage sounding audio on SB16
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2026-11-03 MPU: Make reset behave like a real MPU-401
    Mainly exists to fix Gateway and its buggy driver:
    - Don't clear bus data on reset (the real MPU-401 keeps it in a gate
    array that doesn't get reset)
    - Delay ~33ms during UART mode reset and drain TX fifo during that delay.
2026-11-03 MPU: Account for sequencer ticks while a data request is outstanding
    Fixes too-slow tempo in Gateway and probably other Legend entertainment titles.
    A real MPU-401 keeps counting ticks in its timer ISR while the host answers a
    data request, and the main loop catches up afterwards.
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2026-11-04 Use cross-core aware read8/write8 in the DRAM peek/poke commands
    Fixes Hocus Pocus with the version of Ultramid that it ships with - it polls
    the DRAM peek command (the GUSDK's gf1_delay() does this) at the same time as
    DMAing new sound effect samples.
2026-11-04 Save IRQ cycles during DMA when the interval is 1 by triggering DRQ immediately
    This prevents sound stuttering in Hocus Pocus now that it uses the cross-core
    aware PSRAM write functions, and probably other titles that do streaming audio.
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

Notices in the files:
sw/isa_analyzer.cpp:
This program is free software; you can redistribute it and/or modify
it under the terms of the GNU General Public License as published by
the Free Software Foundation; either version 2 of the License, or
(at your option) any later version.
